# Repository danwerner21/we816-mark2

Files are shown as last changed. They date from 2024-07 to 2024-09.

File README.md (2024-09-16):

# WE816-MARK2
The WE816-MARK2 is the second iteration of a 16-bit 65816 based system with 512K of System RAM, 96K of System ROM, a Raspberry PI Pico based graphics processor and an AY-3-8910 Sound chip.  The system runs a custom version of BASIC and supports commodore compatible IEC disk drives.

EhBASIC by Lee Davison was ported to the 65816 CPU on the WE816 computer.   It is designed to allow a full 64K bank for BASIC code and variables with the BASIC interpreter running in a totally different bank. Full documentation on the basic intrepreter can be found in the support folder

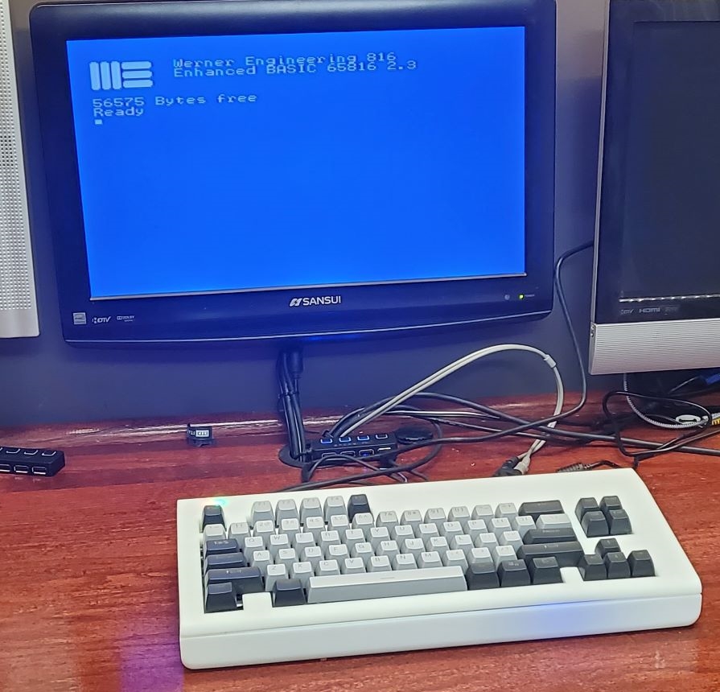
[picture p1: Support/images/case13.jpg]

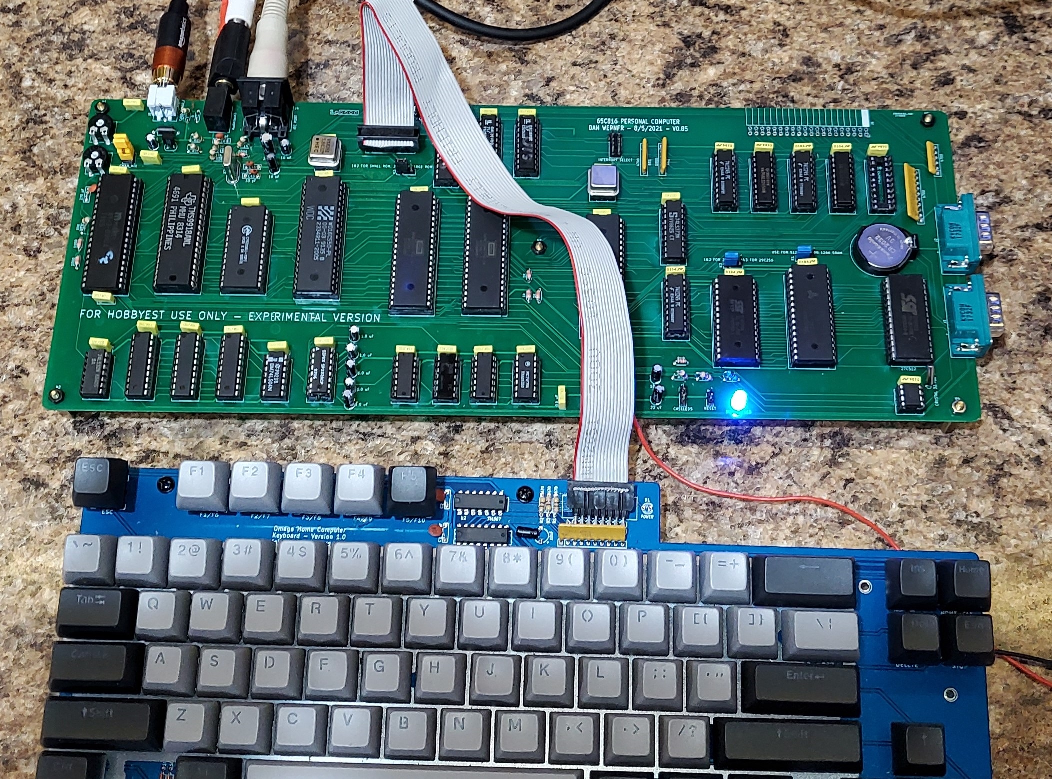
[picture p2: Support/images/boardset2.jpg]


---

## Bugs:
* V0.08 board
        U13 should be a 22V10 rather than a 20V8  (no patches required)
        U31 should be 74ALS245 rather than 74AC245 (no patches required)
        The Footprints for the expansion(J7) and Keyboard(J3) connectors are wrong -- special cables are required to connect this version to keyboard and expansion
        RTC IS STILL BROKEN, DO NOT POPULATE U7,U8,X3,C36,C37,C34,R1,R2,R3,U9,BT1,K4,JP1, & JP2

* V0.9 board
        U16 should not be populated -- the wait state generator is not functional, maximum successful tested clock speed is 2.4576 Mhz
        Higher CPU speeds are possible, but the video will not function at much beyond this speed.

## To Do:
* Document Jumper Settings
* Document IO Ports
* Memory Map
* Video speed is not fast enough to deal with a clock speed > (around) 2mhz (2.4576 works perfectly)  Need to add wait state hardware for video
* Add Pictures to this Document
---

## What is included in this repo?
As of this time, the repo includes

1. The WE816-Mark2 Mainboard PCB Kicad design and Gerber files
2. The source code and binaries for the WE816 BASIC interpreter
3. The source code and binaries for the WE816 BIOS firmware
4. The source code and binaries for several hardware test programs
5. The logic equasions for the 4 GALs
6. **OpenSCAD and STL files for a 3d printed case
7. The Firmware for the Raspberry Pi Pico Video  

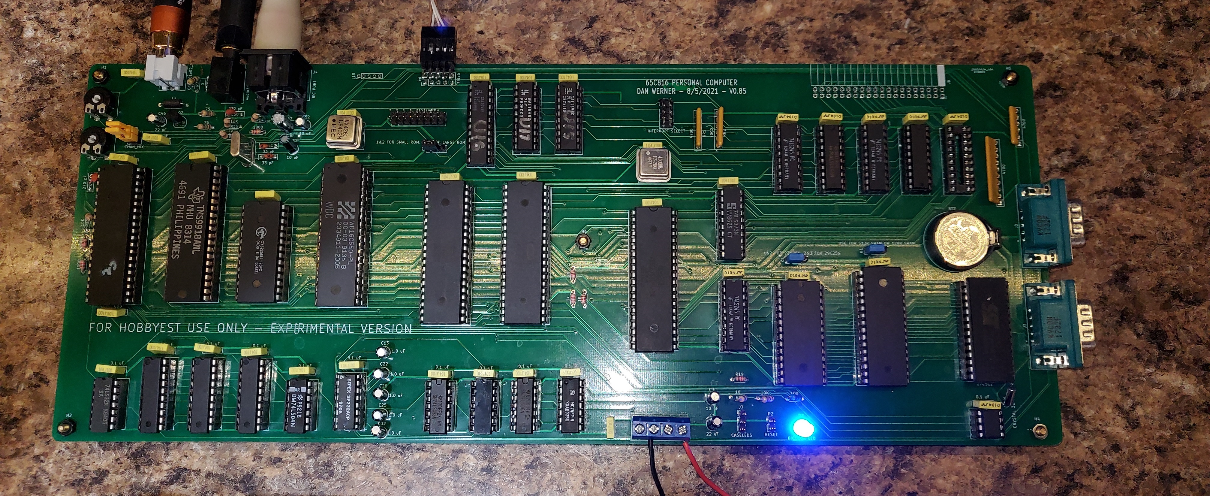
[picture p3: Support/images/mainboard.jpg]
Mainboard

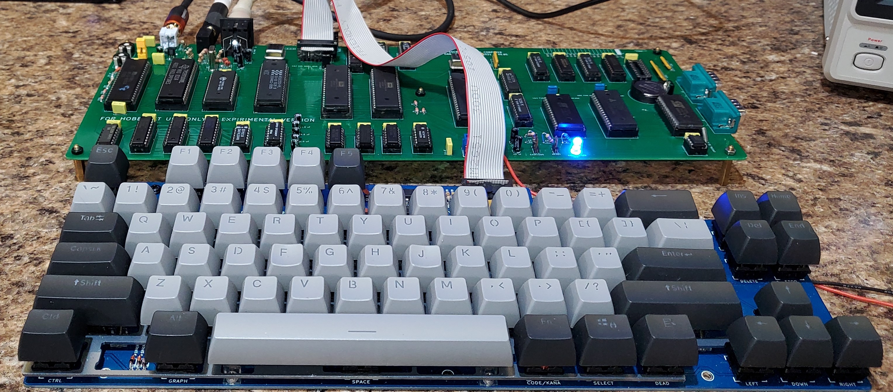
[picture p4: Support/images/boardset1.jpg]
Assembled


---

## Known Bugs

### System Jumpers

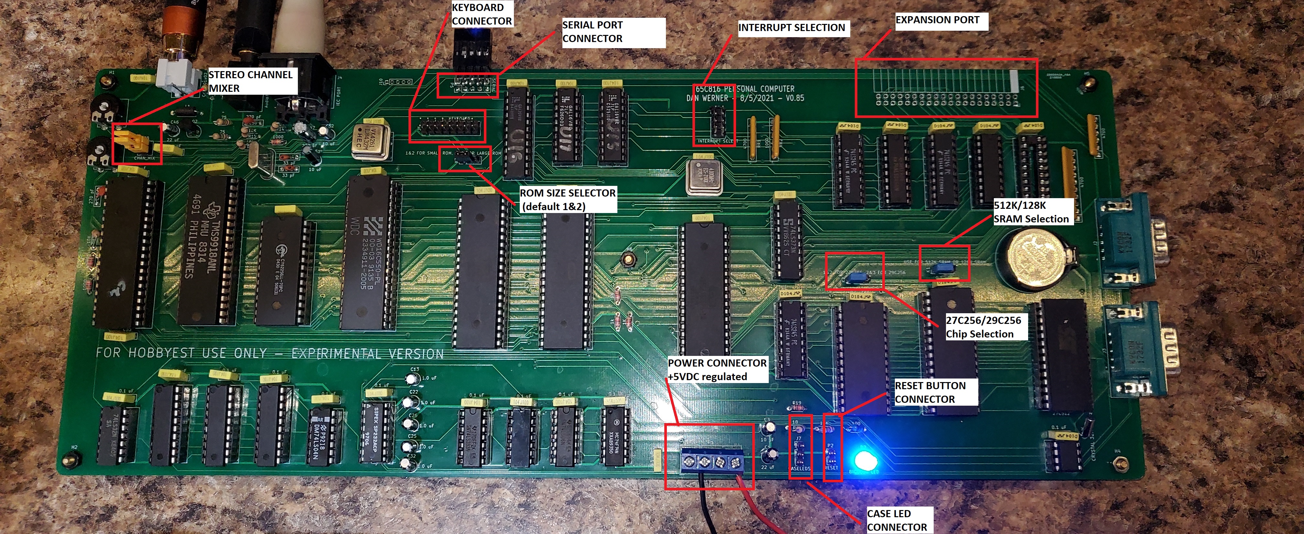
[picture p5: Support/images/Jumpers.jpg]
jumpers


Jumper P9 -- stereo channel mixer

 *  no jumpers, channel a left, channel c right, channel b left and right
 *  1-2 and 2-3 , channel a,b,c mixed to left and right

Jumper K1 - SRAM chip selection

 * 1&2 - 512K chip used (AS6C4008)
 * 2&3 - 128K chip used (AS6C1008)

Jumper K2 - ROM chip selection

 * 1&2 - 27c256 chip used
 * 2&3 - 29c256 chip used

Jumper K3 - ROM size

 * 1&2 - 16K rom page 0 memory map @ $C000
 * 2&3 - 32K rom page 0 memory map @ $8000

Power P1

 * 1- NC
 * 2-GND
 * 3-GND
 * 4-+5VDC 2A Regulated

Reset P2

 * NO Switch (Short to put system in reset)

Jumper J1, Interrupt Select

* 1&8 UART Interrupt enabled
* 2&7 VIA 1 Interrupt enabled
* 3&6 VIA 2 Interrupt enabled
* 4&5 TMS9918 Interrupt enabled

interrupt

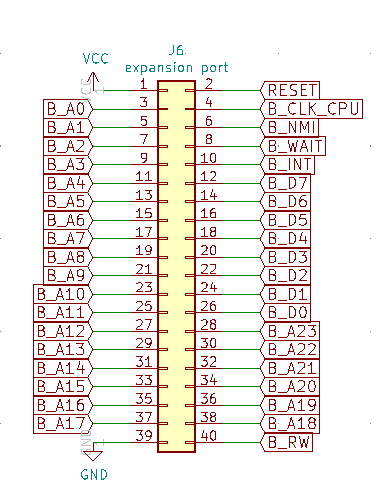
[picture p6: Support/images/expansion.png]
expansion


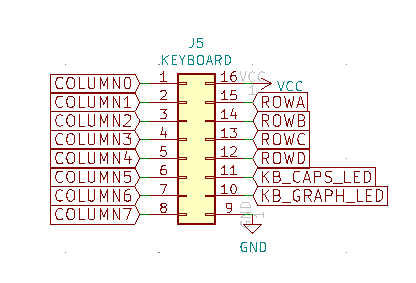
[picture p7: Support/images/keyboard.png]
keyboard


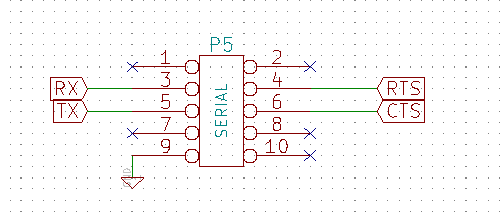
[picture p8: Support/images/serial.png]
serial


---

## Video Programming
IO PORTS

Address|Description|Value|Value
--------|--------|----------|--------
$fe30 | Scan Line Emulation | on | off
$fe31 | Display Page | page 0 | page 1
$fe32 | character generator write offset | write offset |
$fe33 | character generator write | Value |
$fe34 | device command  | Command |
$fe35 | Text Mode  | on | off
$fe36 | Lores Mode  | on | off
$fe37 | Double Lores Mode (must be in lores first)  | on | off
$fe38 | Hires Mode | on | off
$fe39 | Double Hires Mode (must be in hires first)  | on | off
$fe3A | 80 Col Mode (must be in text mode)  | on | off
$fe3b | Mixed Mode   (must be in lores/hires first) | on | off
$fe3c | Quad Hires  (must be in hires first) | on | off
$fe3d | Mono Hires  (must be in hires first)| on | off

## Bill Of Materials

### Mainboard

Qty|Reference(s)|Value
--------|--------|----------

### Keyboard
The Keyboard used in the WE816 is identical to the keyboard used in Sergey Kiselev's MSX compatible OMEGA computer.  See the Schematics, PCB layout and build instructions
[here](https://github.com/skiselev/omega/blob/master/Keyboard.md)

### Case
The case in the following images is a 3D print manufactured by the 3D print service offered by JLCPCB.com.  The case was originally designed to be 3D printed by a FDM printer such as the Anycubic Chiron.   It was originally intended that threaded inserts be melted into the stand off posts so the diameter of the holes were sized accordingly.  If a printing service (such as JLCPCB) is used that uses resin printing, it is necessary to slightly drill out the holes in the stand offs so that threaded inserts can be glued in.   It should also be noted that the design tolerances are quite tight and variations in printing can mean that some slight adjusting may be needed in order to get a good fit.

A 12V to 5V converter can be seen in the image that was added into the case in order to convert the 12V power input to the 5B required by the main board.

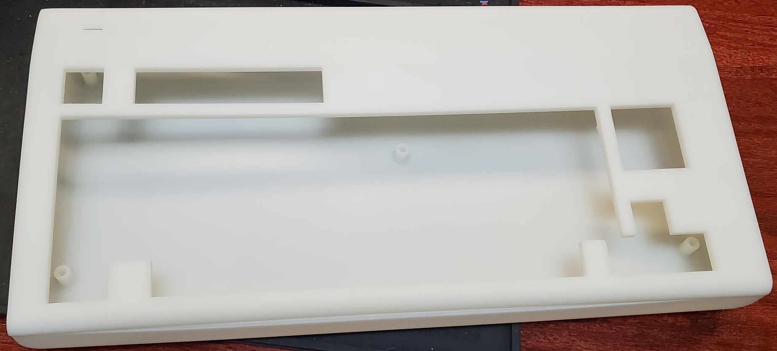
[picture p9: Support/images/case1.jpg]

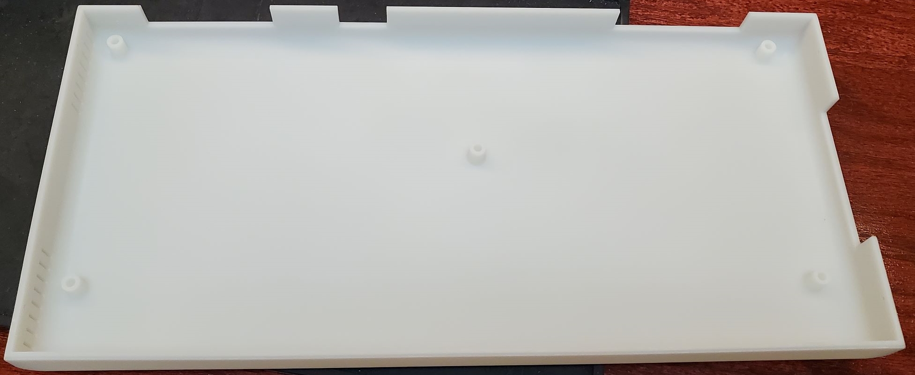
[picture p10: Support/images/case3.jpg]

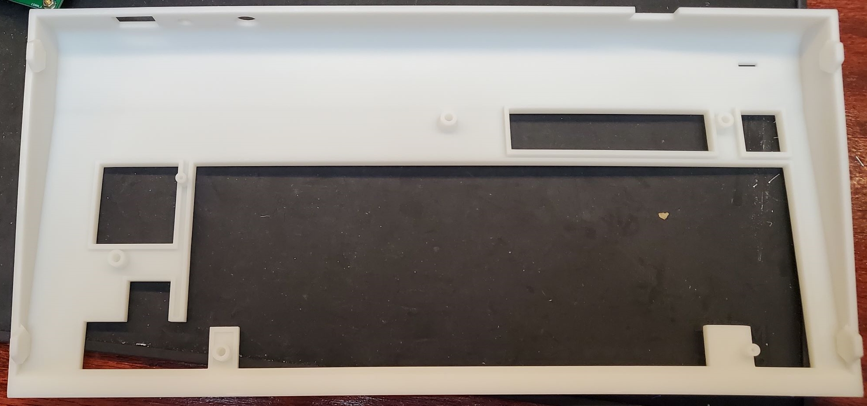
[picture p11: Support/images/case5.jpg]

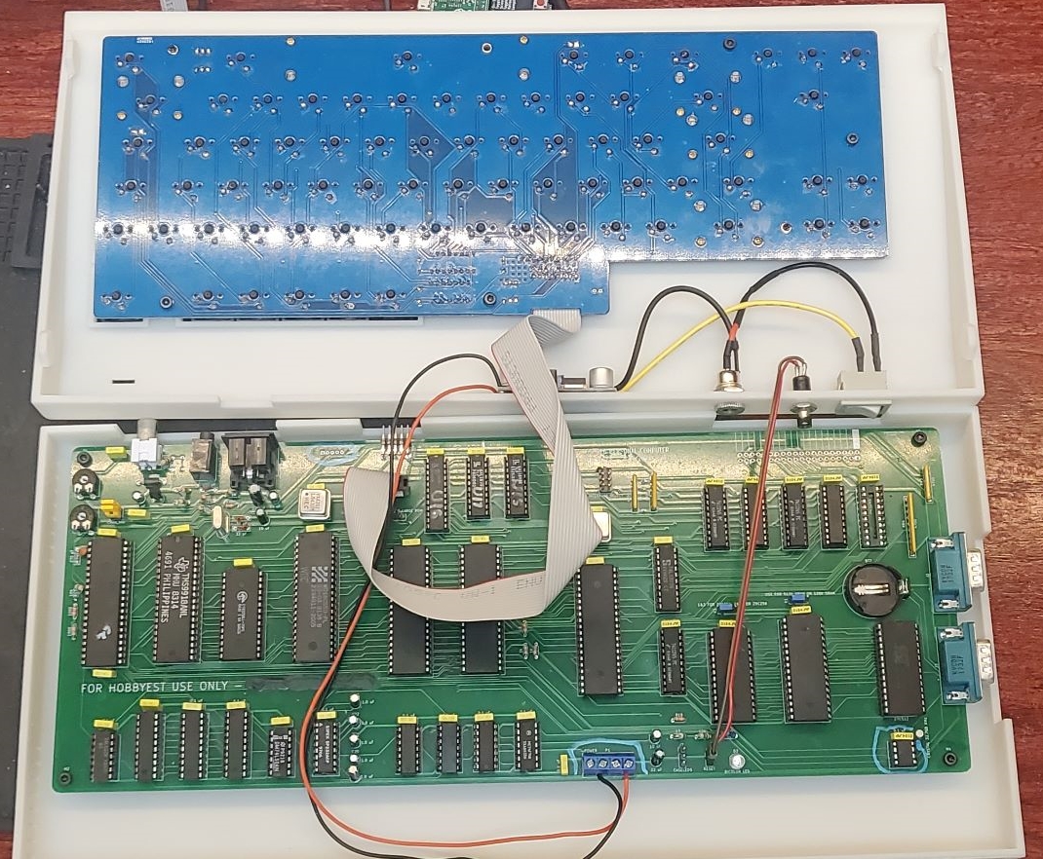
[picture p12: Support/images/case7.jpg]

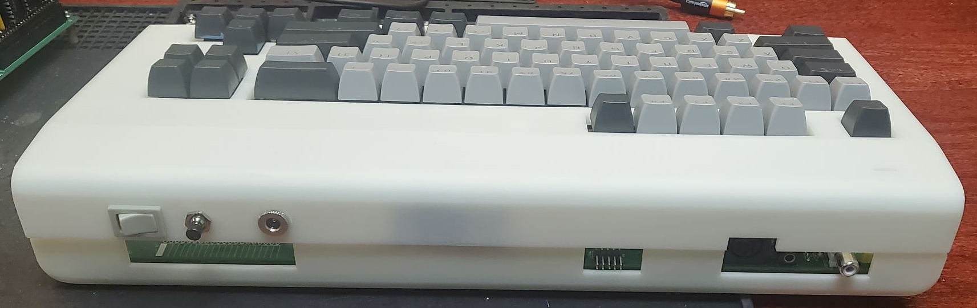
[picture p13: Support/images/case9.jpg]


### Questions?

If there are any questions, I can be reached at vic2020Dan at gmail dot com.

---

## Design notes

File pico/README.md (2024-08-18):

## This work is derived from the AppleII VGA project located here: https://github.com/markadev/AppleII-VGA
## Many thanks to Mark Aikens and David Kuder for their work on this project

# Set Up Raspberry Pi Pico SDK and build the firmware

## Windows Subsystem for Linux (WSL)
Windows Subsystem for Linux (WSL) allows you to install a complete Ubuntu terminal environment in minutes on your Windows machine, allowing you to develop cross-platform applications without leaving Windows. [Install Ubuntu on WSL for Windows](https://ubuntu.com/tutorials/install-ubuntu-on-wsl2-on-windows-10#1-overview)

## Install development packages
```shell
sudo apt update
sudo apt install -y build-essential git cmake gcc-arm-none-eabi
```

## Download the Pico SDK
```shell
git clone https://github.com/raspberrypi/pico-sdk.git ~/pico-sdk
git -C ~/pico-sdk submodule update --init
export PICO_SDK_PATH=~/pico-sdk
```

## Build the firmware 
```shell
cd pico
mkdir build
cd build
cmake  ..
make
## Install the firmware
Hold down the BOOTSEL button and connect the Raspberry Pi Pico to your PC via micro USB cable. Once Pico is
connected release the BOOTSEL button. Pi Pico should be connected to PC with USB mass storage device mode.

A disk volume called RPI-RP2 will appear on your computer. Drag and drop the applevga.uf2 file to that volume.
RPI-RP2 will unmount and Pico will start the program.

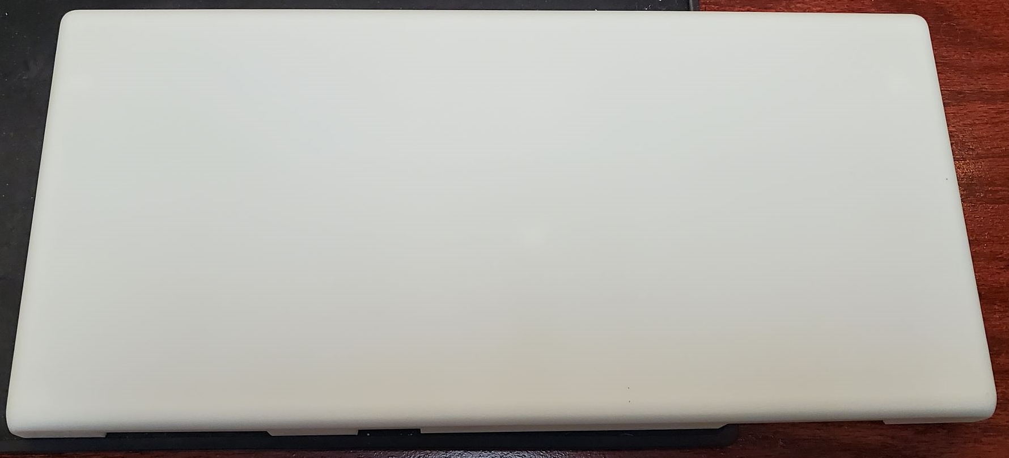
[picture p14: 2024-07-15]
Support/images/case4.jpg

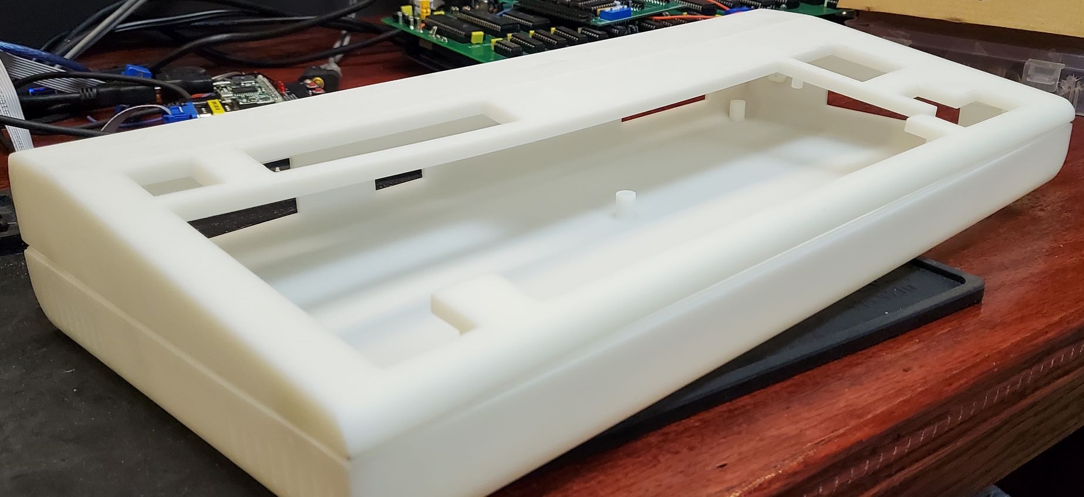
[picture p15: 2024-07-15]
Support/images/case2.jpg

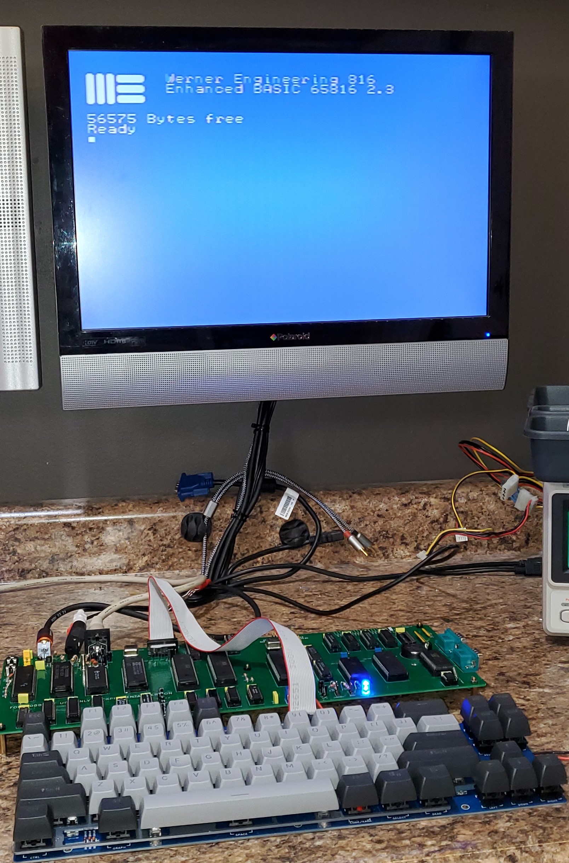
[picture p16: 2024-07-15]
Support/images/bare_system.jpg

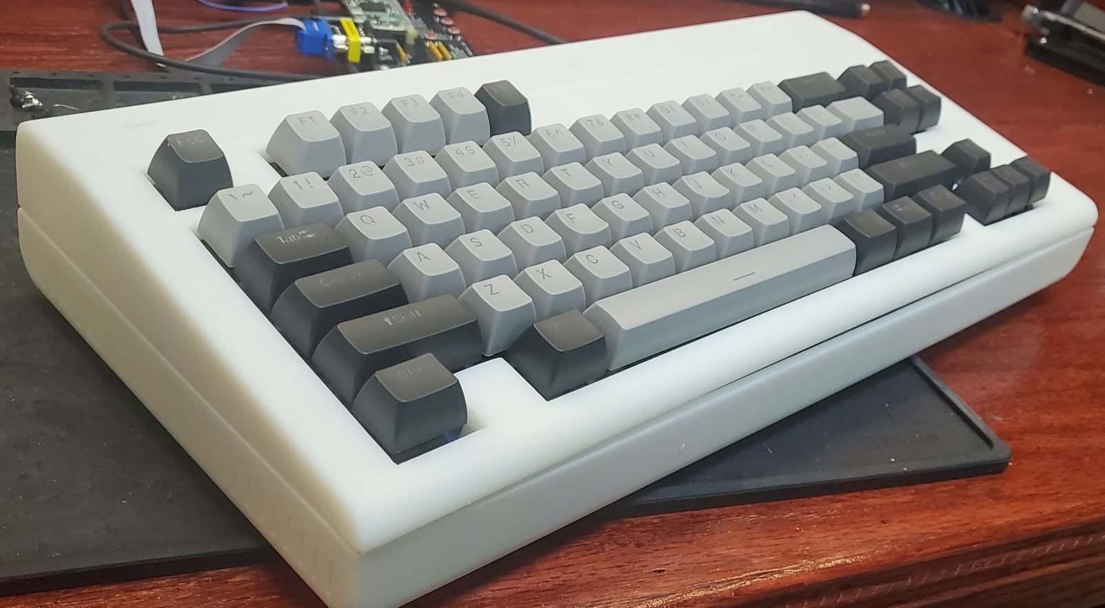
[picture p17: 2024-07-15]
Support/images/case10.jpg

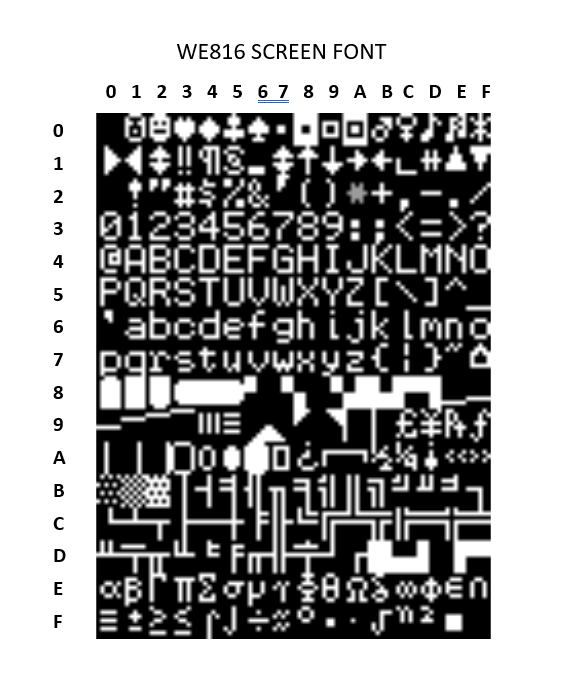
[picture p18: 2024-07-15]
Support/images/font.png

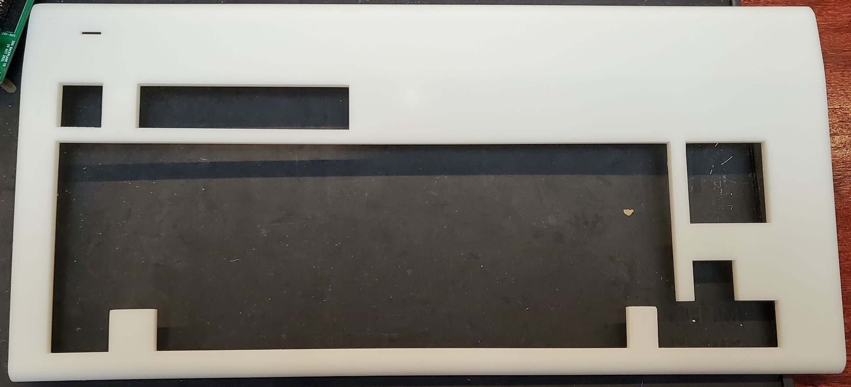
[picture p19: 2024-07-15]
Support/images/case6.jpg

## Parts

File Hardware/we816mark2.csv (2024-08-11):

Source: | N:\Projects\we816-mark2\Hardware\we816mark2.kicad_sch
Date: | 8/9/2024 2:56:26 PM
Tool: | Eeschema 7.0.1
Generator: | C:\Program Files\KiCad\7.0\bin\scripting\plugins/bom_csv_grouped_by_value_with_fp.py
Component Count: | 146
Ref | Qnty | Value | Cmp name | Footprint | Description | Vendor | DNP
BT1 | 1 | Battery_Cell | Battery_Cell | CUSTOMLibrary:Battery_Holder_Coin_2032_BS-7_FIXED | Single-cell battery
C1, C2, C3, C4, C5, C6, C7, C8, C9, C10, C11, C12, C13, C14, C15, C16, C17, C18, C19, C20, C21, C22, C23, C24, C25, C26, C27, C28, C29, C30, C31, C32, C33, C49 | 34 | 0.1 µF | C_Small | Capacitor_THT:C_Rect_L7.0mm_W2.0mm_P5.00mm | Unpolarized capacitor, small symbol
C34 | 1 | 30 pF | C_Trim_Small | Capacitor_THT:CP_Radial_D4.0mm_P2.00mm | Trimmable capacitor, small symbol
C35 | 1 | 22 µF | C_Polarized_Small | Capacitor_THT:CP_Radial_D4.0mm_P2.00mm | Polarized capacitor, small symbol
C36, C37 | 2 | 33 pF | C_Small | Capacitor_THT:C_Rect_L7.0mm_W2.0mm_P5.00mm | Unpolarized capacitor, small symbol
C39, C40, C41, C42, C43 | 5 | 1.0µF | C_Polarized_Small | Capacitor_THT:CP_Radial_D4.0mm_P2.00mm | Polarized capacitor, small symbol
C44, C45 | 2 | 270 pF | C_Small | Capacitor_THT:C_Rect_L7.0mm_W2.0mm_P5.00mm | Unpolarized capacitor, small symbol
C46, C47 | 2 | 10 µF | C_Polarized_Small | Capacitor_THT:CP_Radial_D4.0mm_P2.00mm | Polarized capacitor, small symbol
D1 | 1 | BICOLOR LED | LED_Small | LED_THT:LED_D5.0mm | Light emitting diode, small symbol
H1, H2, H3, H4, H5 | 5 | MountingHole | MountingHole | MountingHole:MountingHole_3.2mm_M3 | Mounting Hole without connection
J1 | 1 | AudioJack3 | AudioJack3 | Connector_Audio:Jack_3.5mm_CUI_SJ1-3533NG_Horizontal_CircularHoles | Audio Jack, 3 Poles (Stereo / TRS)
J2 | 1 | TTL Serial | Conn_01x06_Pin | Connector_PinHeader_2.54mm:PinHeader_1x06_P2.54mm_Vertical | Generic connector, single row, 01x06, script generated
J3 | 1 | KEYBOARD | Conn_02x08_Counter_Clockwise | Connector_PinHeader_2.54mm:PinHeader_2x08_P2.54mm_Vertical | Generic connector, double row, 02x08, counter clockwise pin numbering scheme (similar to DIP package numbering), script generated (kicad-library-utils/schlib/autogen/connector/)
J4 | 1 | IEC PORT | DIN-5 | CUSTOMLibrary:din6 | 5-pin DIN connector
J5 | 1 | CASELEDS | Conn_01x03_Pin | Connector_PinHeader_2.54mm:PinHeader_1x03_P2.54mm_Vertical | Generic connector, single row, 01x03, script generated
J6 | 1 | INTERRUPT SELECT | Conn_02x03_Counter_Clockwise | Connector_PinHeader_2.54mm:PinHeader_2x04_P2.54mm_Vertical | Generic connector, double row, 02x03, counter clockwise pin numbering scheme (similar to DIP package numbering), script generated (kicad-library-utils/schlib/autogen/connector/)
J7 | 1 | expansion port | Conn_02x20_Odd_Even | Connector_PinSocket_2.54mm:PinSocket_2x20_P2.54mm_Horizontal | Generic connector, double row, 02x20, odd/even pin numbering scheme (row 1 odd numbers, row 2 even numbers), script generated (kicad-library-utils/schlib/autogen/connector/)
J9, J10 | 2 | DB9_Male | DE9_Plug | Connector_Dsub:DSUB-9_Male_Horizontal_P2.77x2.84mm_EdgePinOffset9.90mm_Housed_MountingHolesOffset11.32mm | 9-pin male plug pin D-SUB connector
J11 | 1 | DE15_Receptacle_HighDensity | DE15_Receptacle_HighDensity | Connector_Dsub:DSUB-15-HD_Female_Horizontal_P2.29x1.98mm_EdgePinOffset3.03mm_Housed_MountingHolesOffset4.94mm | 15-pin female receptacle socket D-SUB connector, High density (3 columns), Triple Row, Generic, VGA-connector
JP1, JP2 | 2 | BYPASS | Jumper_2_Open | Connector_PinHeader_2.54mm:PinHeader_1x02_P2.54mm_Vertical | Jumper, 2-pole, open
K1 | 1 | 1&2 FOR SMALL ROM, 2&3 FOR LARGE ROM | Conn_01x03_Pin | Connector_PinHeader_2.54mm:PinHeader_1x03_P2.54mm_Vertical | Generic connector, single row, 01x03, script generated
K2 | 1 | USE FOR 512K SRAM OR 128K SRAM | Conn_01x03_Pin | Connector_PinHeader_2.54mm:PinHeader_1x03_P2.54mm_Vertical | Generic connector, single row, 01x03, script generated
K3 | 1 | 1&2 FOR 27C256, 2&3 FOR 29C256 | Conn_01x03_Pin | Connector_PinHeader_2.54mm:PinHeader_1x03_P2.54mm_Vertical | Generic connector, single row, 01x03, script generated
K4 | 1 | VCC TOL 0 | Conn_01x03 | Connector_PinHeader_2.54mm:PinHeader_1x03_P2.54mm_Vertical | Generic connector, single row, 01x03, script generated (kicad-library-utils/schlib/autogen/connector/)
P1 | 1 | SERIAL | Conn_02x05_Odd_Even | Connector_PinHeader_2.54mm:PinHeader_2x05_P2.54mm_Vertical | Generic connector, double row, 02x05, odd/even pin numbering scheme (row 1 odd numbers, row 2 even numbers), script generated (kicad-library-utils/schlib/autogen/connector/)
P2 | 1 | CHAN_MIX | Conn_02x02_Odd_Even | Connector_PinHeader_2.54mm:PinHeader_2x02_P2.54mm_Vertical | Generic connector, double row, 02x02, odd/even pin numbering scheme (row 1 odd numbers, row 2 even numbers), script generated (kicad-library-utils/schlib/autogen/connector/)
P3 | 1 | POWER | Screw_Terminal_01x02 | TerminalBlock_RND:TerminalBlock_RND_205-00001_1x02_P5.00mm_Horizontal | Generic screw terminal, single row, 01x02, script generated (kicad-library-utils/schlib/autogen/connector/)
P4 | 1 | RESET | Conn_01x02_Pin | Connector_PinHeader_2.54mm:PinHeader_1x02_P2.54mm_Vertical | Generic connector, single row, 01x02, script generated
P5 | 1 | CLK_CPU | CXO_DIP8 | Oscillator:Oscillator_DIP-8 | Crystal Clock Oscillator, DIP8-style metal package
R1, R2, R3 | 3 | 100kΩ | R_Small | Resistor_THT:R_Axial_DIN0204_L3.6mm_D1.6mm_P5.08mm_Horizontal | Resistor, small symbol
R4 | 1 | 10Ω | R_Small | Resistor_THT:R_Axial_DIN0204_L3.6mm_D1.6mm_P5.08mm_Horizontal | Resistor, small symbol
R5, R6, R7, R8, R9, R10, R17, R18, R19 | 9 | 1KΩ | R_Small | Resistor_THT:R_Axial_DIN0204_L3.6mm_D1.6mm_P5.08mm_Horizontal | Resistor, small symbol
R11, R12, R13, R14 | 4 | 10KΩ | R_Small | Resistor_THT:R_Axial_DIN0204_L3.6mm_D1.6mm_P5.08mm_Horizontal | Resistor, small symbol
R15 | 1 | 100Ω | R_Small | Resistor_THT:R_Axial_DIN0204_L3.6mm_D1.6mm_P5.08mm_Horizontal | Resistor, small symbol
R20, R23, R26 | 3 | 510 | R_Small | Resistor_THT:R_Axial_DIN0204_L3.6mm_D1.6mm_P5.08mm_Horizontal | Resistor, small symbol
R21, R24, R27 | 3 | 1K | R_Small | Resistor_THT:R_Axial_DIN0204_L3.6mm_D1.6mm_P5.08mm_Horizontal | Resistor, small symbol
R22, R25, R28 | 3 | 2K | R_Small | Resistor_THT:R_Axial_DIN0204_L3.6mm_D1.6mm_P5.08mm_Horizontal | Resistor, small symbol
R29, R31 | 2 | 47 | R_Small | Resistor_THT:R_Axial_DIN0204_L3.6mm_D1.6mm_P5.08mm_Horizontal | Resistor, small symbol
RN1 | 1 | 10K | R_Network05 | Resistor_THT:R_Array_SIP6 | 5 resistor network, star topology, bussed resistors, small symbol
RR1 | 1 | 1KΩ | R_Network05 | Resistor_THT:R_Array_SIP6 | 5 resistor network, star topology, bussed resistors, small symbol
RR2, RR3 | 2 | 4700Ω | R_Network05 | Resistor_THT:R_Array_SIP6 | 5 resistor network, star topology, bussed resistors, small symbol
RR4 | 1 | 4700Ω | R_Network09 | Resistor_THT:R_Array_SIP10 | 9 resistor network, star topology, bussed resistors, small symbol
RV1, RV2 | 2 | 4700Ω | R_Potentiometer_Trim | Potentiometer_THT:Potentiometer_ACP_CA9-V10_Vertical | Trim-potentiometer
U1, U5 | 2 | W65C22NxP | 65C22 | Package_DIP:DIP-40_W15.24mm_Socket
U2 | 1 | 7406 | 74LS06N | Package_DIP:DIP-14_W7.62mm_Socket | Inverter Open Collect
U3 | 1 | 74LS06N | 74LS06N | Package_DIP:DIP-14_W7.62mm_Socket | Inverter Open Collect
U4 | 1 | 74LS14 | 74LS14 | Package_DIP:DIP-14_W7.62mm_Socket_LongPads | Hex inverter schmitt trigger
U6, U12, U14 | 3 | GAL16V8 | GAL16V8 | Package_DIP:DIP-20_W7.62mm_Socket_LongPads | Programmable Logic Array, DIP-20/SOIC-20/PLCC-20
U7 | 1 | ~ | rp5c01 | Package_DIP:DIP-18_W7.62mm_Socket_LongPads
U8 | 1 | 74LS175 | 74LS175 | Package_DIP:DIP-16_W7.62mm_Socket_LongPads | 4-bit D Flip-Flop, reset
U9 | 1 | DS1210 | DS1210 | Package_DIP:DIP-8_W7.62mm | Nonvolatile Controller, PDIP-8
U10 | 1 | 74AC04 | 74HC04 | Package_DIP:DIP-14_W7.62mm_Socket_LongPads | Hex Inverter
U11 | 1 | 658C16 | 65C816 | Package_DIP:DIP-40_W15.24mm_Socket
U13 | 1 | GAL20V8 | PAL20L8 | Package_DIP:DIP-24_W7.62mm_Socket_LongPads | Programmable Logic Array, DIP-24
U15 | 1 | 16550 | 16550 | Package_DIP:DIP-40_W15.24mm | PC16550D, Universal Asynchronous Receiver/Transmitter with FIFOs, PDIP-40
U17 | 1 | MAX232 | MAX232 | Package_DIP:DIP-16_W7.62mm_Socket_LongPads | Dual RS232 driver/receiver, 5V supply, 120kb/s, 0C-70C
U20, U22, U23, U24 | 4 | 74LS245 | 74LS245 | Package_DIP:DIP-20_W7.62mm_Socket_LongPads | Octal BUS Transceivers, 3-State outputs
U21 | 1 | 74LS244 | 74LS244 | Package_DIP:DIP-20_W7.62mm_Socket_LongPads | Octal Buffer and Line Driver With 3-State Output, active-low enables, non-inverting outputs
U25 | 1 | AY-3-8910 | YM2149 | Package_DIP:DIP-40_W15.24mm | Software-Controlled Sound Generator, DIP-40
U26 | 1 | SRAM_512KO | AS6C4008-55PCN | Package_DIP:DIP-32_W15.24mm | 512K x 8 Low Power CMOS RAM, DIP-32
U28 | 1 | 27C256 | 27C256 | Package_DIP:DIP-28_W15.24mm | OTP EPROM 256 KiBit
U29 | 1 | 27C512 | 27C512 | Package_DIP:DIP-28_W15.24mm | OTP EPROM 512 KiBit
U30 | 1 | 74AC373 | 74LS373 | Package_DIP:DIP-20_W7.62mm_Socket_LongPads | 8-bit Latch, 3-state outputs
U31 | 1 | 74AC245 | 74LS245 | Package_DIP:DIP-20_W7.62mm_Socket_LongPads | Octal BUS Transceivers, 3-State outputs
U32, U33, U34 | 3 | 74LVC245 | 74LS245 | Package_DIP:DIP-20_W7.62mm_Socket_LongPads | Octal BUS Transceivers, 3-State outputs
U35 | 1 | LM3940 | LM2937xT | Package_TO_SOT_THT:TO-220-3_Vertical | 500-mA Low Dropout Regulator, TO-220
U36 | 1 | Pico | Pico | RPi:RPi_Pico_SMD_TH
U37 | 1 | DS1233 | Conn_01x03 | Package_TO_SOT_THT:TO-92L_HandSolder | Generic connector, single row, 01x03, script generated (kicad-library-utils/schlib/autogen/connector/)
X2 | 1 | CXO_DIP8 | CXO_DIP8 | Oscillator:Oscillator_DIP-8 | Crystal Clock Oscillator, DIP8-style metal package
X3 | 1 | CRYSTAL 32.768 KHz | Crystal | Crystal:Crystal_Round_D1.5mm_Vertical | Two pin crystal

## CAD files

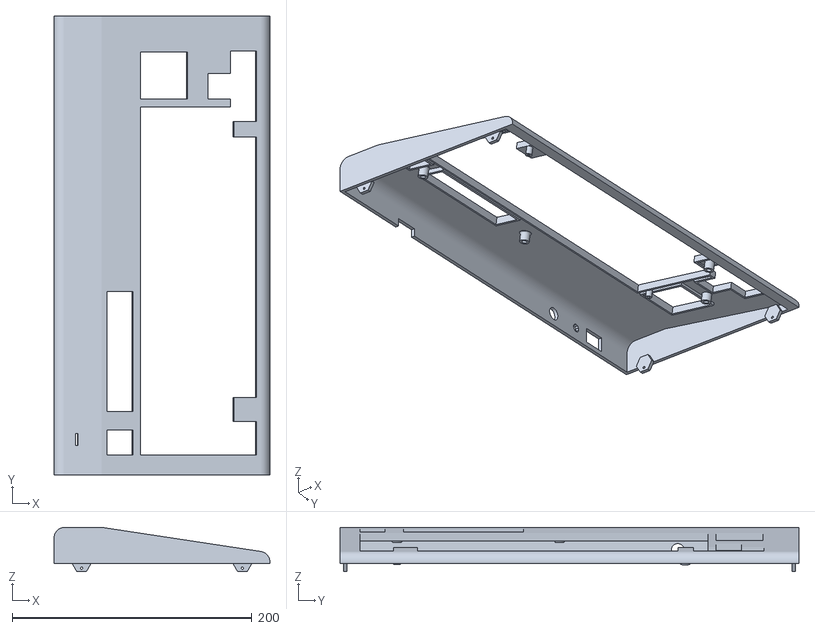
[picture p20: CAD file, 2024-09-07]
Support/WE816case_top.stl
180.0 x 382.5 x 36.9

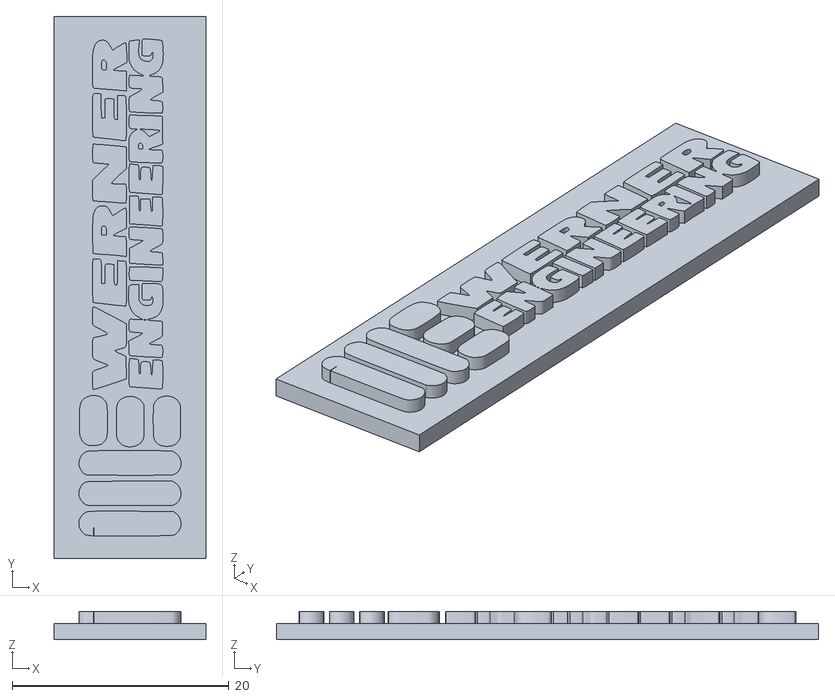
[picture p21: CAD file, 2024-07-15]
Support/WE816case_logo.stl
14.0 x 50.0 x 2.60

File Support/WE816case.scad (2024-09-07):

/* [Box dimensions] */
  Length        = 180;       
  Width         = 385;                     
  TopHeight        = 10;  
  BottomHeight     = 21;  
  SlopeHeight      = 20;
  Thick         = 3;//[2:5]  


  
/* [Box options] */
  PCBFeet       = 1;// [0:No, 1:Yes]
  Vent          = 1;// [0:No, 1:Yes]
  Vent_width    = 1.5;   



  Filet         = 9;//[0.1:12] 
  Resolution    = 50;//[1:100] 
  m             = 0.9;
  
/* [PCB_Feet--the_board_will_not_be_exported) ] */
PCBPosX         = 0;
PCBPosY         = 0;
PCBLength       = 142;
PCBWidth        = 360;
FootHeight      = 5;
FootDia         = 8;
FootHole        = 4.4;  
  

/* [STL element to export] */
//Top shell
  TShell        = 0;// [0:No, 1:Yes]
//Bottom shell
  BShell        = 0;// [0:No, 1:Yes]
// logo plate  
  RLogo         = 1;// Logo


  
/* [Hidden] */
Couleur1        = "Orange";       
Couleur2        = "OrangeRed";    
Dec_Thick       = Vent ? Thick*2 : Thick; 
Dec_size        = Vent ? Thick*2 : 0.8;

PCBL=PCBLength;
PCBW=PCBWidth;



   
module SlopeRoundBox($a=Length, $b=Width, $c=TopHeight+BottomHeight){
                    $fn=Resolution;     
                         
                        translate([Filet,-Filet/2,Filet])
                        {  
                    minkowski ()
                    {  
              
                    translate([0,($b/2)+1,TopHeight])
                       rotate(a=[0,-90,90])
                          linear_extrude(height =(($b/2)-Filet/2)+1, center = false, convexity = 0, twist = 0)
                              polygon(points=[[0,0],[(SlopeHeight+TopHeight)*-1,0],[(SlopeHeight+TopHeight)*-1,-30],  [TopHeight*-1,($a-Filet*2)*-1],[0,($a-Filet*2)*-1]], paths=[[3,2,1,0]]);                      
                        
                     rotate([270,0,0]){    
                        cylinder(r=Filet,h=Width/2+1, center = false);
                            } 
                        }
                    }
                }// End of SlopeRoundBox Module                


module RoundBox($a=Length, $b=Width, $c=TopHeight+BottomHeight){
                    $fn=Resolution;            
                    translate([0,Filet,Filet]){  
                    minkowski (){                                              
                        cube ([$a-(Length/2),$b-(2*Filet),$c-(2*Filet)], center = false);
                        rotate([0,90,0]){   
                           translate([0,0,Filet]){  
                        cylinder(r=Filet,h=Length/2-(2*Filet), center = false);}
                            } 
                        rotate([270,0,0]){    
                        cylinder(r=Filet,h=.1, center = false);
                            } 
                        }
                    }
                }// End of RoundBox Module

      


module TopShell(){
    Thick = Thick*2;  
    difference(){    
        difference(){
            union(){    
                     difference() {
                      
                        difference(){
                            union() {
                                        KeyboardCutoutReinforcement();

                            difference(){
                                SlopeRoundBox();
                                translate([Thick/2,Thick/2,Thick/2]){     
                                        SlopeRoundBox($a=Length-Thick*2, $b=Width-Thick*2, $c=TopHeight+BottomHeight-Thick);
                                        }
                                        }
                                    }
                               translate([-Thick,-Thick,TopHeight]){
                                   cube ([Length+100, Width+100, TopHeight+BottomHeight], center=false);
                                            }                                            
                                      }
                                }                                          

                difference(){
                    union(){
                        translate([3*Thick +5,Thick,TopHeight]){
                            rotate([90,0,0]){
                                    $fn=6;
                                    cylinder(d=16,Thick/2);
                                    }   
                            }
                            
                       translate([Length-((3*Thick)+5),Thick,TopHeight]){
                            rotate([90,0,0]){
                                    $fn=6;
                                    cylinder(d=16,Thick/2);
                                    }   
                            }

                    translate([3*Thick +5,Width-Thick/2-2.4,TopHeight]){
                            rotate([90,0,0]){
                                    $fn=6;
                                    cylinder(d=16,Thick/2);
                                    }   
                            }
                            
                       translate([Length-((3*Thick)+5),Width-Thick/2-2.4,TopHeight]){
                            rotate([90,0,0]){
                                    $fn=6;
                                    cylinder(d=16,Thick/2);
                                    }   
                            }


                        }
                            
                    } 
                    
                    
            }

       }


///Put Difference Keyboard Cutout Here

            union(){ //sides holes
                $fn=50;
                translate([3*Thick+5,20,TopHeight+4]){
                    rotate([90,0,0]){
                    cylinder(d=2,20);
                    }
                }
                translate([Length-((3*Thick)+5),20,TopHeight+4]){
                    rotate([90,0,0]){
                    cylinder(d=2,20);
                    }
                }
                translate([3*Thick+5,Width+5,TopHeight+4]){
                    rotate([90,0,0]){
                    cylinder(d=2,20);
                    }
                }
                translate([Length-((3*Thick)+5),Width+5,TopHeight+4]){
                    rotate([90,0,0]){
                    cylinder(d=2,20);
                    }
                }
            }//fin de sides holes

         // IEC Opening    
            translate([-1,(Thick)+281,Thick-3]){
              cube([21,21,BottomHeight-7]);
            }   

         // Power Switch Opening    
            translate([-1,(Thick)+31,Thick-13]){
              cube([13,20,13]);
            }   


         // Reset Switch Opening    
            translate([-1,(Thick)+65,Thick-7]){
             rotate([0,90,0])
                    cylinder(d=7,20);
            }   


        // Power Jack Opening    
            translate([-1,(Thick)+95,Thick-7]){
             rotate([0,90,0])
                    cylinder(d=11,20);
            }   

        KeyboardCutout();

        }//fin de difference holes
        KeyboardFeet();
        

        
        

}// fin coque 





module BottomShell(){
    Thick = Thick*2;  
    translate([0,2,0]){
    
    difference(){    
        difference(){
            //Main Box
            union(){    
                     difference() {
                      
                        difference(){
                            union() {
                            difference(){
                                RoundBox($a=Length, $b=Width-2, $c=TopHeight+BottomHeight);
                                translate([Thick/2,Thick/2,Thick/2]){     
                                        RoundBox($a=Length-Thick, $b=Width-Thick-2, $c=TopHeight+BottomHeight-Thick);
                                        }
                                        }

                                    }
                               translate([-Thick,-Thick,BottomHeight]){// Cube à soustraire
                                   cube ([Length+100, Width+100, TopHeight+BottomHeight], center=false);
                                            }                                            
                                      }
                                }                                          


              
            }

       
            // vent holes
            union(){           
            for(i=[0:Thick:Length/4]){
                    translate([10+i,-Dec_Thick+Dec_size,1]){
                    cube([Vent_width,Dec_Thick,BottomHeight/2]);
                    }
                    translate([(Length-10) - i,-Dec_Thick+Dec_size,1]){
                    cube([Vent_width,Dec_Thick,BottomHeight/2]);
                    }
               
                  }
                }
                
        
            // Joystick Opening    
            translate([53,Width-Dec_size-2,Thick]){    
              cube([75,Dec_Thick+2,BottomHeight-5]);
            }
                

            // expansion Opening    
            translate([-1,(Thick)+270,Thick]){
              cube([12,70,BottomHeight-3]);
            }
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

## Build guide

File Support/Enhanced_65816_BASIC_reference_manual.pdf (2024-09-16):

EhBASIC reference manual | page 1

### Enhanced 65816 BASIC reference manual

Preface

The manual this was based on was compiled in October 2013 from a snapshot of Lee Davison’s website http://mycorner.no-ip.org/6502/ehbasic/index.html after it had been off air for quite a while.

Most of the content of this manual is the sole intellectual property of the original author Lee Davison. See the copyright notice in the introduction, for what you can and what you cannot do with the source code and with the documentation. Conversion to run on the WE816 platform and the associated disk, graphics, and sound commands was done by Dan Werner.

Content

### The original Enhanced 6502 BASIC By Lee Davison

Introduction

Enhanced BASIC is a BASIC interpreter for the 6502 and compatible microprocessors. It is constructed to be quick and powerful and easily ported to most 6502 systems. It requires few resources to run and includes instructions to facilitate easy low level handling of hardware devices. It also retains most of the powerful high level instructions from similar BASICs.

EhBASIC represents hundreds of hours work over nearly three years, lots of frustration, lots of joy and the occasional twinge from RSI induced tendonitis.

EhBASIC is free but not copyright free. For non commercial use there is only one restriction, any derivative work should include, in any binary image distributed, the string "Derived from EhBASIC" and in any distribution that includes human readable files a file that includes the above string in a human readable form e.g. not as a comment in an HTML file.

EhBasic 65C816 Port

EhBASIC was ported to the 65816 CPU on the WE816 computer. It is designed to allow a full 64K bank for BASIC code and variables with the BASIC interpreter running in a totally different bank. Program Bank, Data Bank and Stack parameters can be adjusted in the definitions.asm file included in the archive, and zero page usage can be found in the zeropage.asm file.

### Enhanced BASIC language reference

Numbers

Numbers may range from zero to plus or minus 1.70141173x10^38 and will have an accuracy of just under 1 part in 1.68 x 10^7.

Numbers can be preceded by a sign, + or -, and are written as a string of numeric digits with or without a decimal point and can also have a positive or negative exponent as a power of 10 multiplier e.g.

-142 | 96.3 | 0.25 | -136.42E-3 | -1.3E7 | 1

.. are all valid numbers.

Integer numbers, i.e. with no decimal fraction or exponent, can also be in either hexadecimal or binary. Hexadecimal numbers should be preceded by $ and binary numbers preceded by %, e.g.

%101010 | -$FFE0 | $A0127BD | -%10011001 | %00001010 | $0A

.. again are all valid numbers.

Strings

Strings are any string of printable characters enclosed in a pair of quotation marks. Non printing characters may be converted to single character strings using the CHR$() functions.

"Hello world" | "-136.42E-3" | "+----+----+" | "[Y/n]" | "Y"

Are all valid strings.

Variables

Variables of both numeric and string type are available. String variables are distinguished by the $ suffix. As well as simple variables arrays are also available and these may be either numeric or string and are distinguished by their bracketed indices after the variable name.

Variable names may be any length but only the first two name characters are significant so BL and BLANK will refer to the same variable. The first character must be one of "A" to "Z" or "a" to "z", following characters may also include numbers. E.g.

A | A$ | NAME$ | x2LIM | y | colour | s1 | s2

Variable names are case sensitive so AB, Ab, aB and ab are all separate variables.

Variable names may not contain BASIC keywords. Keywords are only valid in upper case so 'PRINTER' is not allowed (it would be interpreted as PRINT ER) but 'printer' is.

Note that spaces in variable names are ignored so 'print e r', 'print er' and 'pri nter' will all be interpreted the same way.

BASIC Keywords

Here is a list of BASIC keywords. They are only valid when entered in upper case as shown and spaces may not be included in them. So GOTO is a valid BASIC keyword but GO TO is not.

ABS | AND | ASC | ATN | BIN$ | BITCLR
BITSET | BITTST | CALL | CHR$ | CLEAR | CLOSE
COLOR | CON | CONT | COS | DATA | DAY
DEC | DEEK | DEF | DIM | DIRECTORY DISKCMD
DISKSTATUS DO | ELSE | END | EOR | EXP
FN | FOR | FRE | GET# | GET | GOSUB
GOTO | HEX$ | HOUR | IECINPUT | IECOUTPUT IECST
IF | INC | INPUT | INT | LCASE$ | LEFT$
LEN | LET | LIST | LOAD | LOCATE | LOG
LOOP | MAX | MID$ | MIN | MONTH | MONITOR
NEW | NEXT | NOISE | NOT | NULL | OFF
ON | OPEN | OR | PATTERN | PEEK | PI
PLOT | POKE | POS | PRINT | PUT# | READ
REM | RESTORE RETURN | RIGHT$ | RND | RUN
SADD | SAVE | SCNCLR | SCREEN | SECOND | SGN
SIN | SOUND | SPC | SQR | STEP | STOP
STR$ | SWAP | SYS | TAB | TAN | THEN
TO | TONE | UCASE$ | UNTIL | USR | VAL
VARPTR | VOICE | VOLUME | WAIT | WEEKD | WHILE
WIDTH | YEAR | * | + | - | /
<< | = | >> | < | >

Manual Conventions

- Anything in upper case is part of the command/function structure and must be present
- Anything in lower case enclosed in < > is to be supplied by the user
- Anything enclosed in [ ] is optional
- Anything enclosed in { } and separated by | characters are multi choice options
- Any items followed by an ellipsis, ... , may be repeated any number of times
- Any punctuation and symbols, except those above, are part of the structure and must be included
- var is a valid variable name
- var$ is a valid string variable name
- var() is a valid array name
- var$() is a valid string array name
- expression is any expression returning a result
- expression$ is any expression returning a string result
- addr is an integer in the range +/- 16777215 that will be wrapped to the range 0 to 65535
- b is a byte value 0 to 255
- n is an integer in the range 0 to 63999 w is an integer in the range -32768 to 32767
- i is a positive integer value
- r is real number
- +r is a positive value real number (0 is considered positive)
- $ is a string literal

BASIC Commands

BITCLR <addr>,<b>

Clears bit b of address addr. Valid bit numbers are 0, the least significant bit, to 7, the most significant bit. Values outside this range will cause a function call error.

BITSET <addr>,<b>

Sets bit b of address addr. Valid bit numbers are 0, the least significant bit, to 7, the most significant bit. Values outside this range will cause a function call error.

CALL <addr>

CALLs a user subroutine at address addr. No values are passed or returned and so this is much faster than using USR(). See extending CALL for details.

CLEAR

Erases all variables and functions and resets FOR .. NEXT, GOSUB .. RETURN and DO ..LOOP states.

CLOSE <Logical file b>

Close IEC logical File <b>. See Working with Files for more information.

COLOR <background b>,<foreground b>

Sets the background and foreground colors on the text screen.

0 | Black
1 | Green
2 | Blue
3 | Cyan
4 | Red
5 | Magenta
6 | Brown
7 | Gray
8 | Dark Gray
9 | Bright Blue
10 | Bright Green
11 | Bright Cyan
12 | Bright Red
13 | Bright Magenta
14 | Yellow
15 | White

CONT

Continues program execution after CTRL-C has been typed, a STOP has been encountered during program execution or a null input was given to an INPUT request.

DATA [{r|$}[,{r|$}]...]

Defines a constant or series of constants. Real constants are held as strings in program memory and can be read as numeric values or string values. String constants may contain spaces but if they need to contain commas then they must be enclosed in quotes.

DEC <var>[,var]...

Decrement variables. The variables listed will have their values decremented by one. Trying to decrement a string variable will give a type mismatch error. DEC A is much faster than doing A=A-1 and DEC A,A is slightly faster than doing A=A-2.

DEF FN <name>(<var>) = <statement>

Defines <statement> as function <name>. <name> can be any valid numeric variable name of one or more characters. <var> must be a simple variable and is used to pass a numeric argument into the function.

Note that the value of <var> will be unchanged if it is used in the function so <var> should be considered to be a local variable name.

DIM <var[$](i1[,i2[,in]...])>[,var[$](i1[,i2[,in]...])]...

Dimension arrays. Creates arrays of either string or numeric variables. The arrays can have one or more dimensions. The lower limit of any dimension is always zero and the upper limit is i. If you do not explicitly dimension an array then it's number of dimensions will be set when you first access it and the upper bound will be set to 10 for each dimension.

DIRECTORY <IEC DEVICE b>

Prints the disk directory from device <b>.

DISKCMD <command$>,<IEC DEVICE b>

Sends the disk command to device b. See the disk device documentation for a list of commands and syntax.

Example: DISKCMD “S0:FILENAME”,8

DO

Marks the beginning of a DO .. LOOP loop (See LOOP). No parameters. This command can be nested like FOR .. NEXT or GOSUB .. RETURN.

ELSE

See IF.

END

Terminates program execution and returns control to the command line (direct mode). END may be placed anywhere in a program, it does not have to be on the last line, and there may be any number, including none, of ENDs in total.

Note. CONT may be used after an END to resume execution from the next statement.

FN<name>(<expression>)

See DEF.

FOR <var> = <expression> TO <expression> [STEP expression]

Assigns a variable to a loop counter and optionally sets the start value, the end value and the step size. If STEP expression is omitted then a default step size of +1 will be assumed.

GET# <Logical File b>,<var[$]>

Gets a character, if there is one, from the input channel <b>. This command must be preceded by OPEN and IECINPUT commands. See Working with Files for more information.

GET <var[$]>

Gets a key, if there is one, from the input device. If there is no key waiting then var will be set to 0 and var$ will return a null string "". GET does not halt and execution will continue.

GOSUB <n>

Call a subroutine at line n. Program execution is diverted to line n but the calling point is remembered. Upon encountering a RETURN statement program execution will continue with the next statement (line) after the GOSUB.

GOTO <n>

Continue execution from line number n.

IECINPUT <Logical File b>

Designate IEC channel <b> as input. See Working with Files for more information.

IECOUTPUT <Logical File b>

Designate IEC channel <b> as output. See Working with Files for more information.

IF <expression> {GOTO<n>|THEN<{n|statement}>}[ELSE<{n|statement}>]

Evaluates expression. If the result of expression is non zero then the GOTO or the statement after the THEN is executed. If the result of expression is zero then execution continues with the next line.

If the result of expression is zero and the optional ELSE clause is included then the statement after the ELSE is executed.

IF .. THEN .. ELSE .. behaves as a single statement so in the line ..

IF <expression> THEN <statement one> ELSE <statement two> :

<statement three>

.. statement three will always be executed regardless of the outcome of the IF as long as the executed statement was not a GOTO.

INC <var>[,var]...

Increment variables. The variables listed will have their values incremented by one. Trying to increment a string variable will give a type mismatch error. INC A is much faster than doing A=A+1 and INC A,A is slightly faster than doing A=A+2.

INPUT ["$";] <var>[,var]...

Get a variable, or list of variables from the input stream. A question mark, "?", is always output, after the string if there is one, and if further input is required, i.e. there are more variables in the list than the user entered values, then a double question mark, "??", will be output until enough values have been entered.

There are two possible messages that may appear during the execution of an input statement:

Extra ignored

The user has attempted to enter more values than are required. Program execution will continue but the extraneous data entered has been discarded.

Redo from start

The user has attempted to enter a string where a number was expected. The reverse never causes an error as numbers are also valid strings.

LET <var> = <expression>

Assign the value of expression to var. Both var and expression bust be of the same type. The LET command word is optional and just <var> = <expression> will give exactly the same result. It is only maintained for historical reasons.

LIST [n1][-n2]

Lists the entire program held in memory. If n1 is specified then the listing will start from line n1 and run to the end of the program. If -n2 is specified then the listing will terminate after line n2 has been listed. If n1 and -n2 are specified then all the lines from n1 to n2 inclusive will be listed.

Note. If n1 does not exist then the list will start from the next line numbered after n1. If n2 does not exist then the listing will stop with the last line numbered before n2.

Also note. LIST can be executed from within a program, first a [CR][LF] is printed and then the specified lines, if any, each terminated with another [CR][LF]. Program execution then continues as normal.

LOAD var[$] ,<b>

Load a program named var[$] from IEC channel <b>.

LOOP [{UNTIL|WHILE} expression]

Marks the end of a DO .. LOOP loop. There are three possible variations on the LOOP command ..

LOOP

This loop repeats forever. With just this command control is passed back to the next command after the corresponding DO.

LOOP UNTIL expression

This loop will repeat until the value of expression is non zero. Once that occurs execution will continue with the next command after the LOOP UNTIL.

LOOP WHILE expression

This loop will repeat while the value of expression is non zero. When the value of expression is zero execution will continue with the next command after the LOOP WHILE.

MONITOR

Exit to the system monitor. See WE816 system documentation for more information on how to use the system monitor.

NEW

Deletes the current program and all variables from memory.

NEXT [var[,var]...]

Increments or decrements a loop variable and checks for the terminating condition. If the terminating condition has been reached then execution continues with the next command, else execution continues with the command after the FOR assignment. See FOR.

NOISE <channel b>,<noise period b>

Selects a given channel (0-2) to generate NOISE, rather than TONE, and configures the noise period.

NOT <expression>

Generates the bitwise NOT of then signed integer value of <expression>.

NULL <n>

Sets the number of null characters printed by BASIC after every carriage return. n may be specified in the range 0 to 255.

ON <expression> {GOTO|GOSUB} <n>[,n]...

The integer value of expression is calculated and then the nth number after the GOTO or GOSUB is taken (where n is the result of expression). Note that valid results for expression range only from zero to 255. Any result outside this range will cause a Function call error.

OPEN <Logical File b>,<IEC Device Number b>,<Secondary Address b>,<file name var[$]>

Open a file to an IEC Device. See Working with Files for more information.

PATTERN <character number b>, <b>,<b>,<b>,<b>, <b>,<b>,<b>,<b>

Redefine a character set pattern.

PLOT <b>,<b>,<b>

Plot a pixel to the screen X,Y,Color.

POKE <addr,b>

Writes the byte value b into the address addr.

PRINT [expression][{;|,}expression]...[{;|,}]

Outputs the value of each expressions. If the list of expressions to be output does not end with a comma or a semi-colon, then a carriage return and linefeed is output after the values. Expressions on the line can be separated with either a semi-colon, causing the next expression to follow immediately, or a comma which will advance the output to the next tab stop before continuing to print. If there are no expressions and no comma or semi-colon after the PRINT statement then a carriage return and linefeed is output.

When entering a program line, or immediate statement, PRINT can be abbreviated to ?

PUT# <Logical File b>,<var[$]>

Outputs the char value to IEC channel <b>. This must be preceded with Open and IECOUTPUT commands. See Working with Files for more information.

READ <var>[,var]...

Reads values from DATA statements and assigns them to variables. Trying to read a string literal into a numeric variable will cause a syntax error.

REM

Everything following this statement on this program line will be ignored, even colons.

RESTORE [n]

Reset the DATA pointer. If n is specified then the pointer will be reset to the beginning of line n else it will be reset to the start of the program. If n is specified but doesn't exist an error will be generated.

RETURN

Returns program execution to the next statement (line) after the last GOSUB encountered. See GOSUB. Also returns program execution to the next statement after an interrupt but does not restore the enabled flags.

RUN [n]

Begins execution of the program currently in memory at the lowest numbered line. RUN erases all variables and functions, resets FOR .. NEXT, GOSUB .. RETURN and DO ..LOOP states and sets the data pointer to the program start.

If n is specified then programme execution will start at the specified line number.

SAVE <var[$]>,<b>

Save the program in memory to filename <$> on IEC Device <b>.

SCNCLR

Clear the Text Screen.

SCREEN <b,b> [,b]

Set the graphics screen mode. See Working with Graphics for more information.

0,0 | Text Mode (40x24) 16 color
0,1 | Text Mode (80x24) 16 color
1,0,0 Single Lores (40,48) 16 color
1,0,1 Single Lores (40,40) 16 color, with 4 line text window 1,1,0 Double Lores (80,48) 16 color
1,1,1 Double Lores (80,40) 16 color, with 4 line text window 2,0,0 Hires (140x192) 16 color
2,0,1 Hires (140x160) 16 color, with 4 line text window
2,1,0 Double Hires (280x192) 16 color
2,1,1 Double Hires (280x160) 16 color, with 4 line text window 2,2,0 Quad Hires (560x192) 2 color
2,2,1 Quad Hires (560x160) 2 color, with 4 line text window 2,3,0 Mono Hires (280x192) 2 color
2,3,1 Mono Hires (280x160) 2 color, with 4 line text window

SOUND <channel b>, <frequency var>

Play a sound on channel (0-2), at the frequency var. See Appendix for musical note to frequency values. Note that “frequency” does not equate to actual frequency of the note provided.

SPC(<expression>)

Prints <expression> spaces. This command is only valid in a PRINT statement.

STEP

Sets the step size in a FOR .. NEXT loop. See FOR.

STOP

Halts program execution and generates a "Break in line n" message where n is the line in which the STOP was encountered.

SWAP <var[$]>,<var[$]>

Swap two variables. The variables listed will have their values exchanged. Both must be of the same type, numeric or string, and either, or both, may be array elements. Trying to swap a numeric and string variable will give a type mismatch error.

TAB(<expression>)

Sets the cursor position to <expression>. If the cursor is already beyond that point then the cursor will be left where it is. This command is only valid in a PRINT statement.

THEN

See IF.

TO

Sets the range in a FOR .. NEXT loop. See FOR.

TONE <channel b>

Sets the channel (0-2) to generate TONEs rather than NOISE.

UNTIL

See DO and LOOP.

VOICE <shape b>,<period var>

Set the envelope generator on the chip to a given shape, and period (duration of one cycle).

Shapes:

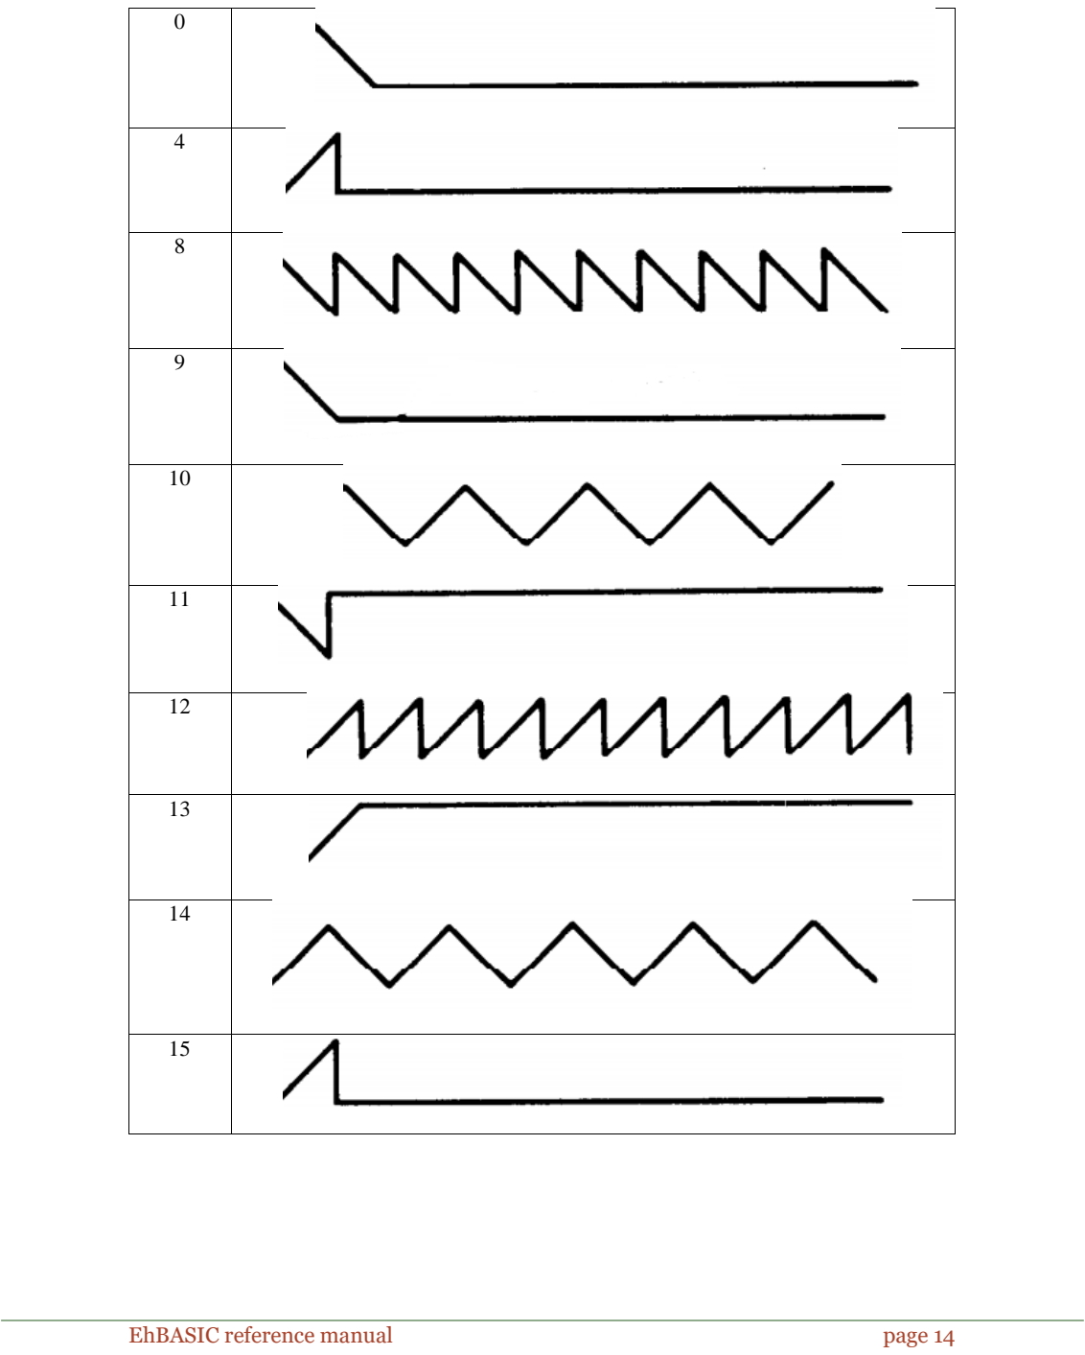
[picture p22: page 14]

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
VOLUME <channel b>,<volume b>

Set the volume of a given channel (0-2) to <B>.

For solid tones, use values 0-15. To use the envelope generator on the chip, use values 16-31.

WAIT <addr,b1>[,b2]

Program execution will wait at this point until the value of the location addr exclusive ORed with b2 then ANDed with b1 is non zero. If b2 is not defined then it is assumed to be zero. Note b1 and b2 must both be byte values.

WHILE

See DO and LOOP.

WIDTH {b1|,b2|b1,b2}

Sets the terminal width and TAB spacing. b1 is the terminal width and b2 is the tab spacing, default is 80 and 14. Width can be zero, for "infinite" terminal width, or from 16 to 255. The tab size is from 2 to width-1 or 127, whichever is smaller.

BASIC Operators

Operators perform mathematical or logical operations on values and return the result. The operation is usually preceded by a variable name and equality sign or is part of an IF .. THEN statement.

+ Add. c = a + b will assign the sum of a and b to c.
- Subtract. c = a - b will assign the result of a minus b to c.
* | Multiply. c = a * b will assign the product of a and b to c.
/ | Divide. c = a / b will assign the result of a divided by b to c.
^ | Raise to the power of. c = a ^ b will assign the result of a raised to the power of b to c.
AND Logical AND. c = a AND b will assign the logical AND of a and b to c
EOR Logical Exclusive OR. c = a EOR b will assign the logical exclusive OR of a and b to c.
OR | Logical OR. c = a OR b will assign the logical inclusive OR of a and b to c.
<< | Shift left. c = a << b will assign the result of a shifted left by b bits to c.
>> | Shift right. c = a >> b will assign the result of a shifted right by b bits to c.
= | Equals. c = a = b will assign the result of the comparison a = b to c.
> | Greater than. c = a < b will assign the result of the comparison a > b to c.
< | Less than. c = a < b will assign the result of the comparison of a < b to c.

The three comparison operators can be mixed to provide further operators ..

>= or => Greater than or equal to.

<= or =< | Less than or equal to.
<> or >< | Not equal to (greater than or less than).
<=> any order Always true (greater than or equal to or less than).

BASIC Functions

Functions always return a value, be it numeric or string, so are used on the right hand side of the = sign in assignments, on either side of operators and in commands requiring an expression e.g. after PRINT, within expressions, or in other functions.

ABS(<expression>)

Returns the absolute value of <expression>.

ASC(<expression$>)

Returns the ASCII value of the first character of <expression$>.

ATN(<expression>)

Returns, in radians, the arctangent of <expression>.

BIN$(<expression>[,b])

Returns <expression> as a binary string. If b is omitted, or if b = 0, then the string is returned with all leading zeroes removed and is of variable length. If b is set, permissible values range from 1 to 24, then a string of length b will be returned. The result is always unsigned and calling this function with expression > 2^24-1 or b > 24 will cause a function call error.

BITTST(<addr>,<b>)

Tests bit b of address addr. Valid bit numbers are 0, the least significant bit, to 7, the most significant bit. Values outside this range will cause a function call error. Returns zero if the bit was zero, returns -1 if the bit was 1.

CON(<b>)

Takes game controller number as one parameter (0,1) and returns the state of that game controller. The status of the controller is encoded like this:

BIT 7 | BIT 6 | BIT 5 | BIT 4 | BIT 3 | BIT 2 | BIT 1 | BIT 0
| | BUTTON B | BUTTON A | RIGHT | LEFT | DOWN | UP

COS(<expression>)

Returns the cosine of the angle <expression> radians.

DAY

Returns the day of the month from the real time clock.

DISKSTATUS(<b>)

Returns the string value of the disk status of device <b>

EXP(<expression>)

Returns e^<expression>. Natural antilog.

FRE(<expression>)

Returns the amount of free program memory. The value of expression is ignored and can be numeric or string.

HEX$(<expression>[,b])

Returns <expression> as a hex string. If b is omitted, or if b = 0, then the string is returned with all leading zeroes removed and is of variable length. If b is set, permissible values range from 1 to 6, then a string of length b will be returned. The result is always unsigned and calling this function with expression > 2^24-1 or b > 6 will cause a function call error.

HOUR

Returns the hour of the day month from the real time clock.

IECST(<b>)

Returns the IEC status of channel <b>.

INT(<expression>)

Returns the integer of <expression>.

LCASE$(<expression$>)

Returns <expression$> with all the alpha characters in lower case.

LEFT$(<expression$,b>)

Returns the leftmost b characters of <expression$>. LEN(<expression$>)

Returns the length of <expression$>.

LOG(<expression>)

Returns the natural logarithm (base e) of <expression>.

MAX(<expression>[,<expression>]...)

Returns the maximum value from a list of numeric expressions. There must be at least one expression but the upper limit is dictated by the line length. Each expression is evaluated in turn and the largest of them returned.

MID$(<expression$,b1>[,b2])

Returns the substring string from character b1 of expression$ of length b2. The characters of expression$ are numbered from 1 starting with the leftmost. If b2 is omitted then all the characters from b1 to the end of the string are returned.

MIN(<expression>[,<expression>]...)

Returns the minimum value from a list of numeric expressions. There must be at least one expression but the upper limit is dictated by the line length. Each expression is evaluated in turn and the smallest of them returned.

MINUTE

Returns the minute of the hour from the real time clock.

MONTH

Returns the month of the year from the real time clock.

PEEK(<addr>)

Returns the byte value of <addr>.

PI

Returns the value of pi as 3.14159274 (closest floating value).

POS(<expression>)

Returns the POSition of the cursor on the terminal line. The value of expression is ignored.

RIGHT$(<expression$,b>)

Returns the rightmost b characters of <expression$>.

RND(<expression>)

Returns a random number in the range 0 to 1. If the value of <expression> is non zero then it will be used as the seed for the returned pseudo random number otherwise the next number in the sequence will be returned.

SADD(<{var$|var$()}>)

Returns the address of var$ or var$(). This returns a pointer to the actual string in memory not the descriptor. If you want the pointer to the descriptor use VARPTR instead.

SECOND

Returns the second of the minute from the real time clock.

SGN(<expression>)

Returns the sign of <expression>. If the value is positive SGN returns +1, if the value is negative then SGN returns -1. If expression=0 then SGN returns 0.

SIN(<expression>)

Returns the sine of the angle <expression> radians.

SQR(<expression>)

Returns the square root of <expression>.

STR$(<expression>)

Returns the result of <expression> as a string.

TAN(<expression>)

Returns the tangent of the angle <expression> radians.

UCASE$(<expression$>)

Returns <expression$> with all the alpha characters in upper case.

CHR$(b)

Returns single character string of character <b>.

USR(<expression>)

Takes the value of <expression> and places it in FAC1 and then calls the USeR routine pointed to by the vector at $0B,$0C. What the routine does with this value is entirely up to the user, it can even be safely ignored if it isn't needed. The routine, after the user code has done an RTS, takes whatever is in FAC1 and returns that. Note it can be either a numeric or string value. See using USR() for details.

If no value needs to be passed or returned then CALL is a better option.

VAL(<expression$>)

Returns the value of <expression$>.

VARPTR(<var[$]>)

Returns a pointer to the variable memory space. If the variable is numeric, or a numeric array element, then VARPTR returns the pointer to the packed value of that variable in memory. If the variable is a string, or a string array element, then VARPTR returns a pointer to the descriptor for that string. If you want the pointer to the string itself use SADD instead.

WEEKD

Returns the day of the month from the real time clock.

YEAR

Returns the year from the real time clock.

BASIC Error Messages

These all occur from time to time and, if the error occurred while executing a program, will be followed by "in line " where is the number of the line in which the error occurred.

Array bounds Error

An attempt was made to access an element of an array that was outside it's bounding dimensions.

Can't continue Error

Execution can't be continued because either the program execution ended because an error occurred, NEW or CLEAR have been executed since the program was interrupted or the program has been edited.

Divide by zero Error

The right hand side of an A/B expression was zero.

Double dimension Error

An attempt has been made to dimension an already dimensioned array. This could be because the array was accessed previously causing it to be dimensioned by default.

Function call Error

Some parameter of a function was outside it's limits. E.g. Trying to POKE a value of less than 0 or greater than 255.

Illegal direct Error

An attempt was made to execute a command or function in direct mode which is disallowed in that mode e.g. INPUT or DEF.

LOOP without DO Error

LOOP has been encountered and no matching DO could be found.

NEXT without FOR Error

NEXT has been encountered and no matching FOR could be found.
Out of DATA Error

A READ has tried to read data beyond the last item. Usually because you either mistyped the DATA lines, miscounted the DATA, RESTOREd to the wrong place or just plain forgot to restore.

Overflow Error

The result of a calculation has exceeded the numerical range of BASIC. This is plus or minus 1.7014117+E38

Out of memory Error

Anything that uses memory can cause this but mostly it's writing and running programmes that does it.

RETURN without GOSUB Error

RETURN has been encountered and no matching GOSUB could be found.

String too complex Error

A string expression caused an overflow on the descriptor stack. Try splitting the expression into smaller pieces.

String too long Error

String lengths can be from zero to 255 characters, more than that and you will see this.

Syntax Error

Just generally wrong. 8^)=

Type mismatch Error

An attempt was made to assign a numeric value to a string variable, a string value to a numeric variable or a value of one type was returned when a value of the other type was expected or an attempt at a relational operation between a string and a number was made.

Undefined function Error

FN <var> was called but not found.

Undefined statement Error

Either a GOTO, GOSUB, RUN or RESTORE was attempted to a line that doesn't exist or the line referred to in an ON <expression> {GOTO|GOSUB} or ON {IRQ|NMI} doesn't exist.

Enhanced BASIC, advanced examples

Working with Files.
The following is an example BASIC program that writes and reads back a sequential file to the Commodore 1541 Disk Drive. For more advanced drive functions, please see the reference guide for the IEC device you are communicating with.

### 10 OPEN 3,8,4,"TFI2,SEQ,W" 20 IECOUTPUT 3 30 PUT#3,"OUT"+CHR$(13) 31 PUT#3,"OUT1"+CHR$(13)+CHR$(5) 32 PUT#3,"OUT2"+CHR$(13)+CHR$(10)+CHR$(5) 40 CLOSE 3 70 OPEN 4,8,8,"TFI2,SEQ,R" 80 IECINPUT 4 90 GET#4,A 100 PRINT A, IECST 101 IF IECST=0 THEN GOTO 90 110 CLOSE 4

Working with Sound.

The AY-3-8910 sound chip is a simple (by today’s standards) sound generation chip. It contains 3 voices that can be configured as either tone or noise, and has a simple envelope generator. More specific information on the AY-3-8910 can be found online or in the AY-3-8910 datasheet.
Here are a few sample BASIC programs to generate a series of tones from the WE816.

Program 1:

### 5 REM SIMPLE SERIES OF TONES ON VOICE 0 10 VOLUME 0,15 20 TONE 0

30 I=100

### 30 FOR I = 100 TO 4000 STEP 100 40 SOUND 0,I

### 50 FOR X = 0 TO 500: NEXT X 60 NEXT I 70 SOUND 0,0

Program 2:

### 4 REM MORE COMPLEX SOUNDS USING THE ENVELOPE 6 REM GENERATOR AND A SAWTOOTH WAVEFORM 10 VOLUME 0,31 20 TONE 0 25 VOICE 8,2000 30 FOR I = 100 TO 4000 STEP 100 40 SOUND 0,I 50 FOR X = 0 TO 500: NEXT X 60 NEXT I 70 SOUND 0,0

Creating buffer space.

Sometimes there is a need for a byte oriented buffer space. This can be achieved by lowering the top of BASIC memory and using the "protected" space created thus. The main problem with this is that there may not be the same RAM configuration in all the systems this code is to run on.

One way round this is to allocate the space from BASIC's array memory by dimensioning an array big enough to hold your data. As arrays always start from zero then to work out the array size needed you do ..

Array dimension = (bytes needed/4)-1. E.g.

10 DIM b1(19) : REM need 80 bytes for input buffer
20 DIM b2($100) : REM need $0400 bytes for screen buffer

So you've allocated the buffer but where is it? This is one use of the VARPTR function, it is used in this case to return the start of the array's data space.

E.g.

100 a1 = VARPTR(b1(0)) : REM get the address of the buffer space

But wait, there is another problem here. Because variables are created when they are first assigned a value any new variable created after the array is dimensioned will move the array in memory. So the following will not work..

10 DIM b1(19) : REM 80 bytes for buffer
20 a1 = VARPTR(b1(0)) : REM get the address of the buffer space 40 FOR x = 0 to 79
50 POKE a1+x,ASC(" ")
60 NEXT

When we get to line 40, a1, the pointer to the array data space, is wrong because the variable x has been created and moved all the arrays up by six bytes. The way round this is to ensure that all variables that you will use have been created prior to getting the pointer. This also means you start with known values in all your variables.

10 DIM b1(19) : REM 80 bytes for buffer
20 x = 0 : REM loop counter
30 a1 = VARPTR(b1(0)) : REM get the address of the buffer space 40 FOR x = 0 to 79
50 POKE a1+x,ASC(" ")
60 NEXT

Another way is to get the pointer every time you use it. This has the advantage of always being correct but is somewhat slower.

10 DIM b1(19) : REM 80 bytes for buffer 40 FOR x = 0 to 79
50 POKE VARPTR(b1(0))+x,ASC(" ") 60 NEXT

One thing to remember, never try to use a string array as a buffer. Everything will seem to work until you run out of string space and the garbage collection routine is called. Once this happens it's likely that your buffer will get trashed and you may even find that the program freezes because the garbage collection routine now thinks that there are more string bytes than there are memory.

Creating short code space.

While the techniques explained above can also be used to create space for machine code routines there is a simpler way for position independent routines up to 255 bytes long to be held in memory.

Assemble the code and use the hex output from your assembler to create a set of BASIC data statements.

E.g.

1000 DATA $A5,$11,$C9,$3A,$B0,$08,$38,$E9 1010 DATA $30,$38,$E9,$D0,$90,$0D,$09,$20 1020 DATA $38,$E9,$61,$90,$0B,$C9,$06,$B0 1030 DATA $07,$69,$3A,$E9,$2F,$85,$11,$60 1040 DATA $18,$60 1050 DATA -1

Now we just use a loop like this to load this hex code into a string.

10 RESTORE 1000
20 READ by : REM assume at least one byte 30 DO
40 co$ = co$+CHR$(by)
50 READ by
60 LOOP UNTIL by=-1

The code can now be called by doing ..

140 CALL(SADD(co$))

Note that you must always use the SADD() function to get the address for the CALL as the garbage collection routine may move the string in memory and this is the best way to ensure that the address is always correct.
Coding for speed

Spaces

Remove spaces from your code. Spaces, while they don't affect the program flow, do take a finite time to skip over. The only space you don't need to worry about is the one between the line number and the code as this is stripped during input parsing and the apparent space is generated by the LIST command output.

E.g. the following ..

10 REM line 10
20 | REM line 20
30 | REM line 30

.. reads as follows when LISTed

10 REM line 10
20 REM line 20
30 REM line 30

Removing REM.

Remove remarks from your code. Remarks like spaces don't do anything, program wise, but take time to skip. Removing remarks, especially from time critical code, can make a big difference.

Variables.

Use variables. One place where time is wasted, especially in loops, is repeatedly interpreting numeric values or unchanging functions.

E.g.

140 FOR x = 0 to 79
150 POKE $F400+x,ASC(" ") 160 NEXT .

This loop can be improved in a number of ways. First assign a variable the value $F400 and use that. Doing this is faster after only three uses.

E.g.

10 a1 = $F400
140 FOR x = 0 to 79
150 POKE a1+x,ASC(" ")
160 NEXT

The other way to make this loop faster is to assign the value of the (unchanging) function to a variable, then move the function outside the loop.

E.g.

10 a1 = $F400
130 sp = ASC(" ")
140 FOR x = 0 to 79
150 POKE a1+x,sp
160 NEXT

Now the ASC(" ") is only evaluated once and the loop is executed faster.

GOTO and GOSUB

When EhBASIC encounters a GOTO or GOSUB it has to search through memory for the target line. If the target line follows the command then it searches from the next line, if the target line precedes the command then the search starts from the beginning of program memory. So keeping this distance, in lines, as short as possible will make the program run faster.

One place that this is difficult is in a conditional loop. In calculating points in the Mandelbrot set, for example, code like this is used ..

230 INC it
235 tp = mx*mx-my*my+x
240 my = 2*mx*my+y
245 mx = tp
250 co = (mx*mx + my*my)
255 IF (it<128) AND (co<4.0) THEN 230 .

Each time the condition in line 255 is met the interpreter has to search from the start of memory for line 230. While this may not take long if the program is short it can slow longer programs considerably.

This can easily be resolved though by using a DO .. LOOP instead. So our example code becomes..

220 DO
230 INC it
235 tp = mx*mx-my*my+x
240 my = 2*mx*my+y
245 mx = tp
250 co = (mx*mx + my*my)
255 LOOP WHILE (it<128) AND (co<4.0) .

This is quicker because the location of the start of the loop, the DO, is placed on the stack and the interpreter doesn't have to search for it.
Packing them in.

Another way to speed up time critical code is to place as many commands as possible on each line, this can make a noticeable speed gain.

E.g.

10 a1 = $F400
130 sp = ASC(" ")
140 FOR x = 0 to 79 : POKE a1+x,sp : NEXT .
INC and DEC.

INCrement and DECrement are quick and clear ways of altering a numeric value by plus or minus one and are faster than using add or subtract.

E.g.

100 INC a

.. is quicker than ..

100 a = a+1

.. and ..

100 INC a,a

.. is still quicker than ..

100 a = a+2

Also combine increments or decrements if you can.

E.g.

100 INC so,d

.. is quicker than ..

100 INC so : INC de

>> and <<

Using >> and << can be quicker than using / or * where integer math and a power of two is involved.

E.g. you want to find the byte that holds the pixel at x,y in a 256 x 32 display

100 ad = y*32 + INT(x/8) : REM pixel address

.. is done quicker with.

100 ad = y<<5 + x>>3 : REM pixel address

Coding for space

Most of the techniques used to improve the speed of a program can also reduce the number of bytes used by that program.

Spaces.

Remove spaces from your code. The only space you don't need to worry about is the one between the line number and the code as this is stripped during input parsing and the apparent space is generated by the LIST command output.

Removing REM.

Remove remarks from your code. Remarks like spaces don't do anything, removing remarks, can save a lot of space.

Variables.

Use variables. Often you will find yourself using the same numeric value again and again. If this value has many digits, such as the value for e (2.718282), then assigning that value at the beginning of the program can start to save space with the third use.

Re-use variables. Every time you assign a new variable a value it takes up six more bytes of the available memory. If you have a variable that is only used as a loop counter then try to use it for temporary values or GET values elsewhere in the program.

Constants.

There are two constants defined in EhBASIC, PI and TWOPI. They are the closest floating values to pi and 2*pi and will save you seven bytes each time you can use them.

Packing them in.

Another way to save space is to place as many commands as possible on each line, this will save you five bytes every time you put another command on an existing line compared to using a new line.

INC and DEC.

INCrement and DECrement also save space. Either will save you three bytes for each variable INCremented or DECremented.

Derived functions

The following functions, while not part of BASIC, can be calculated using the existing BASIC functions.

Secant | SEC(X)=1/COS(X)
Cosecant | CSC(X)=1/SIN(X)
Cotangent | COT(X)=1/TAN(X)
Inverse sine | ARCSIN(X)=ATN(X/SQR(X*X+1))

Inverse cosine | ARCCOS(X)=-ATN(X/SQR(X*X+1))+PI/2
Inverse secant | ARCSEC(X)=ATN(SQR(X*X-1))+(SGN(X)-1)*PI/2

Inverse cosecant

ARCCSC(X)=ATN(1/SQR(X*X-1))+(SGN(X)-1)*PI/2

Inverse cotangent | ARCCOT(X)=-ATN(X)+PI/2
Hyperbolic sine | SINH(X)=(EXP(X)-EXP(-X))/2
Hyperbolic cosine | COSH(X)=(EXP(X)+EXP(-X))/2
Hyperbolic tangent | TANH(X)=-EXP(-X)/(EXP(X)+EXP(-X))*2+1
Hyperbolic secant | SECH(X)=2/(EXP(X)+EXP(-X))
Hyperbolic cosecant | CSCH(X)=2/(EXP(X)-EXP(-X))
Hyperbolic cotangent | COTH(X)=EXP(-X)/(EXP(X)-EXP(-X))*2+1
Inverse hyperbolic sine | ARCSINH(X)=LOG(X+SQR(X*X+1))

Inverse hyperbolic
cosine | ARCCOSH(X)=LOG(X+SQR(X*X-1))

Inverse hyperbolic
tangent | ARCTANH(X)=LOG((1+X)/(X))/2

Inverse hyperbolic
secant | ARCSECH(X)=LOG((SQR(X*X+1)+1)/X)

Inverse hyperbolic
cosecant | ARCCSCH(X)=LOG((SGN(X)*SQR(X*X+1)+1)/X)

Inverse hyperbolic
cotangent | ARCCOTH(X)=LOG((X+1)/(X-1))/2

Enhanced BASIC, extending CALL

Introduction.

CALL <address> calls a machine code routine at location address. While this in itself is useful it can be extended by adding parameters to the CALL and parsing them from within the routine.
This technique can also be used to pass extra parameters to the USR() function.
How to.

First you need to define the parameters for your CALL. This example is for an imaginary bitmapped graphic device.

CALL PLOT,x,y | Set the pixel at x,y
PLOT | routine address
x | x axis value, range 0 to 255
y | y axis value, range 0 to 64

This will then be the form that the call will always take.

Now you need to write the code.

.include BASIC.DIS | ; include the BASIC labels file. this allows you
| ; easy access to the internal routines you need
| ; to parse the command stream and access some of
| ; the internals of BASIC. It is usually output
| ; by the assembler as part of the listing or as a
| ; separate, optional, file.

; for now we'll put this in the spare RAM @ $F400

*= | $F400

PLOT
JSR | LAB_SCGB | ; scan for "," and get byte
STX | PLOT_XBYT | ; save plot x
JSR | LAB_SCGB | ; scan for "," and get byte
CPX | #$40 | ; compare with max+1
BCS | PLOT_FCER | ; if 64d or greater do function call error
STX | PLOT_YBYT | ; save plot y

; now would be your code to perform the plot command ;.
;.
;.
;.
;.
RTS | | ; return to BASIC

; does BASIC function call error PLOT_FCER
JMP | LAB_FCER | ; do function call error, then warm start

; now we just need the variable storage

PLOT_XBYT
.byte $00 | ; set default

PLOT_YBYT
.byte $00 | ; set default

END

Finally you need to set the value of PLOT in your BASIC program and use that to call it.

E.g.

10 PLOT = $F400
145 CALL PLOT,25,14 : REM set pixel .

Enhanced BASIC, using USR()

Introduction.

USR(<expression[$]>) calls the machine code function pointed to by the user jump vector after evaluating <expression[$]> and placing the result in the first floating accumulator. Once the user function exits, via an RTS, the value in the floating accumulator is passed back to EhBASIC.

Either a numeric value or a string can be passed, and either type can be returned depending on the setting of the data type flag at the end of the user code and the return point (see code examples for details).

It can also be extended by adding parameters to USR() and parsing them from within the routine in the same way that CALL can be extended, just remember to get the value from FAC1 first.

How to - numeric source, numeric result.

First you need to write the code.

; this code demonstrates the use of USR() to quickly calculate the square of a ; byte value. Compare this with doing SQ=A*A or even SQ=A^2.

.include BASIC.DIS | ; include the BASIC labels file. this allows
| ; you easy access to the internal routines you
| ; need to parse the command stream and access
; some of the internals of BASIC. It is usually ; output by the assembler as part of the listing
; or as a separate, optional, file.

; for now we'll put this in the spare RAM @ $F400

*= | $F400

Square
JSR | LAB_EVBY | ; evaluate byte expression, result in X and FAC1_3
LDA | #$00 | ; clear A
STA | FAC1_2 | ; clear square low byte (use FAC1 as the workspace)
| | ; (no need to clear the high byte, it gets shifted out)
TXA | | ; copy byte to A
LDX | #$08 | ; set bit count
Nextr2bit
ASL | FAC1_2 | ; low byte *2
ROL | FAC1_1 | ; high byte *2+carry from low
ASL | A | ; shift byte
BCC | NoSqadd | ; don't do add if C = 0
TAY | | ; save A
CLC | | ; clear carry for add
LDA | FAC1_3 | ; get number
ADC | FAC1_2 | ; add number^2 low byte
STA | FAC1_2 | ; save number^2 low byte
LDA | #$00 | ; clear A
ADC | FAC1_1 | ; add number^2 high byte
STA | FAC1_1 | ; save number^2 high byte
TYA | | ; get A back

NoSqadd
DEX | | ; decrement bit count
BNE | Nextr2bit | ; go do next bit
LDX | #$90 | ; set exponent=2^16 (integer)
SEC | | ; set carry for positive result
JMP | LAB_STFA | ; set exp=X, clearFAC1 mantissa3, normalise & return
Now you need to set up the address for your function. This is done by DOKEing an address into the USR() vector e.g.
DOKE $0B,$F400 | ; set the user function address to addr ; $0B - user function vector address ; $F400 - routine address

Finally you need to set the vector in your BASIC program and use that to call the function

10 DOKE $0B,$F400
145 SQ=USR(A) .

How to - numeric source, string result.

AS before, first you need to write the code.

; this code demonstrates the use of USR() to generate a string of # characters. ; the length of the required string is the parameter passed.

.include BASIC.DIS | ; include the BASIC labels file. this allows
| ; you easy access to the internal routines you
| ; need to parse the command stream and access
| ; some of the internals of BASIC. It is usually
; output by the assembler as part of the listing ; or as a separate, optional, file.

; for now we'll put this in the spare RAM @ $F400

*= | $F400

STRING
JSR | LAB_EVBY | ; evaluate byte expression, result in X and FAC1_3
TXA | | ; string is byte length
BEQ | NUL_STRN | ; branch if null string
JSR | LAB_MSSP
; make string space A bytes long A=$AC=length, ; X=$AD=Sutill=ptr low byte,
; Y=$AE=Sutilh=ptr high byte

LDA | #"#" | ; set character
LDY | FAC1_3 | ; get length
SAV_HASH
DEY | | ; decrement bytes to do
STA | (str_pl),Y | ; save byte in string
BNE | SAV_HASH | ; loop if not all done

NUL_STRN
PLA | | ; dump return address (return via get value
PLA | | ; from line, this skips the type checking and ; so allows a string result to be returned)
JMP | LAB_RTST | ; check for space on descriptor stack then put ; string address and length on descriptor stack ; & update stack pointers

Now you need to set up the address for your function. This is done by DOKEing an address into the USR() vector e.g.

DOKE $0B,$F400 | ; set the user function address to addr ; $0B - user function vector address ; $F400 - routine address

Finally you need to set the vector in your BASIC program and use that to call the function

10 DOKE $0B,$F400
145 HA$=USR(A) .

How to - string source, numeric result.

AS before, first you need to write the code.

; this code demonstrates the use of USR() to test a string of characters. ; if all the string is alpha -1 is returned, else 0 is returned.

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

; for now we'll put this in the spare RAM @ $F400

*= | $F400

ALPHA
JSR | LAB_EVST | ; evaluate string

TAX | | ; copy length to X
BEQ | NOT_ALPH | ; branch if null string
LDY | #$00 | ; clear index
ALP_LOOP
LDA | (ut1_pl),Y | ; get byte from string
JSR | LAB_CASC | ; is character "a" to "z" (or "A" to "Z")
BCC | NOT_ALPH | ; branch if not alpha
INY | | ; increment index
DEX | | ; decrement count
BNE | ALP_LOOP | ; loop if not all done
LDA | #$FF | ; set for -1
BNE | IS_ALPHA | ; branch always

NOT_ALPH
LDA | #$00 | ; set for 0
IS_ALPHA
TAY | | ; copy byte
LDX | #$00 | ; clear byte
STX | Dtypef | ; clear data type flag, $00=numeric
JMP | LAB_AYFC | ; save & convert integer AY to FAC1 & return
Now you need to set up the address for your function. This is done by DOKEing an address into the USR() vector e.g.
DOKE $0B,$F400 | ; set the user function address to addr ; $0B - user function vector address ; $F400 - routine address

Finally you need to set the vector in your BASIC program and use that to call the function

10 DOKE $0B,$F400
145 AL=USR(A$) .

How to - string source, string result.

AS before, first you need to write the code.

; this code demonstrates the use of USR() invert the case of a string of ; characters. only alpha characters will be affected.

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

; for now we'll put this in the spare RAM @ $F400

*= | $F400

ALPHA
JSR | LAB_EVST | ; evaluate string
STA | str_ln | ; set string length
STX | str_pl | ; set string pointer low byte
STY | str_ph | ; set string pointer high byte
TAX | | ; copy length to X
BEQ | NO_STRNG | ; branch if null string
LDY | #$00 | ; clear index

ALP_LOOP
LDA | (ut1_pl),Y | ; get byte from string
JSR | LAB_CASC | ; is character "a" to "z" (or "A" to "Z")
BCC | NOT_ALPH | ; branch if not alpha
EOR | #$20 | ; toggle case
STA | (ut1_pl),Y | ; save byte back to string
NOT_ALPH
INY | | ; increment index
DEX | | ; decrement count
BNE | ALP_LOOP | ; loop if not all done

NO_STRNG
PLA | | ; dump return address (return via get value
PLA | | ; from line, this skips the type checking and ; so allows a string result to be returned)
JMP | LAB_RTST | ; check for space on descriptor stack then put ; string address and length on descriptor stack ; & update stack pointers

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

10 DOKE $0B,$F400
145 A$=USR(A$) .

Enhanced BASIC internals

Floating point numbers.

Floating point numbers are stored in memory in four bytes. The format of the numbers is as follows.

Exponent | S | Mantissa 1 | Mantissa 2 | Mantissa 3

Exponent

This is the power of two to which the mantissa is to be raised. This number is biased to +$80 i.e. 2^0 is represented by $80, 2^1 by $81 etc. Zero is a special case and is used to represent the value zero for the whole of the number.

S

Sign bit. This bit (b7 of mantissa 1) is one if the number is negative.

Mantissa 1/2/3

This is the 24 bit mantissa of the number and is normalised to make the highest bit (b7 of mantissa 1) always one. So the absolute value of the mantissa varies between 0.5 and 0.9999999403954 . As we know that the highest bit is always one it is replaced by the sign bit in memory.

Example.

$82,$49,$0F,$DB = +3.14159274 nearest floating equivalent to pi
| | |\--+---+- = 0.785398185 absolute value of mantissa | | | |
| | \--------- = + | b7 of mantissa 1 is zero
\------------- = x 2^2 = 4 mantissa to be multiplied by 4

Values represented in this way range between + and - 1.70141173x10^38

BASIC program memory use.

A BASIC program is stored in memory from Ram_base upwards. It's format is ..

$00 Start of program marker byte

.. then each BASIC program line which is stored as ..

start of next line pointer low byte
start of next line pointer high byte

line number low byte line
number high byte code
byte(s)
$00 End of line marker byte

.. and finally ..

$00 End of program marker byte 1 $00
End of program marker byte 2

If there is no program in memory only the start and end marker bytes are present.
BASIC variables memory use.

After the program come the variables and function references, all six bytes long, which are stored as ..

1st character of variable or function name (+$80 if FN name)
2nd character of variable or function name (+$80 if string)

.. then for each type ..

Numeric | String | Function
Exponent | String length | BASIC execute pointer low byte
Sign (bit 7) + mantissa 1 String pointer low byte | BASIC execute pointer high byte
Mantissa 2 | String pointer high byte | Function variable name 1st character
Mantissa 3 | $00 | Function variable name 2nd character

After the variables come the arrays, which are stored as ..

1st character of variable name
2nd character of variable name (+$80 if string) array size in bytes low byte (size includes this header) array size in bytes high byte number of dimensions [dimension 3 size high byte] (lowest element is zero) [dimension 3 size low byte]
[dimension 2 size high byte] (lowest element is zero) [dimension 2 size low byte]
dimension 1 size high byte (lowest element is zero) dimension 1 size low byte

.. and then each element ..

Numeric | String
Exponent | String length
Sign (bit 7) + mantissa 1 | String pointer low byte
Mantissa 2 | String pointer high byte
Mantissa 3 | $00

The elements of every array are stored in the order ..

index1 [0-n], index2 [0-n], index3 [0-n]

i.e. element (1,2,3) in an array of (3,4,5) would be the ..

1 + 1 + 2*(3+1) + 3*(3+1)*(4+1) = 70th element

(As array dimensions range from 0 to n element n will always be the (n+1)th element in memory.)
String placement in memory.

Strings are generally stored from the top of available RAM, Ram_top, working down, however if the interpreter encounters a line such as ..

100 A$ = "This is a string"

.. then the high/low pointer in the A$ descriptor will point to the string in program memory and will not make a copy of the string in the string memory.

String descriptors in BASIC.

A string descriptor is a three byte table that describes a string, it is of the format ..

base = string length base+1 =
string pointer low byte base+2
= string pointer high byte

Stack use in BASIC.

GOSUB and DO both push on the stack ..

BASIC execute pointer high byte BASIC execute pointer low byte
current line high byte
current line low byte
command token (TK_GOSUB or TK_DO)

FOR pushes on the stack ..

BASIC execute pointer low byte BASIC execute pointer high byte FOR line high byte
FOR line low byte
TO value mantissa3
TO value mantissa2
TO value mantissa1
TO value exponent
STEP sign

STEP value mantissa3
STEP value mantissa2
STEP value mantissa1 STEP value exponent var pointer for
FOR/NEXT high byte var pointer for FOR/NEXT low byte token for FOR (TK_FOR)

Enhanced BASIC, useful routines

Introduction.

There are many subroutines within BASIC that can be useful if you wish to use your own assembly routines with it. Here are some of them with a brief description of their function. For full details see the source code.

Note that most, if not all, of these routines need EhBASIC to be initialised before they will work properly and can not be used in isolation from EhBASIC.

The routines.

LAB_IGBY
BASIC increment and get byte routine. gets the next byte from the BASIC command stream. If the byte is a numeric character then the carry flag will be set, if the byte is a termination byte, either null or a statement separator, then the zero flag will be set. Spaces in the
command stream will automatically be ignored.

LAB_GBYT
BASIC get byte routine. Gets the current byte from the BASIC command stream but does not change the pointer. Otherwise the same as above.

LAB_COLD
Performs a cold start. BASIC is reset and all BASIC memory is cleared.

LAB_WARM
Performs a warm start. Execution is stopped and BASIC returns to immediate mode.

LAB_OMER
Do "Out of memory" error, then warm start. The same as error $0C below.

LAB_XERR
With X set, do error #X, then warm start.
X | Error | X | Error
$00 | NEXT without FOR | $02 | syntax
$04 | RETURN without GOSUB | $06 | out of data

$08 | function call | $0A | overflow

$0C

out of memory | $0E | undefined statement
$10 | array bounds | $12 | double dimension array
$14 | divide by 0 | $16 | illegal direct
$18 | type mismatch | $1A | long string
$1C | string too complex | $1E | continue error

$20

undefined function | $22 | LOOP without DO

LAB_INLN
Print "? " and get BASIC input. Returns XY (low/high) as a pointer to the start of the input line. The input is null terminated.

LAB_SSLN
Search Basic for a line, the line number required is held in the temporary integer, from start of program memory. Returns carry set and a pointer to the line in Baslnl/Baslnh if found, if not it returns carry and a pointer to the next numbered line in Baslnl/Baslnh.

LAB_SHLN
Search Basic for temporary integer line number from AX. Same as above but starts the search from AX (low/high).

LAB_SNBS
Scan for next BASIC statement (: or [EOL]). Returns Y as index to : or [EOL] from (Bpntrl).

LAB_SNBL
Scan for next BASIC line. Same as above but only returns on [EOL].

LAB_REM
Perform REM, skip (rest of) line.

LAB_GFPN
Get fixed-point number into temporary integer.

LAB_CRLF
Print [CR]/[LF] to output device.

LAB_PRNA
Print character in A to output device.

LAB_GVAR
Get variable address. Returns a pointer to the variable in Lvarpl/h and sets the data type flag, $FF=string, $00=numeric.

LAB_EVNM
Evaluates an expression and checks the result is numeric, if not it does a type mismatch. The result of the expression is returned in FAC1.

LAB_CTNM
Check if source is numeric, else do type mismatch.

LAB_CTST
Check if source is string, else do type mismatch.

LAB_CKTM
Type match check, set carry for string, clear carry for numeric.

LAB_EVEX
Evaluate expression.

LAB_GVAL
Get numeric value from line. Returns the result in FAC1.
LAB_SCCA
Scan for the byte in A as the next byte. If so return here, else do syntax error then warm start.

LAB_SNER
Do syntax error, then warm start.

LAB_CASC
Check byte is alpha ("A" to "Z" or "a" to "z"), return carry clear if so.

LAB_EVIN
Evaluate integer expression. Return integer in FAC1_3/FAC1_2 (low/high).

LAB_EVPI
Evaluate positive integer expression.

LAB_EVIR
Evaluate integer expression, check is in range -32786 to 32767

LAB_FCER
Do function call error, then warm start.

LAB_CKRN
Check that the interpreter is not in immediate mode. If not then return, if so do illegal direct error.

LAB_GARB
Perform garbage collection routine.

LAB_EVST
Evaluate string.

LAB_ESGL
Evaluate string, return string length in Y.

LAB_SGBY
Scan and get byte parameter, return the byte in X.

LAB_GTBY
Get byte parameter and ensure numeric type, else do type mismatch error. Return the byte in X.

LAB_EVBY
Evaluate byte expression, return the byte in X.

LAB_GADB
Get two parameters as in POKE or WAIT. Return the byte (second parameter) in X and the integer (first parameter) in the temporary integer pair, Itempl/Itemph.

LAB_SCGB
Scan for "," and get byte, else do Syntax error then warm start. Return the byte in X.

LAB_F2FX
New convert float to fixed routine. accepts any value that fits into 24 bits, positive or negative and converts it into a right truncated integer in the temporary integer pair, Itempl/Itemph.

LAB_UFAC
Unpack the four bytes starting (AY) into FAC1 as a floating point number.

LAB_PFAC
Pack the floating point number in FAC1 into the current variable (Lvarpl).

LAB_STFA
Stores a 16 bit number in FAC1. Set X to the exponent required (usually $90) and the carry set for positive numbers and clear for negative numbers. The routine will clear FAC1 mantissa3 and then normalise it.

LAB_AYFC
Save integer AY (A = high byte, Y = low byte) in FAC1 and convert to float. The result will be -32768 to +32767.

LAB_MSSP
Make string space A bytes long. This returns the following. str_ln = A = string length str_pl = Sutill = string pointer low byte str_ph = Sutilh = string pointer high byte

LAB_RTST
Return string. Takes the string described instr_ln, str_pl and str_ph and puts it on the string stack. This is how you return a string to BASIC.

WE816 Hardware Reference

Using Supermon
The WE816 computer utilizes BCS Technology’s (http://sbc.bcstechnology.net/) Supermon 816 monitor program for its machine language monitor. To access Supermon, type ‘MONITOR’ from BASIC. You will be greeted by Supermon’s welcome screen.

__ _____ ___ __ __
/ /| ____|/ _ \/_ | / /
/ /_| |__ | (_) || |/ /_
| _ \___ \ > _ < | | _ \
| (_) |__) | (_) || | (_) |
\___/____/ \___/ |_|\___/

65c816 BIOS (NATIVE MODE)
v0.55 4/9/2021 - D.WERNER
PB PC | NVmxDIZC .C | .X | .Y | SP
F2 4F58 00110000 0000 0000 0000 7FFF DP DB
0000 00

From the ‘.’ Prompt, you can enter any of Supermon’s commands.

- A | Assemble code
- C | Compare memory regions
- D | Disassemble code
- F | Fill memory region (cannot span banks)
- G | Execute code (stops at BRK)
- H | Search (hunt) memory
- J | Execute code as a subroutine (stops at BRK or RTS)
- L | Load Motorola S28-records
- M | Dump & display memory range
- R | Dump & display 65C816 registers
- T | Copy (transfer) memory region
- > | Modify up to 32 bytes of memory
- ; | Modify 65C816 registers

Supermon 816 accepts binary (%), octal (@), decimal (+) and hexadecimal ($) as input for numeric parameters. Additionally, the H and > operations accept an ASCII string in place of numeric values by preceding the string with ', e.g.:

h 042000 042FFF 'BCS Technology Limited

If no radix symbol is entered hex is assumed.

Numeric conversion is also available. For example, typing:
| +1234567 [CR]

at the monitor's prompt will display:
$12D687
+1234567
@04553207
%100101101011010000111

In the above example, [CR] means the console keyboard's return or enter key.

All numeric values are internally processed as 32 bit unsigned integers. Addresses may be entered as 8, 16 or 24 bit values. During instruction assembly immediate mode operands may be forced to 16 bits by preceding the operand with an exclamation point if the instruction can accept a 16 bit operand, e.g.:

a 1f2000 lda !#4

The above will assemble as:

A 1F2000 A9 04 00 LDA #$0004

Entering:

a 1f2000 ldx !#+157

will assemble as:

A 1F2000 A2 9D 00 LDX #$009D

Absent the ! in the operand field, the above would have been assembled as:

A 1F2000 A2 9D | LDX #$9D

If an immediate mode operand is greater than $FF, assembly of a 16 bit operand is implied.

Redirecting Console to the Serial Port

The WE816 computer defaults console input/output to it’s built in keyboard and display, however it is possible to change the console display from internal to the serial port. Location $0341 in memory tells the computer which to use. If $341 contains a $01, the system will use the internal console, and value $00 designates the serial port.

To change the console using Supermon 816, enter:
>0341 00[ENTER]

And the system will change to the serial console. Entering:
>0341 01[ENTER]

Will change back to the internal video and keyboard.

Set the Real Time Clock

Setting the real time clock is easiest to do from Supermon. Locations $FE40-$FE47 can be written to from the monitor using the ‘>’ command. The RTC chip stores the time and date in binary coded decimal, so there is not even any need to do a conversion. To set the clock to ’10:51PM 01/02/2024’ one only needs to use the command:

>FE40 00 51 22 03 02 01 24 20[ENTER]

The format is [seconds] [minutes] [hours(24)] [day of week] [date] [month] [year] [century].

Additional information on the DS1501 RTC chip can be found in the DS1501 data sheet.

Returning to BASIC

To return to BASIC from Supermon 816, just execute the “G” command with the address of the BASIC startup code.
G FF1000[ENTER]

Screen Font

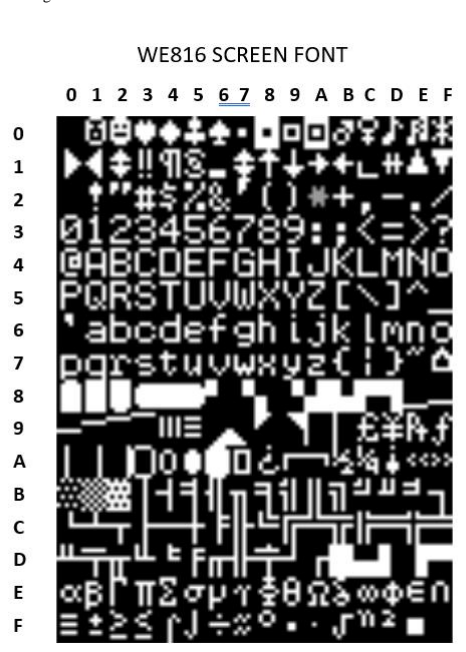
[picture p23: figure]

The following is the screen font for the WE816.

Musical Note to “Frequencies”

value

Produced

| freq | note | Note
| | | freq | variance | out of
| | | | | tune
14 | 7990.313 | B8 | 7902.13 | -
| | | | 88.1825 | 1%
15 | 7457.625 | A8 | 7040 | -
| | | | 417.625 | 6%
16 | 6991.523 G#8/Ab8 6644.88
| | | | 346.643 | 5%
17 | 6580.257 | G8 | 6271.93 | -
| | | | 308.327 | 5%
18 | 6214.688 F#8/Gb8 5919.91
| | | | 294.778 | 5%
20 | 5593.219 | F8 | 5587.65 | -
| | | | 5.56875 | 0%
21 | 5326.875 | E8 | 5274.04 | -52.835 | 1%
22 | 5084.744 D#8/Eb8 4978.03
| | | | 106.714 | 2%
23 | 4863.668 | D8 | 4698.63 | -
| | | | 165.038 | 3%
25 | 4474.575 C#8/Db8 4434.92 | -39.655 | 1%
26 | 4302.476 | C8 | 4186.01 | -
| | | | 116.466 | 3%
28 | 3995.156 | B7 | 3951.07 | -
| | | | 44.0862 | 1%
29 | 3857.392 A#7/Bb7 3729.31
| | | | 128.082 | 3%
31 | 3608.528 | A7 | 3520 | -
| | | | 88.5282 | 2%
33 | 3389.83 G#7/Ab7 3322.44
| | | | 67.3895 | 2%
37 | 3023.361 F#7/Gb7 2959.96
| | | | 63.4015 | 2%
42 | 2663.438 | E7 | 2637.02 | -
| | | | 26.4175 | 1%
44 | 2542.372 D#7/Eb7 2489.02
| | | | 53.3522 | 2%
47 | 2380.093 | D7 | 2349.32 | -
| | | | 30.7731 | 1%
50 | 2237.288 C#7/Db7 2217.46
| | | | 19.8275 | 1%
53 | 2110.649 | C7 | 2093 | -
| | | | 17.6486 | 1%
56 | 1997.578 | B6 | 1975.53 | -
| | | | 22.0481 | 1%
59 | 1896.006 A#6/Bb6 1864.66
| | | | 31.3464 | 2%
63 | 1775.625 | A6 | 1760 | -15.625 | 1%

67 1669.618 G#6/Ab6 1661.22

| | | 8.39754 | 1%
71 | 1575.555 | G6 | 1567.98
| | | 7.57458 | 0%
75 | 1491.525 F#6/Gb6 1479.98 | -11.545 | 1%
84 | 1331.719 | E6 | 1318.51
| | | 13.2088 | 1%
89 | 1256.903 D#6/Eb6 1244.51
| | | 12.3931 | 1%
95 | 1177.52 | D6 | 1174.66
| | | 2.85974 | 0%
100 | 1118.644 C#6/Db6 1108.73
| | | 9.91375 | 1%
106 | 1055.324 | C6 | 1046.5
| | | 8.82429 | 1%
113 | 989.9502 | B5 | 987.77
| | | 2.18022 | 0%
119 | 940.0368 A#5/Bb5 | 932.33 | -
| | | 7.70676 | 1%
127 | 880.8219 | A5 | 880
| | | 0.82185 | 0%
134 | 834.8088 G#5/Ab5 | 830.61 | -
| | | 4.19877 | 1%
142 | 787.7773 | G5 | 783.99
| | | 3.78729 | 0%
151 | 740.8237 F#5/Gb5 | 739.99 | -
| | | 0.83368 | 0%
160 | 699.1523 | F5 | 698.46
| | | 0.69234 | 0%
169 | 661.9194 | E5 | 659.25
| | | 2.66938 | 0%
179 | 624.9406 D#5/Eb5 | 622.25 | -
| | | 2.69064 | 0%
190 | 588.7599 | D5 | 587.33
| | | 1.42987 | 0%
201 | 556.5392 C#5/Db5 | 554.37 | -
| | | 2.16918 | 0%
213 | 525.1849 | C5 | 523.25
| | | 1.93486 | 0%
226 | 494.9751 | B4 | 493.88
| | | 1.09511 | 0%
239 | 468.0518 A#4/Bb4 | 466.16 | -
| | | 1.89178 | 0%
254 | 440.4109 | A4 | 440
| | | 0.41093 | 0%
269 | 415.8527 G#4/Ab4 | 415.3 | -0.5527 | 0%
285 | 392.5066 | G4 | 392
| | | 0.50658 | 0%
302 | 370.4118 F#4/Gb4 | 369.99 | -
| | | 0.42184 | 0%
339 | 329.9834 | E4 | 329.63
| | | 0.35341 | 0%

359 | 311.5999 D#4/Eb4 | 311.13
| | | | 0.46993 | 0%
380 | 294.3799 | D4 | 293.66 | -
| | | | 0.71993 | 0%
403 | 277.5791 C#4/Db4 | 277.18
| | | | 0.39909 | 0%
427 | 261.9775 | C4 | 261.63 | -
| | | | 0.34746 | 0%
453 | 246.9412 | B3 | 246.94 | -
| | | | 0.00123 | 0%
479 | 233.5373 A#3/Bb3 | 233.08
| | | | 0.45732 | 0%
508 | 220.2055 | A3 | 220 | -
| | | | 0.20546 | 0%
570 | 196.2533 | G3 | 196 | -
| | | | 0.25329 | 0%
604 | 185.2059 F#3/Gb3 | 185
| | | | 0.20592 | 0%
640 | 174.7881 | F3 | 174.61 | -
| | | | 0.17809 | 0%
678 | 164.9917 | E3 | 164.81 | -0.1817 | 0%
719 | 155.5833 D#3/Eb3 | 155.56
| | | | 0.02328 | 0%
761 | 146.9966 | D3 | 146.83 | -
| | | | 0.16655 | 0%
807 | 138.6176 C#3/Db3 | 138.59
| | | | 0.02757 | 0%
855 | 130.8355 | C3 | 130.81 | -
| | | | 0.02553 | 0%
906 | 123.4706 | B2 | 123.47 | -
| | | | 0.00061 | 0%
959 | 116.6469 A#2/Bb2 | 116.54 | -0.1069 | 0%
1016 | 110.1027 | A2 | 110 | -
| | | | 0.10273 | 0%
1077 | 103.8666 G#2/Ab2 | 103.83
| | | | 0.03664 | 0%
1141 | 98.04064 | G2 | 98 | -
| | | | 0.04064 | 0%
1209 | 92.52636 F#2/Gb2 | 92.5
| | | | 0.02636 | 0%
1281 | 87.32582 | F2 | 87.31 | -
| | | | 0.01582 | 0%
1357 | 82.43506 | E2 | 82.41 | -
| | | | 0.02506 | 0%
1438 | 77.79164 D#2/Eb2 | 77.78
| | | | 0.01164 | 0%
1523 | 73.45002 | D2 | 73.42 | -
| | | | 0.03002 | 0%
1614 | 69.30878 C#2/Db2 | 69.3
| | | | 0.00878 | 0%
1710 | 65.41776 | C2 | 65.41 | -
| | | | 0.00776 | 0%

1811 | 61.7694 | B1 | 61.74 | -0.0294 | 0%
1919 | 58.29306 A#1/Bb1 | 58.27
| | | | 0.02306 | 0%
2033 | 55.02429 | A1 | 55 | -
| | | | 0.02429 | 0%
2154 | 51.93332 G#1/Ab1 | 51.91
| | | | 0.02332 | 0%
2282 | 49.02032 | G1 | 49 | -
| | | | 0.02032 | 0%
2418 | 46.26318 F#1/Gb1 | 46.25
| | | | 0.01318 | 0%
2562 | 43.66291 | F1 | 43.65 | -
| | | | 0.01291 | 0%
2715 | 41.20235 | E1 | 41.2 | -
| | | | 0.00235 | 0%
2876 | 38.89582 D#1/Eb1 | 38.89
| | | | 0.00582 | 0%
3047 | 36.71296 | D1 | 36.71 | -
| | | | 0.00296 | 0%
3228 | 34.65439 C#1/Db1 | 34.65
| | | | 0.00439 | 0%
3420 | 32.70888 | C1 | 32.7 | -
| | | | 0.00888 | 0%
3623 | 30.87617 | B0 | 30.87 | -
| | | | 0.00617 | 0%
3838 | 29.14653 A#0/Bb0 | 29.14
| | | | 0.00653 | 0%
4067 | 27.50538 | A0 | 27.5 | -
| | | | 0.00538 | 0%

Memory Map

Address
(Decimal) | Address (Hex) | Label | Comment
0 00:0000 | LAB_WARM | BASIC warm start entry point
1 00:0001 | Wrmjpl | BASIC warm start vector jump low byte
2 00:0002 | Wrmjph | BASIC warm start vector jump high byte
4 00:0004 | TMPFLG | BASIC Temp area
6 00:0006 | VIDEOMODE | BASIC Current Video Mode
7 00:0007 | LOCALWORK | word (2 bytes)
10 00:000A | Usrjmp | USR function JMP address
11 00:000B | Usrjpl | USR function JMP vector low byte
12 00:000C | Usrjph | USR function JMP vector high byte
13 00:000D | Nullct | nulls output after each line
14 00:000E | TPos | BASIC terminal position byte
15 00:000F | TWidth | BASIC terminal width byte
16 00:0010 | Iclim | input column limit
17 00:0011 | Itempl | temporary integer low byte
18 00:0012 | Itemph | temporary integer high byte
17 00:0011 | nums_1 | number to bin/hex string convert MSB
18 00:0012 | nums_2 | number to bin/hex string convert
19 00:0013 | nums_3 | number to bin/hex string convert LSB
91 00:005B | Srchc | search character
91 00:005B | Temp3 | temp byte used in number routines
92 00:005C | Scnquo | scan-between-quotes flag
92 00:005C | Asrch | alt search character
91 00:005B | XOAw_l | eXclusive OR, OR and AND word low byte
92 00:005C | XOAw_h | eXclusive OR, OR and AND word high byte
93 00:005D | Ibptr | input buffer pointer
93 00:005D | Dimcnt | # of dimensions
93 00:005D | Tindx | token index
94 00:005E | Defdim | default DIM flag
95 00:005F | Dtypef | data type flag, $FF=string, $00=numeric
96 00:0060 | Oquote | open quote flag (b7) (Flag: DATA scan
96 00:0060 | Gclctd | garbage collected flag
97 00:0061 | Sufnxf | subscript/FNX flag, 1xxx xxx = FN(0xxx xxx)
98 00:0062 | Imode | input mode flag, $00=INPUT, $80=READ
99 00:0063 | Cflag | comparison evaluation flag
100 00:0064 | TabSiz | TAB step size (was input flag)
101 00:0065 | next_s | next descriptor stack address
| | | these two bytes form a word pointer to the item
| | | currently on top of the descriptor stack
102 00:0066 | last_sl | last descriptor stack address low byte
103 00:0067 | last_sh | last descriptor stack address high byte (always $00)
104 00:0068 | des_sk | descriptor stack start address (temp strings)
112 00:0070 | End of descriptor stack
113 00:0071 | ut1_pl | utility pointer 1 low byte

114 00:0072 | ut1_ph | utility pointer 1 high byte
115 00:0073 | ut2_pl | utility pointer 2 low byte
116 00:0074 | ut2_ph | utility pointer 2 high byte
113 00:0071 | Temp_2 | temp byte for block move
117 00:0075 | FACt_1 | FAC temp mantissa1
118 00:0076 | FACt_2 | FAC temp mantissa2
119 00:0077 | FACt_3 | FAC temp mantissa3
118 00:0076 | dims_l | array dimension size low byte
119 00:0077 | dims_h | array dimension size high byte
120 00:0078 | TempB | temp page 0 byte
121 00:0079 | Smeml | start of mem low byte (Start-of-Basic)
122 00:007A | Smemh | start of mem high byte (Start-of-Basic)
123 00:007B | Svarl | start of vars low byte (Start-of-Variables)
124 00:007C | Svarh | start of vars high byte (Start-of-Variables)
125 00:007D | Sarryl | var mem end low byte (Start-of-Arrays)
126 00:007E | Sarryh | var mem end high byte (Start-of-Arrays)
127 00:007F | Earryl | array mem end low byte (End-of-Arrays)
128 00:0080 | Earryh | array mem end high byte (End-of-Arrays)
129 00:0081 | Sstorl | string storage low byte (String storage (moving down))
130 00:0082 | Sstorh | string storage high byte (String storage (moving down))
131 00:0083 | Sutill | string utility ptr low byte
132 00:0084 | Sutilh | string utility ptr high byte
133 00:0085 | Ememl | end of mem low byte (Limit-of-memory)
134 00:0086 | Ememh | end of mem high byte (Limit-of-memory)
135 00:0087 | Clinel | current line low byte (Basic line number)
136 00:0088 | Clineh | current line high byte (Basic line number)
137 00:0089 | Blinel | break line low byte (Previous Basic line number)
138 00:008A | Blineh | break line high byte (Previous Basic line number)
139 00:008B | Cpntrl | continue pointer low byte
140 00:008C | Cpntrh | continue pointer high byte
141 00:008D | Dlinel | current DATA line low byte
142 00:008E | Dlineh | current DATA line high byte
143 00:008F | Dptrl | DATA pointer low byte
144 00:0090 | Dptrh | DATA pointer high byte
145 00:0091 | Rdptrl | read pointer low byte
146 00:0092 | Rdptrh | read pointer high byte
147 00:0093 | Varnm1 | current var name 1st byte
148 00:0094 | Varnm2 | current var name 2nd byte
149 00:0095 | Cvaral | current var address low byte
150 00:0096 | Cvarah | current var address high byte
151 00:0097 | Frnxtl | var pointer for FOR/NEXT low byte
151 00:0097 | Tidx1 | temp line index
151 00:0097 | Lvarpl | let var pointer low byte
152 00:0098 | Frnxth | var pointer for FOR/NEXT high byte
152 00:0098 | Lvarph | let var pointer high byte
153 00:0099 | prstk | precedence stacked flag
155 00:009B | comp_f | compare function flag, bits 0,1 and 2 used

bit 2 set if >
bit 1 set if =
bit 0 set if <
156 00:009C | func_l | function pointer low byte
157 00:009D | func_h | function pointer high byte
156 00:009C | garb_l | garbage collection working pointer low byte
157 00:009D | garb_h | garbage collection working pointer high byte
158 00:009E | des_2l | string descriptor_2 pointer low byte
159 00:009F | des_2h | string descriptor_2 pointer high byte
160 00:00A0 | g_step | garbage collect step size
161 00:00A1 | Fnxjmp | jump vector for functions
162 00:00A2 | Fnxjpl | functions jump vector low byte
162 00:00A2 | g_indx | garbage collect temp index
163 00:00A3 | Fnxjph | functions jump vector high byte
163 00:00A3 | FAC2_r | FAC2 rounding byte
164 00:00A4 | Adatal | array data pointer low byte
164 00:00A4 | Nbendl | new block end pointer low byte
165 00:00A5 | Adatah | array data pointer high byte
165 00:00A5 | Nbendh | new block end pointer high byte
166 00:00A6 | Obendl | old block end pointer low byte
167 00:00A7 | Obendh | old block end pointer high byte
168 00:00A8 | numexp | string to float number exponent count
168 00:00A8 | numbit | bit count for array element calculations
169 00:00A9 | expcnt | string to float exponent count
170 00:00AA | numdpf | string to float decimal point flag
170 00:00AA | Astrtl | array start pointer low byte
171 00:00AB | expneg | string to float eval exponent -ve flag
171 00:00AB | Astrth | array start pointer high byte
170 00:00AA | Histrl | highest string low byte
171 00:00AB | Histrh | highest string high byte
170 00:00AA | Baslnl | BASIC search line pointer low byte
171 00:00AB | Baslnh | BASIC search line pointer high byte
170 00:00AA | Fvar_l | find/found variable pointer low byte
171 00:00AB | Fvar_h | find/found variable pointer high byte
170 00:00AA | Ostrtl | old block start pointer low byte
171 00:00AB | Ostrth | old block start pointer high byte
170 00:00AA | Vrschl | variable search pointer low byte
171 00:00AB | Vrschh | variable search pointer high byte
172 00:00AC | FAC1_e | FAC1 exponent
173 00:00AD | FAC1_1 | FAC1 mantissa1
174 00:00AE | FAC1_2 | FAC1 mantissa2
175 00:00AF | FAC1_3 | FAC1 mantissa3
176 00:00B0 | FAC1_s | FAC1 sign (b7)
172 00:00AC | str_ln | string length
173 00:00AD | str_pl | string pointer low byte
174 00:00AE | str_ph | string pointer high byte
174 00:00AE | des_pl | string descriptor pointer low byte

175 00:00AF | des_ph | string descriptor pointer high byte
175 00:00AF | mids_l | MID$ string temp length byte
177 00:00B1 | negnum | string to float eval -ve flag
177 00:00B1 | numcon | series evaluation constant count
178 00:00B2 | FAC1_o | FAC1 overflow byte
179 00:00B3 | FAC2_e | FAC2 exponent
180 00:00B4 | FAC2_1 | FAC2 mantissa1
181 00:00B5 | FAC2_2 | FAC2 mantissa2
182 00:00B6 | FAC2_3 | FAC2 mantissa3
183 00:00B7 | FAC2_s | FAC2 sign (b7)
184 00:00B8 | FAC_sc | FAC sign comparison, Acc#1 vs #2
185 00:00B9 | FAC1_r | FAC1 rounding byte
184 00:00B8 | ssptr_l | string start pointer low byte
185 00:00B9 | ssptr_h | string start pointer high byte
184 00:00B8 | sdescr | string descriptor pointer
186 00:00BA | csidx | line crunch save index
186 00:00BA | Asptl | array size/pointer low byte
187 00:00BB | Aspth | array size/pointer high byte
186 00:00BA | Btmpl | BASIC pointer temp low byte
187 00:00BB | Btmph | BASIC pointer temp low byte
186 00:00BA | Cptrl | BASIC pointer temp low byte
187 00:00BB | Cptrh | BASIC pointer temp low byte
186 00:00BA | Sendl | BASIC pointer temp low byte
187 00:00BB | Sendh | BASIC pointer temp low byte
188 00:00BC | LAB_IGBY | get next BASIC byte subroutine
194 00:00C2 | LAB_GBYT | get current BASIC byte subroutine
195 00:00C3 | Bpntrl | BASIC execute (get byte) pointer low byte
196 00:00C4 | Bpntrh | BASIC execute (get byte) pointer high byte
197 00:00C5 | Bpntrp | BASIC execute (get byte) pointer PAGE byte
224 00:00E0 | | end of get BASIC char subroutine
225 00:00E1 | Rbyte4 | extra PRNG byte
226 00:00E2 | Rbyte1 | most significant PRNG byte
227 00:00E3 | Rbyte2 | middle PRNG byte
228 00:00E4 | Rbyte3 | least significant PRNG byte
229 00:00E5 | NmiBase | NMI handler enabled/setup/triggered flags
| | bit function
| | === ========
| | 7 interrupt enabled
| | 6 interrupt setup
| | 5 interrupt happened
230 00:00E6 | | NMI handler addr low byte
231 00:00E7 | | NMI handler addr high byte
232 00:00E8 | IrqBase | IRQ handler enabled/setup/triggered flags
233 00:00E9 | | IRQ handler addr low byte
234 00:00EA | | IRQ handler addr high byte
235 00:00EB | FCBPTR | POINTER TO FCB FOR FILE OPS
239 00:00EF | Decss | number to decimal string start

240 00:00F0 | Decssp1 | number to decimal string start
253 00:00FD | TEMPW
255 00:00FF | | decimal string end

256-511

00:0100-
00:01FF | 6502Stack | Left Free for 6502 Emulation Mode Stack

512-767

00:0200-
00:02FF | KEYBUFF | 256 BYTE KEYBOARD BUFFER
| | NATIVE VECTORS
768 00:0300 | ICOPVECTOR | COP handler indirect vector...
770 00:0302 | IBRKVECTOR | BRK handler indirect vector...
772 00:0304 | IABTVECTOR | ABT handler indirect vector...
774 00:0306 | INMIVECTOR | NMI handler indirect vector...
776 00:0308 | IIRQVECTOR | IRQ handler indirect vector...
| | 6502 Emulation Vectors
778 00:030A | IECOPVECTOR | ECOP handler indirect vector...
780 00:030C | IEABTVECTOR | EABT handler indirect vector...
782 00:030E | IENMIVECTOR | ENMI handler indirect vector...
784 00:0310 | IEINTVECTOR | EINT handler indirect vector...
| | IEC Driver work Area
786 00:0312 | IECDCF | Serial output: deferred char flag
787 00:0313 | IECDC | Serial deferred character
788 00:0314 | IECBCI | Serial bit count/EOI flag
789 00:0315 | IECBTC | Countdown, bit count
790 00:0316 | IECCYC | Cycle count
791 00:0317 | IECSTW | Status word
792 00:0318 | IECFNLN | File Name Length
793 00:0319 | IECSECAD | IEC Secondary Address
794 00:031A | IECBUFFL | low byte IEC buffer Pointer
795 00:031B | IECBUFFH | High byte IEC buffer Pointer
796 00:031C | IECDEVN | IEC Device Number
797 00:031D | IECSTRTL | low byte IEC Start Address Pointer
798 00:031E | IECSTRTH | High byte IEC Start Address Pointer
799 00:031F | IECMSGM | message mode flag,
| | $C0 = both control and kernal messages,
| | $80 = control messages only,
| | $40 = kernal messages only,
| | $00 = neither control or kernal messages
800 00:0320 | IECFNPL | File Name Pointer Low,
801 00:0321 | IECFNPH | File Name Pointer High,
802 00:0322 | LOADBUFL | low byte IEC buffer Pointer
803 00:0323 | LOADBUFH | High byte IEC buffer Pointer
804 00:0324 | LOADBANK | BANK buffer Pointer
805 00:0325 | IECOPENF | OPEN FILE COUNT
806 00:0326 | IECLFN | IEC LOGICAL FILE NUMBER
807 00:0327 | IECIDN | input device number
808 00:0328 | IECODN | output device number
| | VIDEO/KEYBOARD PARAMETER WORK AREA

816 00:0330 | CSRX | CURRENT X POSITION
817 00:0331 | CSRY | CURRENT Y POSITION
818 00:0332 | LEDS | Current Keyboard LED status
819 00:0333 | KeyLock | Current Keylock status
820 00:0334 | ScannedKey | Current Scanned Key
821 00:0335 | ScrollCount | Current Scroll Count
822 00:0336 | TEMP | TEMP AREA
833 00:0341 | ConsoleDevice | Current Console Device
| | $00 Serial, $01 On-Board vga/KB
834 00:0342 | CSRCHAR | Character under the Cursor
835 00:0343 | VIDEOWIDTH | SCREEN WIDTH -- 32 or 40 (80 in the future)
848 00:0344 | Default Color
849 00:0345-6 | Temp storage | Used for calculating video offsets
851 00:0347-8 | Temp storage | Used for calculating video offsets
944 00:03B0 | PTRLFT | .. to $03B9 logical file table
954 00:03BA | PTRDNT | .. to $03C3 device number table
964 00:03C4 | PTRSAT | .. to $03CD secondary address table

1001-4095

00:03F0-
00:0FFF | | OPEN

4096-8191

00:1000-
00:19FF | | Text Page 1
8192-
24575

00:2000-
00:5FFF | | Text Page 2, Graphics Page 1
24576-
40959

00:6000-
00:9FFF | | Graphics Page 2
45055 00:BFFF | STACK | TOP OF 65816 STACK
45056-
65535

00:C000-
00:FFFF | ROM
| | IO Area
65024 00:FE00 | UART0: | DATA IN/OUT
65025 00:FE01 | UART1: | CHECK RX
65026 00:FE02 | UART2: | INTERRUPTS
65027 00:FE03 | UART3: | LINE CONTROL
65028 00:FE04 | UART4: | MODEM CONTROL
65029 00:FE05 | UART5: | LINE STATUS
65030 00:FE06 | UART6: | MODEM STATUS
65040 00:FE10 | via1regb | Register (Sound Data)
65041 | 00:FE11 via1rega | Register (IEC,RTC, & Sound)
B0 - Serial Clock in
B1- Serial Data in
B2- Sound BDIR
B3- Sound BC1
B4- Sound BC2
B5- RTC DQ

B6- RTC RST
B7 - Serial ATN Out
65042 | 00:FE12 via1ddrb | Register
65043 | 00:FE13 via1ddra | Register
65044 00:FE14 | via1t1cl | Register
65045 00:FE15 | via1t1ch | Register
65046 00:FE16 | via1t1ll | Register
65047 00:FE17 | via1t1lh | Register
65048 00:FE18 | via1t2cl | Register
65049 00:FE19 | via1t2ch | Register
65050 00:FE1A | via1sr | Register
65051 00:FE1B | via1acr | Register
65052 00:FE1C | via1pcr | Register
65053 00:FE1D | via1ifr | Register
65054 00:FE1E | via1ier | Register
65055 00:FE1F | | via1ora | Register
65056 00:FE20 | via2regb | Register (KB ROW & LED control)
65057 | 00:FE21 via2rega | Register (KB Column)
65058 00:FE22 | via2ddrb | Register
65059 00:FE23 | via2ddra | Register
65060 00:FE24 | via2t1cl | Register
65061 00:FE25 | via2t1ch | Register
65062 00:FE26 | via2t1ll | Register
65063 00:FE27 | via2t1lh | Register
65064 00:FE28 | via2t2cl | Register
65065 00:FE29 | via2t2ch | Register
65066 00:FE2A | via2sr | Register
65067 00:FE2B | via2acr | Register
65068 00:FE2C | via2pcr | Register
65069 00:FE2D | via2ifr | Register
65070 00:FE2E | via2ier | Register
65071 00:FE2F | | via2ora | Register
65072 00:FE30 | | VideoScanlines | 01=ON, 02=OFF
65073 | 00:FE31 | VideoDisplayPage | 01=Page 1, 2=Page2
65074 00:FE32 | | VideoCharGenOffset | Character Generator write offset (character)
65075 00:FE33 | | VideoCharGenData | Character Generator write Data
65076 00:FE34 | | VideoTextMode | 01=ON, 02=OFF
65077 00:FE35 | | VideoCommandReg
65078 00:FE36 | | VideoLoresMode | 01=ON, 02=OFF
65079 00:FE37 | | VideoDoubleLores | 01=ON, 02=OFF
65070 00:FE38 | | VideoHiresMode | 01=ON, 02=OFF
65071 00:FE39 | | VideoDoubleHires | 01=ON, 02=OFF
65072 00:FE3A | Video80col | 01=80 col, 02=40 col
65073 00:FE3B | VideoMixedMode | 01=ON, 02=OFF
65074 00:FE3C | VideoQuadHires | 01=ON, 02=OFF

65075 00:FE3D | VideoMonoHires | 01=ON, 02=OFF
65088- 65119 00:FE40-FE5F | Real Time Clock Registers

01:0000-
07:FFFF | RAM | Basic uses 02:0000-02:FFFF for storage
FF:0000-
FF:FFFF | BASIC ROM

BIOS Jump Table (Native Long JSR)

64768 | 00:FD00 | LPRINTVEC | Print a character to the active console
64772 | 00:FD04 | LINPVEC | Get a character from the active console (no wait)
64776 00:FD08 | LINPWVEC | Get a character from the active console (wait)
64780 00:FD0C | LSetXYVEC | Set the Cursor position on the screen
64784 00:FD10
64788 00:FD14 | LSrlUpVEC | Scroll up the Screen
64792 00:FD18 | LSetColorVEC | Set the Color for the Screen
64796 00:FD1C | LCURSORVEC | Turn on the Cursor
64800 00:FD20 | LUNCURSORVEC | Turn Off the Cursor
64812 00:FD2C | LIECIN | Read byte from serial bus. (Must call TALK and TALKSA beforehands.)
64816 00:FD30 | LIECOUT | Write byte to serial bus. (Must call LISTEN and LSTNSA beforehands.)
64820 00:FD34 | LUNTALK | Send UNTALK command to serial bus.
64824 00:FD38 | LUNLSTN | Send UNLISTEN command to serial bus.
64828 00:FD3C | LLISTEN | Send LISTEN command to serial bus.
64832 00:FD40 | LTALK | Send TALK command to serial bus.
64836 00:FD44 | LSETLFS | Set file parameters.
64840 00:FD48 | LSETNAM | Set file name parameters.
64844 00:FD4C | LLOAD | Load or verify file. (Must call SETLFS and SETNAM beforehand.)
64848 00:FD50 | LSAVE | Save file. (Must call SETLFS and SETNAM beforehand.)
64852 00:FD54 | LIECINIT | INIT IEC
64856 00:FD58 | LIECCLCH | close input and output channels
64860 00:FD5C | LIECOUTC | open a channel for output
64864 00:FD60 | LIECINPC | open a channel for input
64868 00:FD64 | LIECOPNLF | open a logical file
64872 00:FD68 | LIECCLSLF | close a specified logical file
64876 00:FD6C | LClearScrVec | clear the Screen
64880 00:FD70
| | | BIOS Jump Table (Emulation, short JSR)
65393 00:FF71 | PRINTVEC | Print a character to the active console
65396 00:FF74 | INPVEC | Get a character from the active console (no wait)
65399 | 00:FF77 INPWVEC | Get a character from the active console (wait)
65402 | 00:FF7A SetXYVEC | Set the Cursor position on the screen
65405 00:FF7D
65408 00:FF80 | SrlUpVEC | Scroll up the Screen
65411 00:FF83 | SetColorVEC | Set the Color for the Screen
65414 00:FF86 | CURSORVEC | Turn on the Cursor

65417 00:FF89 | UNCURSORVEC | Turn Off theCursor
65426 00:FF92 | IECIN | Read byte from serial bus. (Must call TALK and TALKSA beforehands.)
65429 00:FF95 | IECOUT | Write byte to serial bus. (Must call LISTEN and LSTNSA beforehands.)
65432 00:FF98 | UNTALK | Send UNTALK command to serial bus.
65435 00:FF9B | UNLSTN | Send UNLISTEN command to serial bus.
65438 00:FF9E | LISTEN | Send LISTEN command to serial bus.
65441 00:FFA1 | TALK | Send TALK command to serial bus.
65444 00:FFA4 | SETLFS | Set file parameters.
65447 00:FFA7 | SETNAM | Set file name parameters.
65450 00:FFAA | LOAD | Load or verify file. (Must call SETLFS and SETNAM beforehand.)
65453 00:FFAD | SAVE | Save file. (Must call SETLFS and SETNAM beforehand.)
65456 00:FFB0 | IECINIT | INIT IEC
65459 00:FFB3 | IECCLCH | close input and output channels
65462 00:FFB6 | IECOUTC | open a channel for output
65465 00:FFB9 | IECINPC | open a channel for input
65468 00:FFBC | IECOPNLF | open a logical file
65471 00:FFBF | IECCLSLF | close a specified logical file
65474 00:FFC2 | ClearScrVec | clear the Screen
65477 00:FFC5

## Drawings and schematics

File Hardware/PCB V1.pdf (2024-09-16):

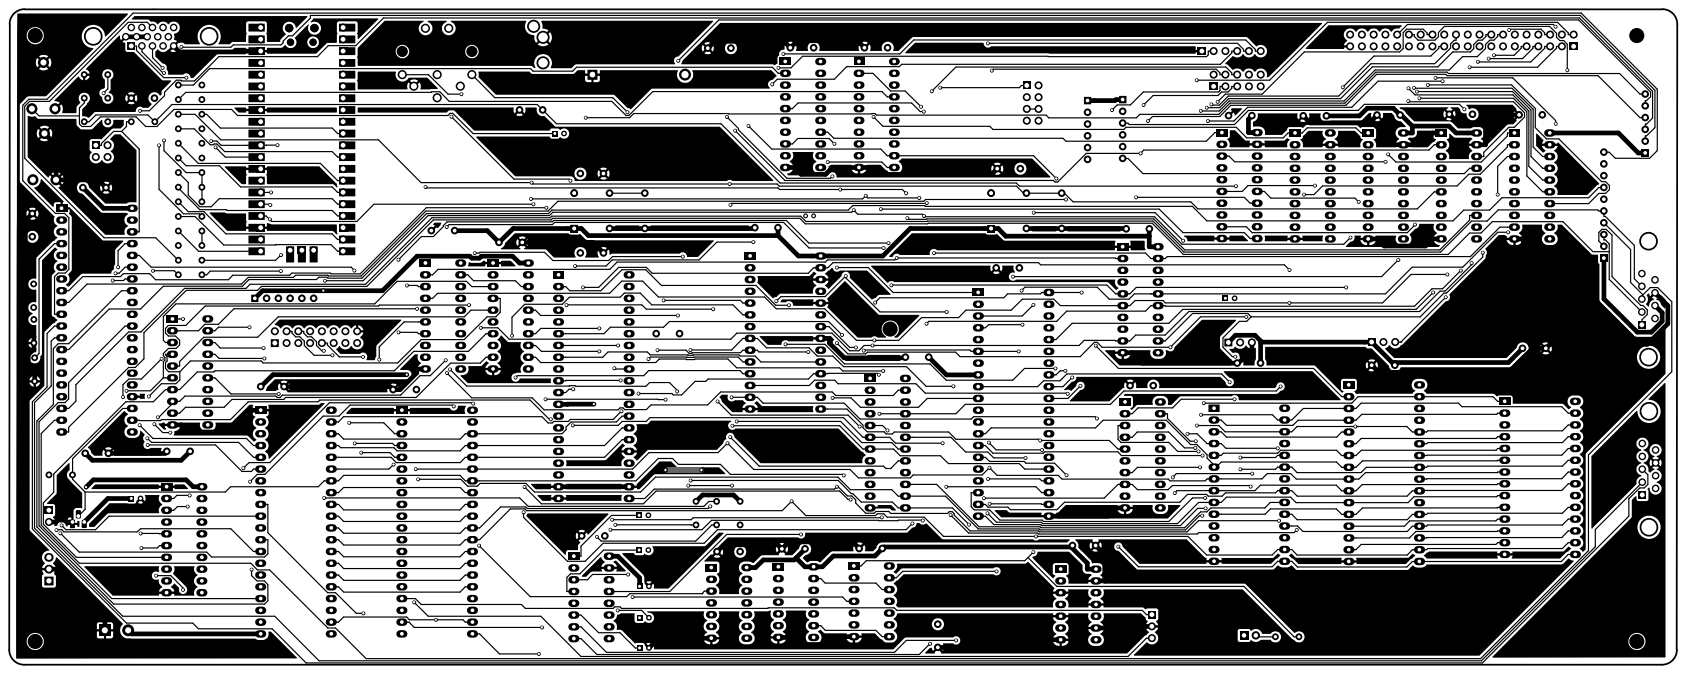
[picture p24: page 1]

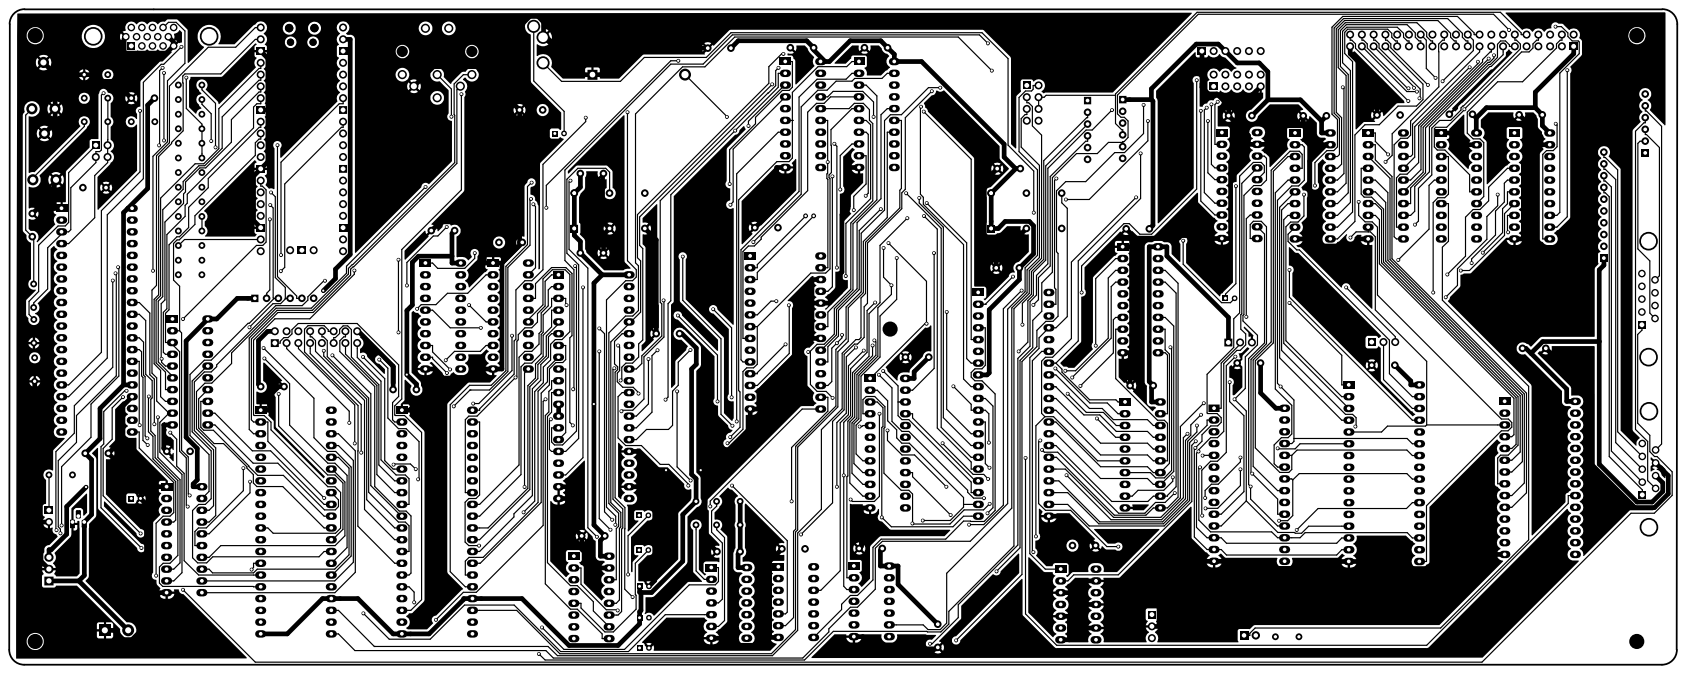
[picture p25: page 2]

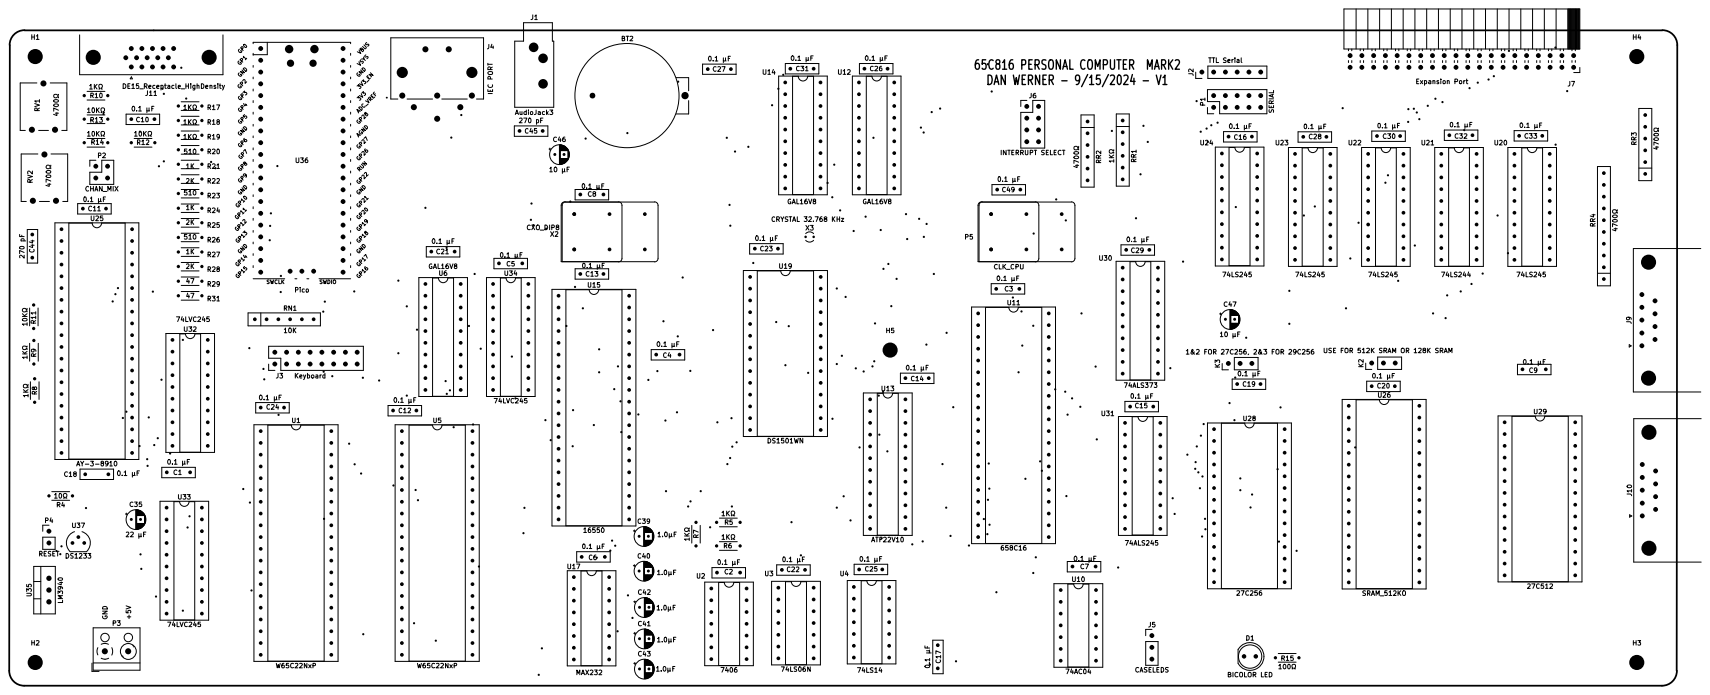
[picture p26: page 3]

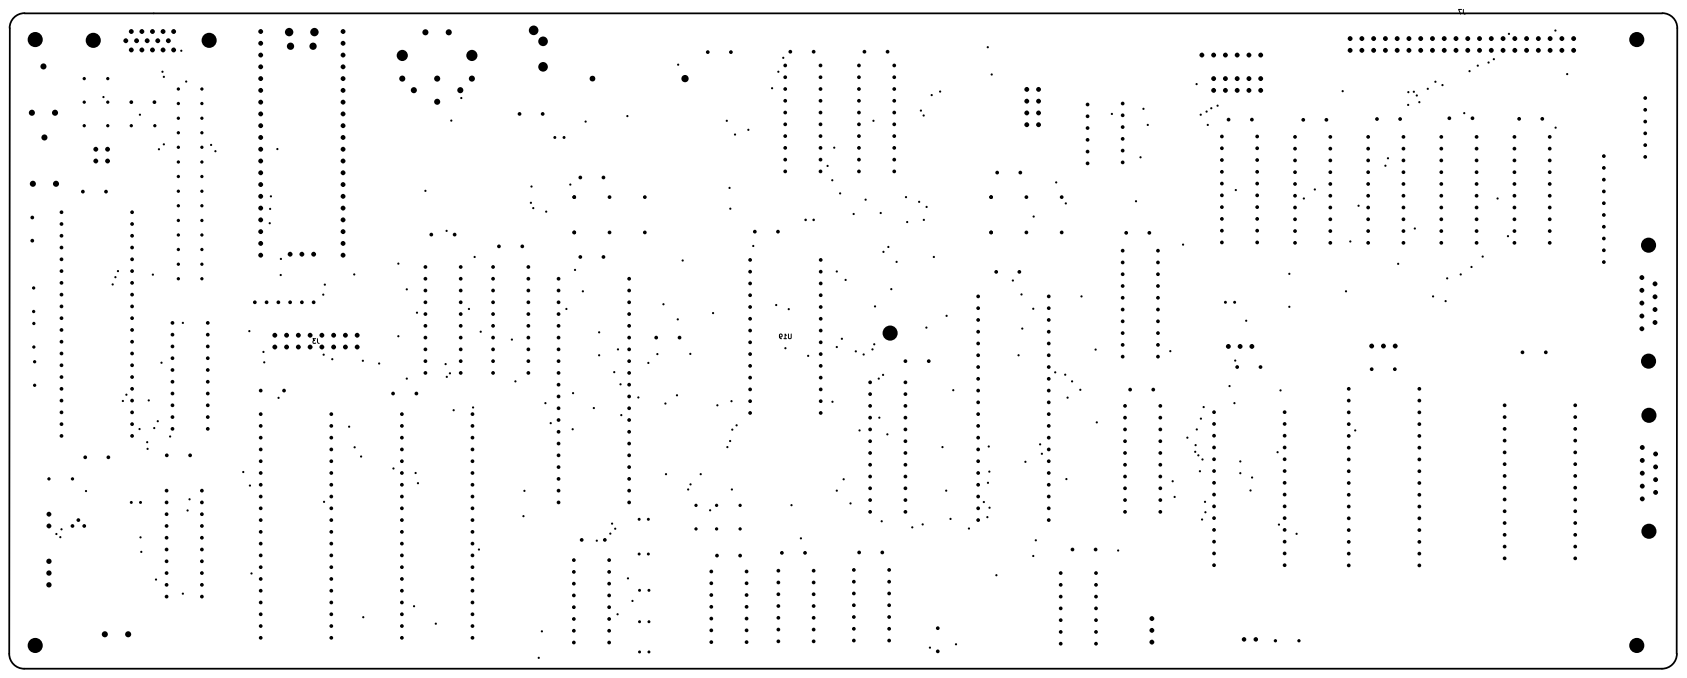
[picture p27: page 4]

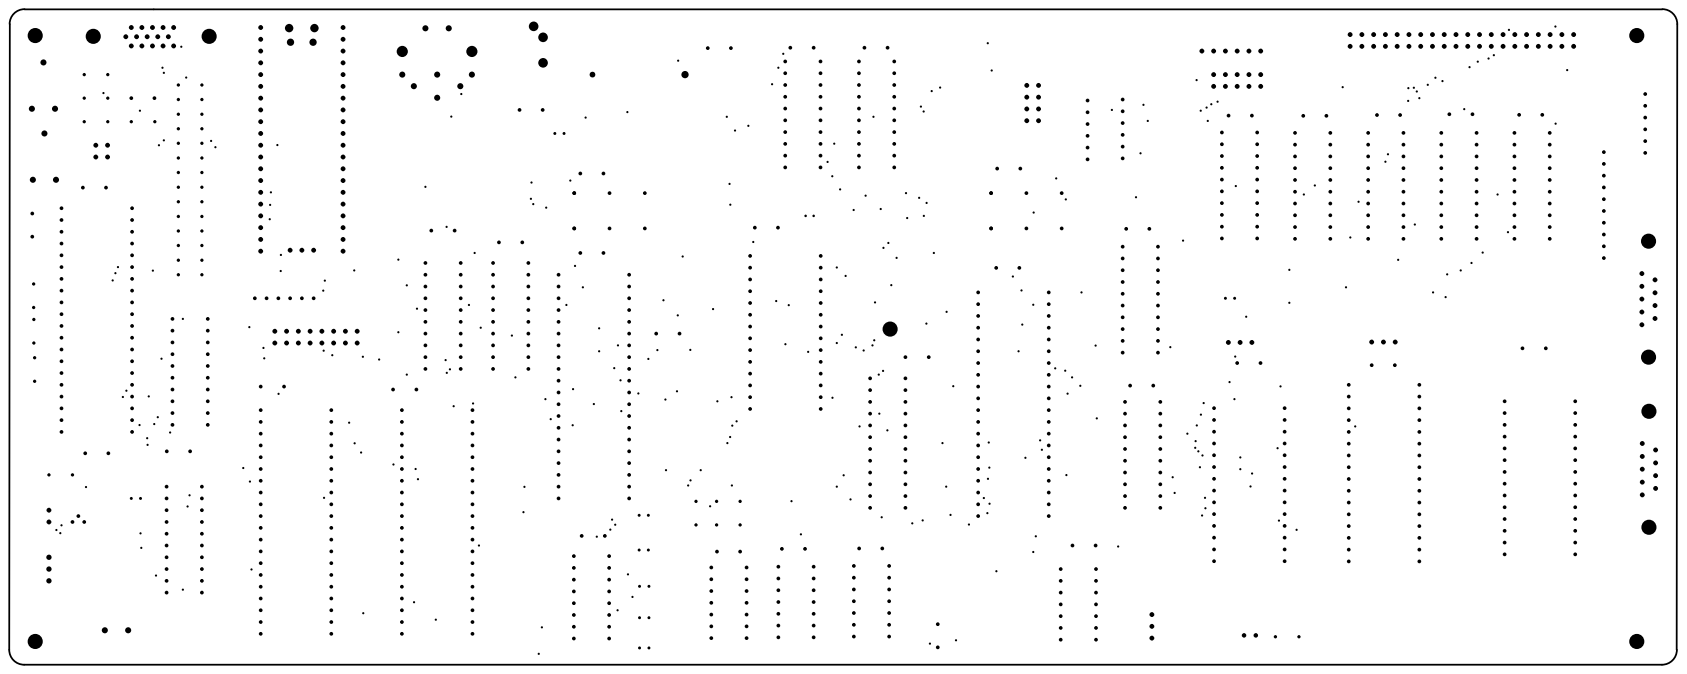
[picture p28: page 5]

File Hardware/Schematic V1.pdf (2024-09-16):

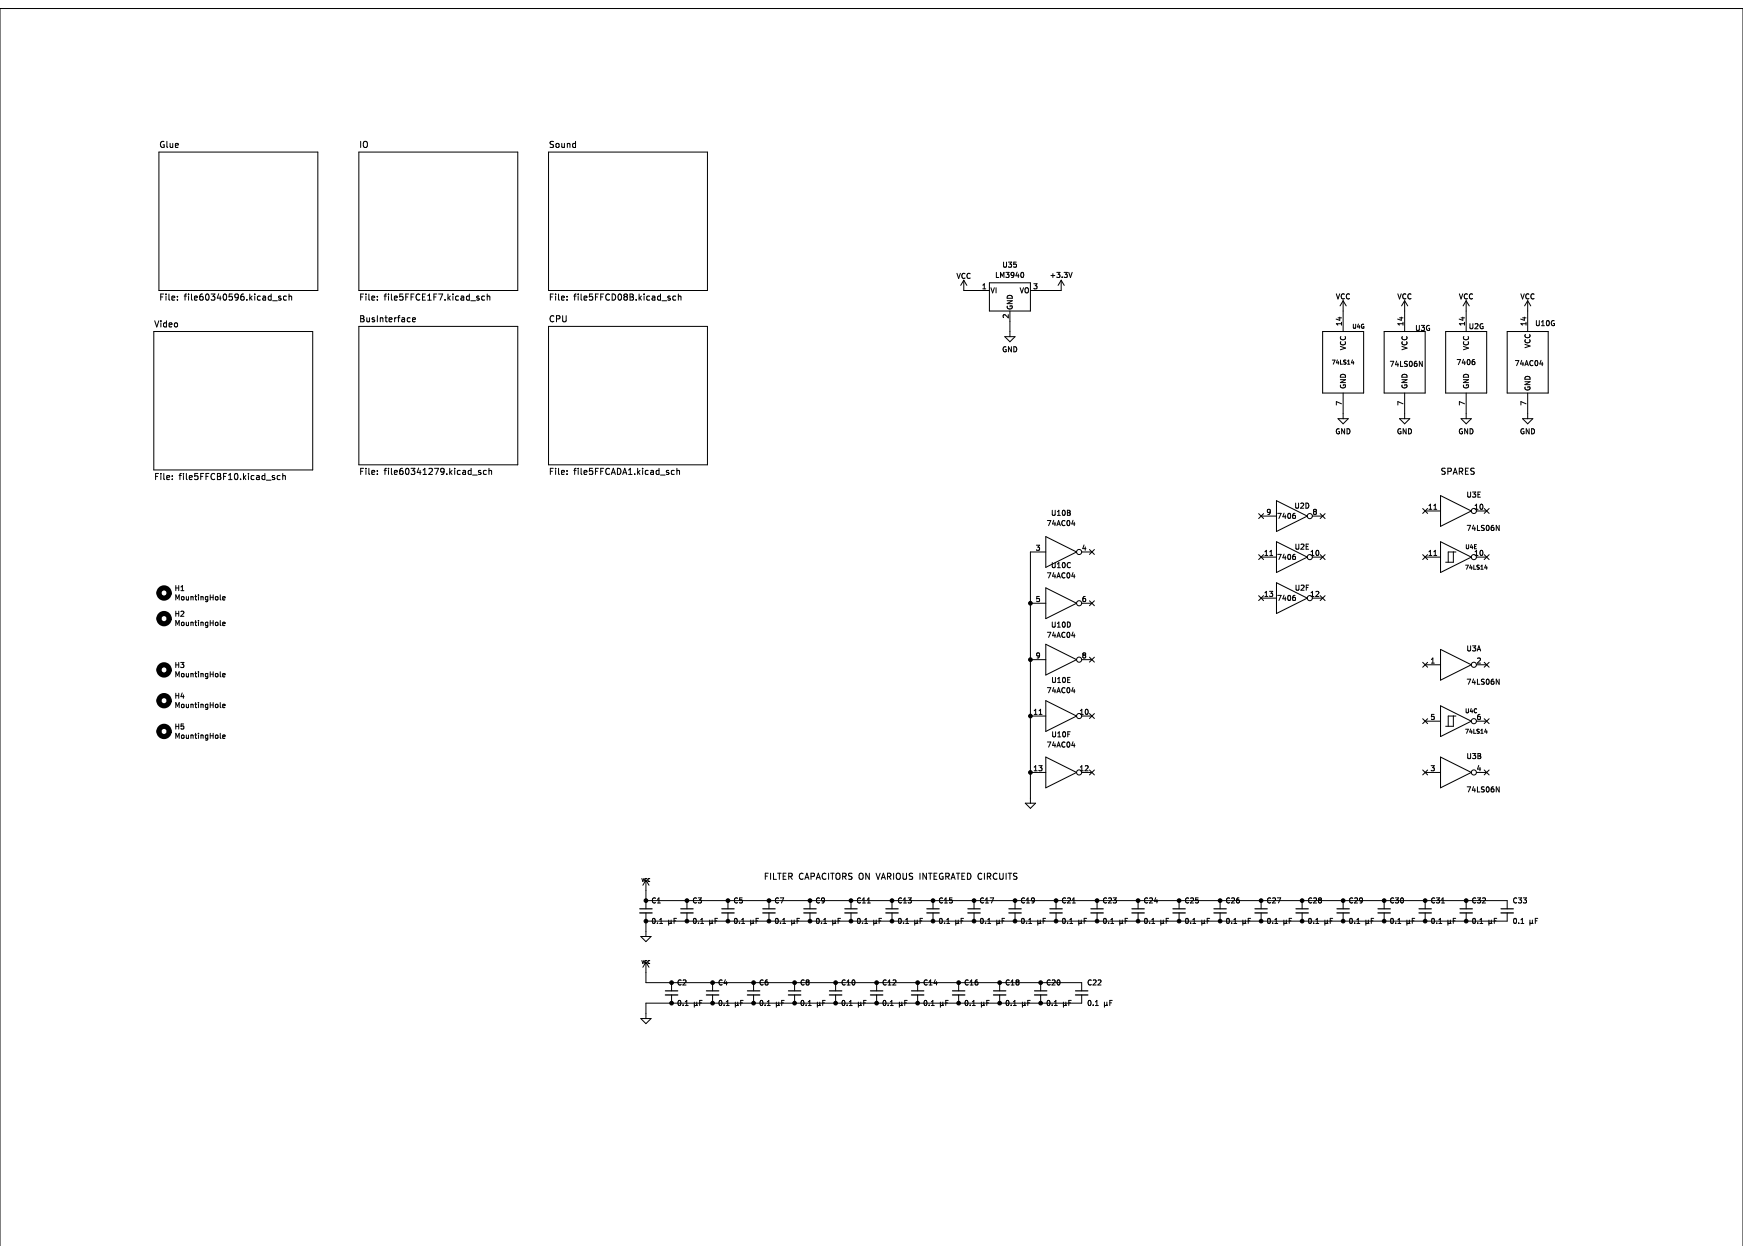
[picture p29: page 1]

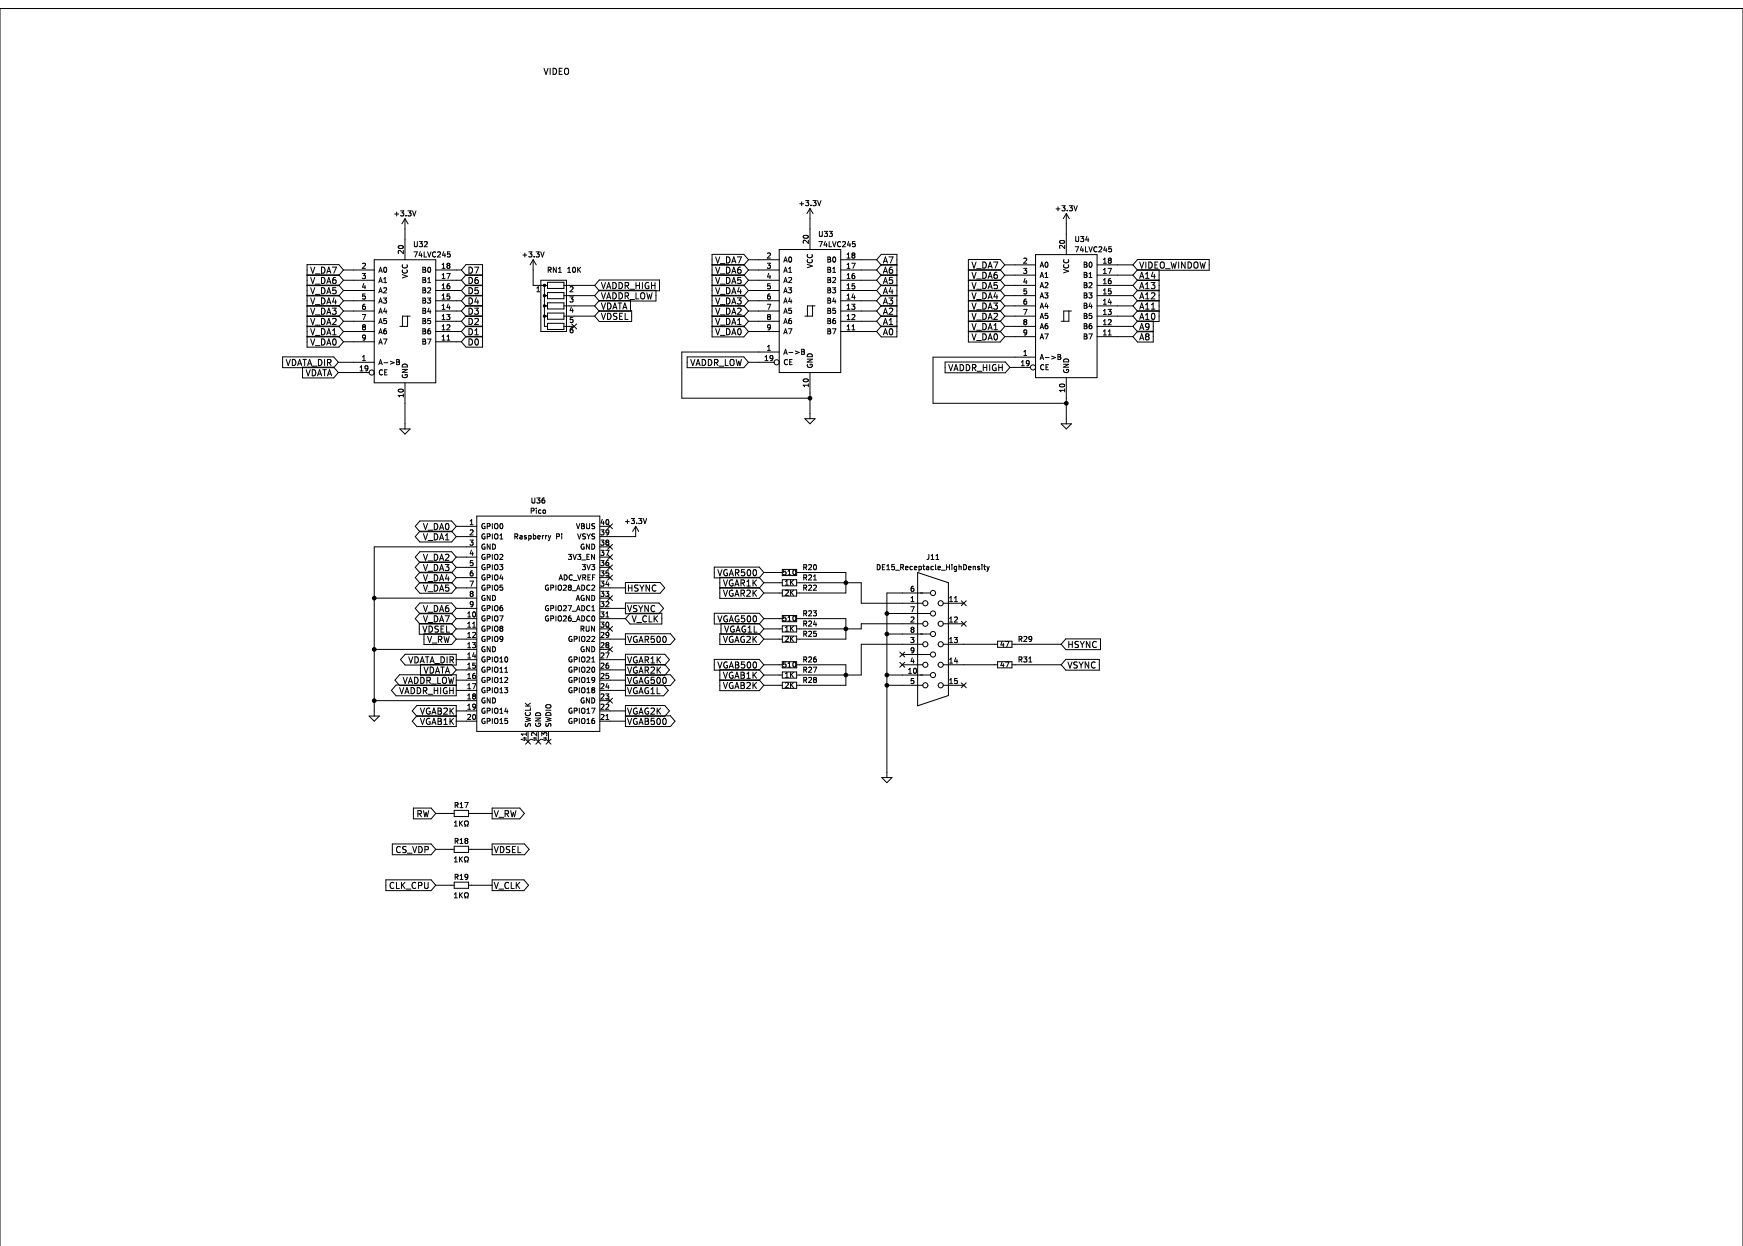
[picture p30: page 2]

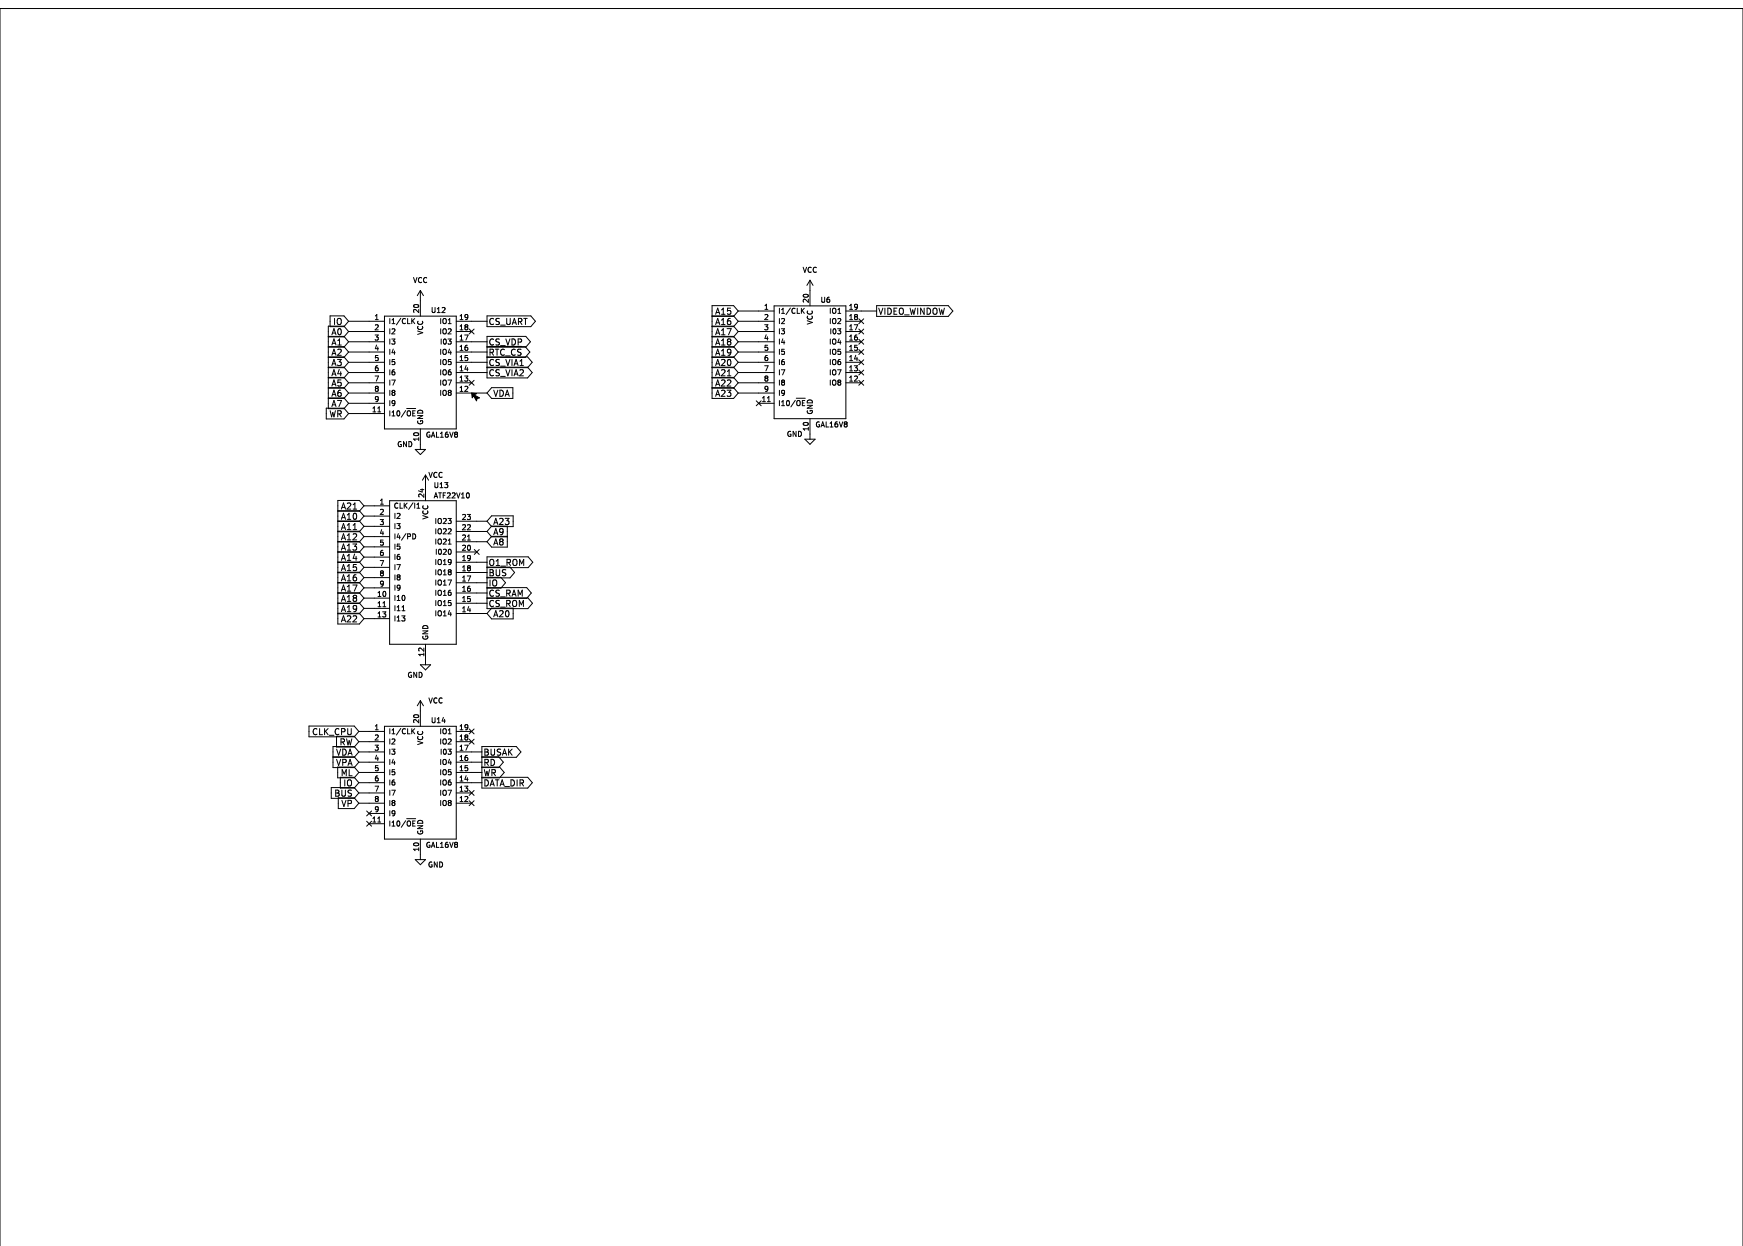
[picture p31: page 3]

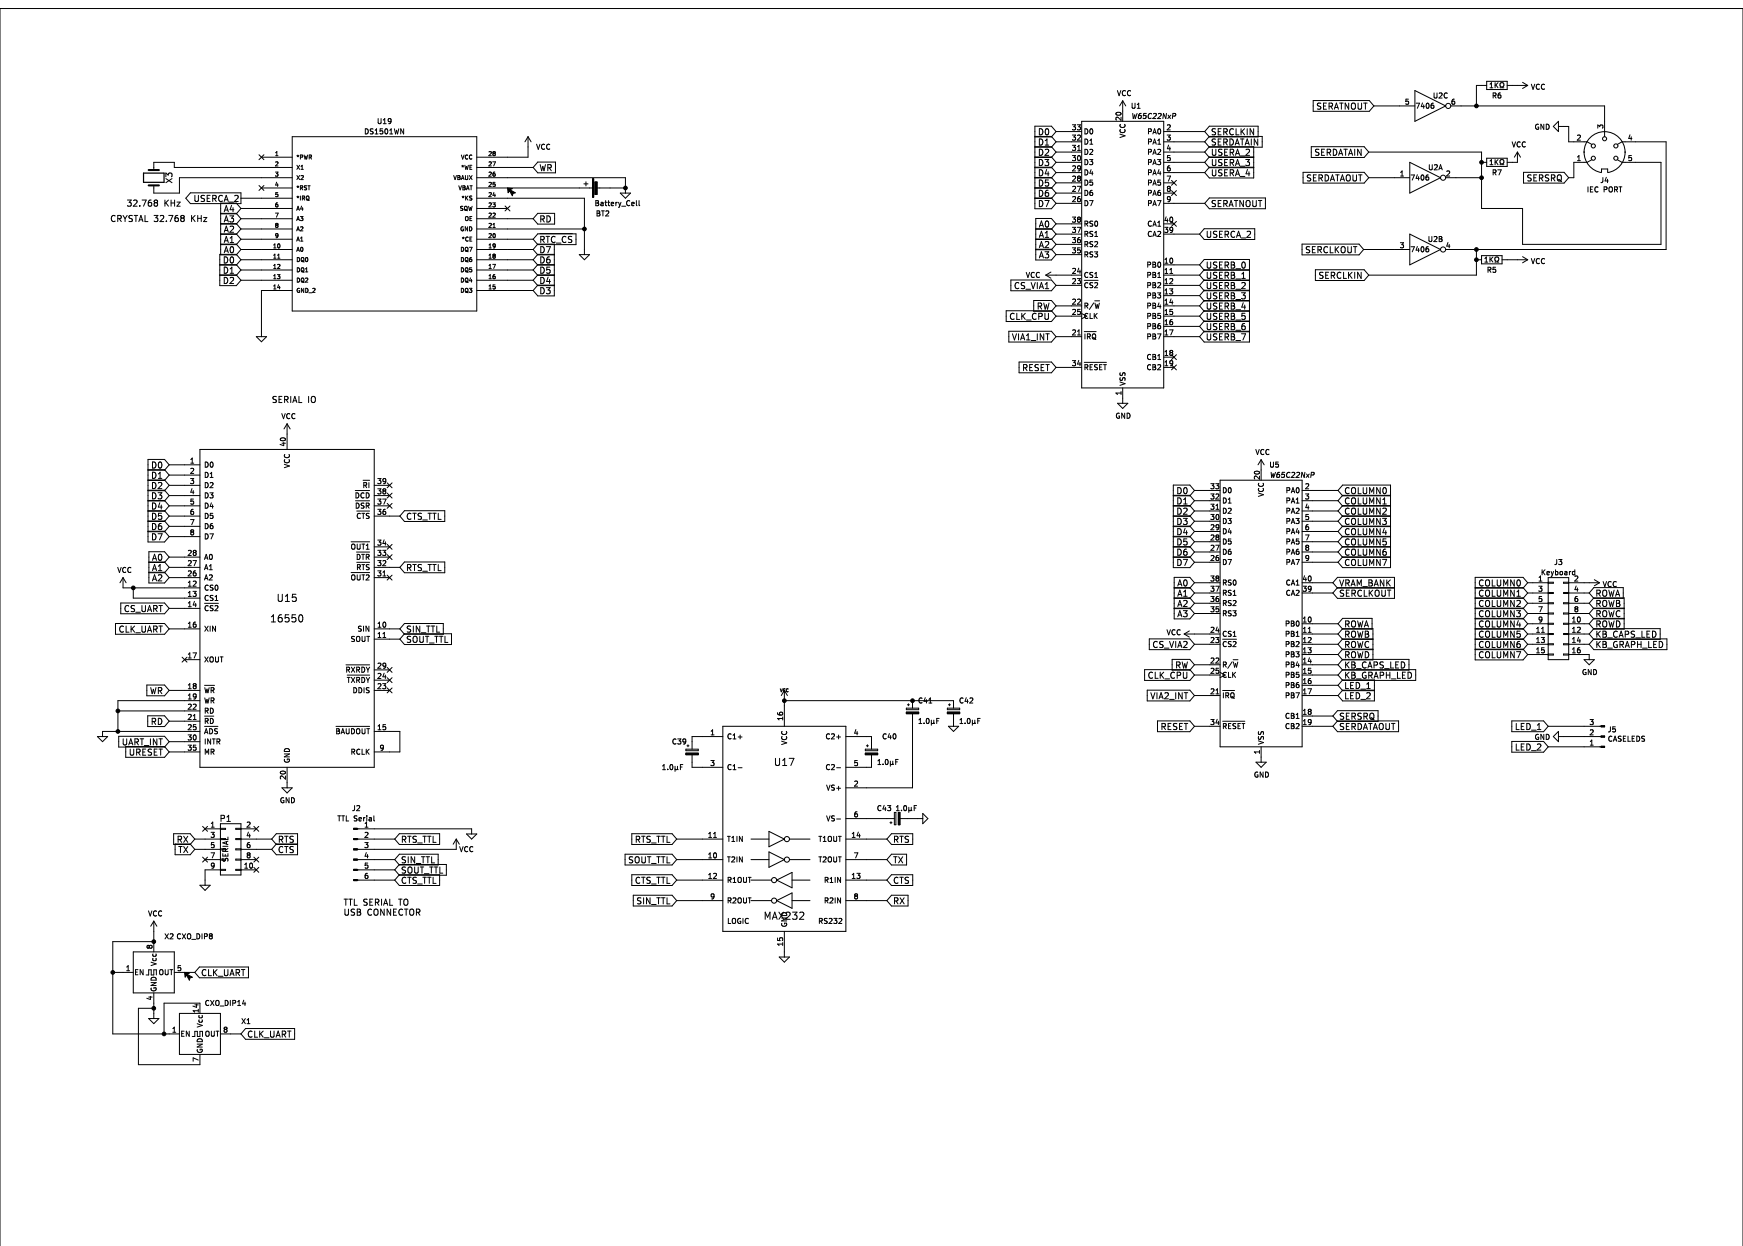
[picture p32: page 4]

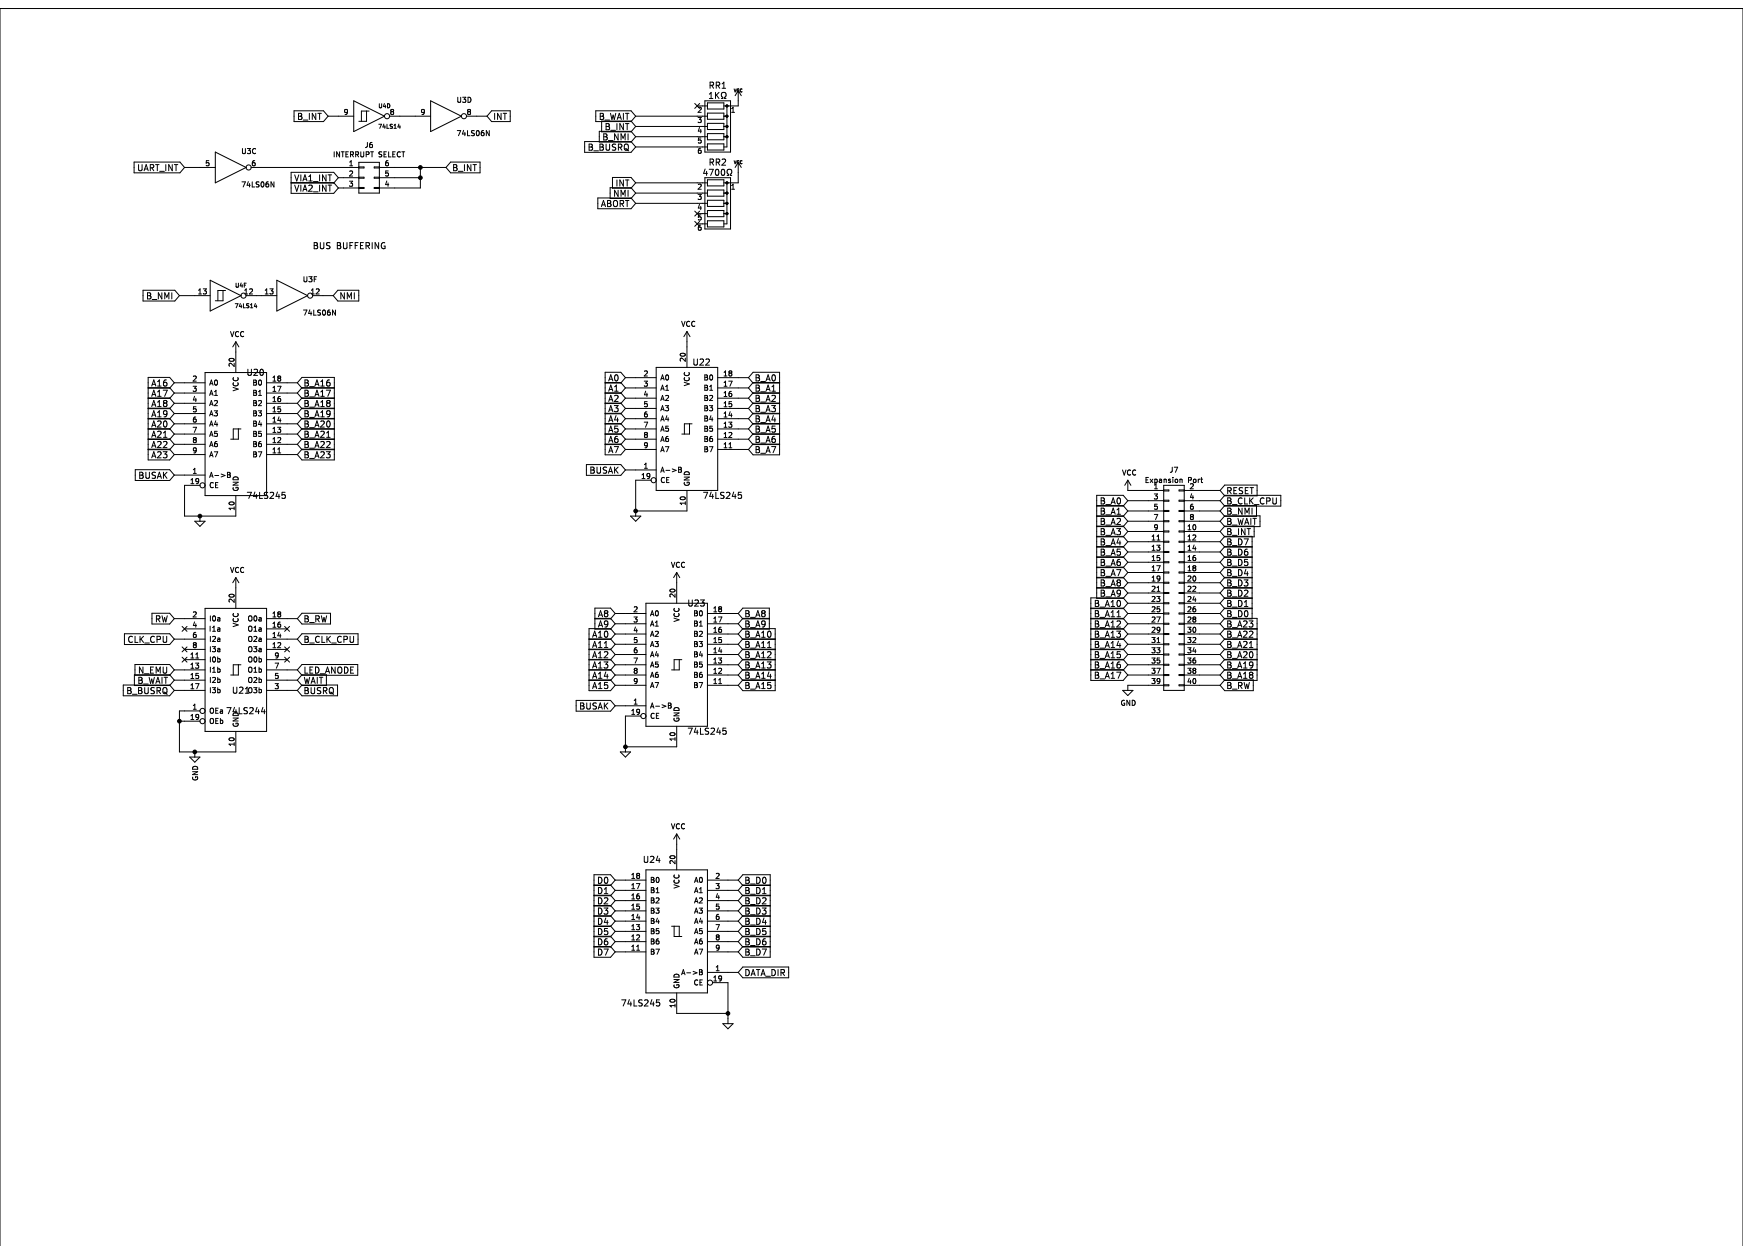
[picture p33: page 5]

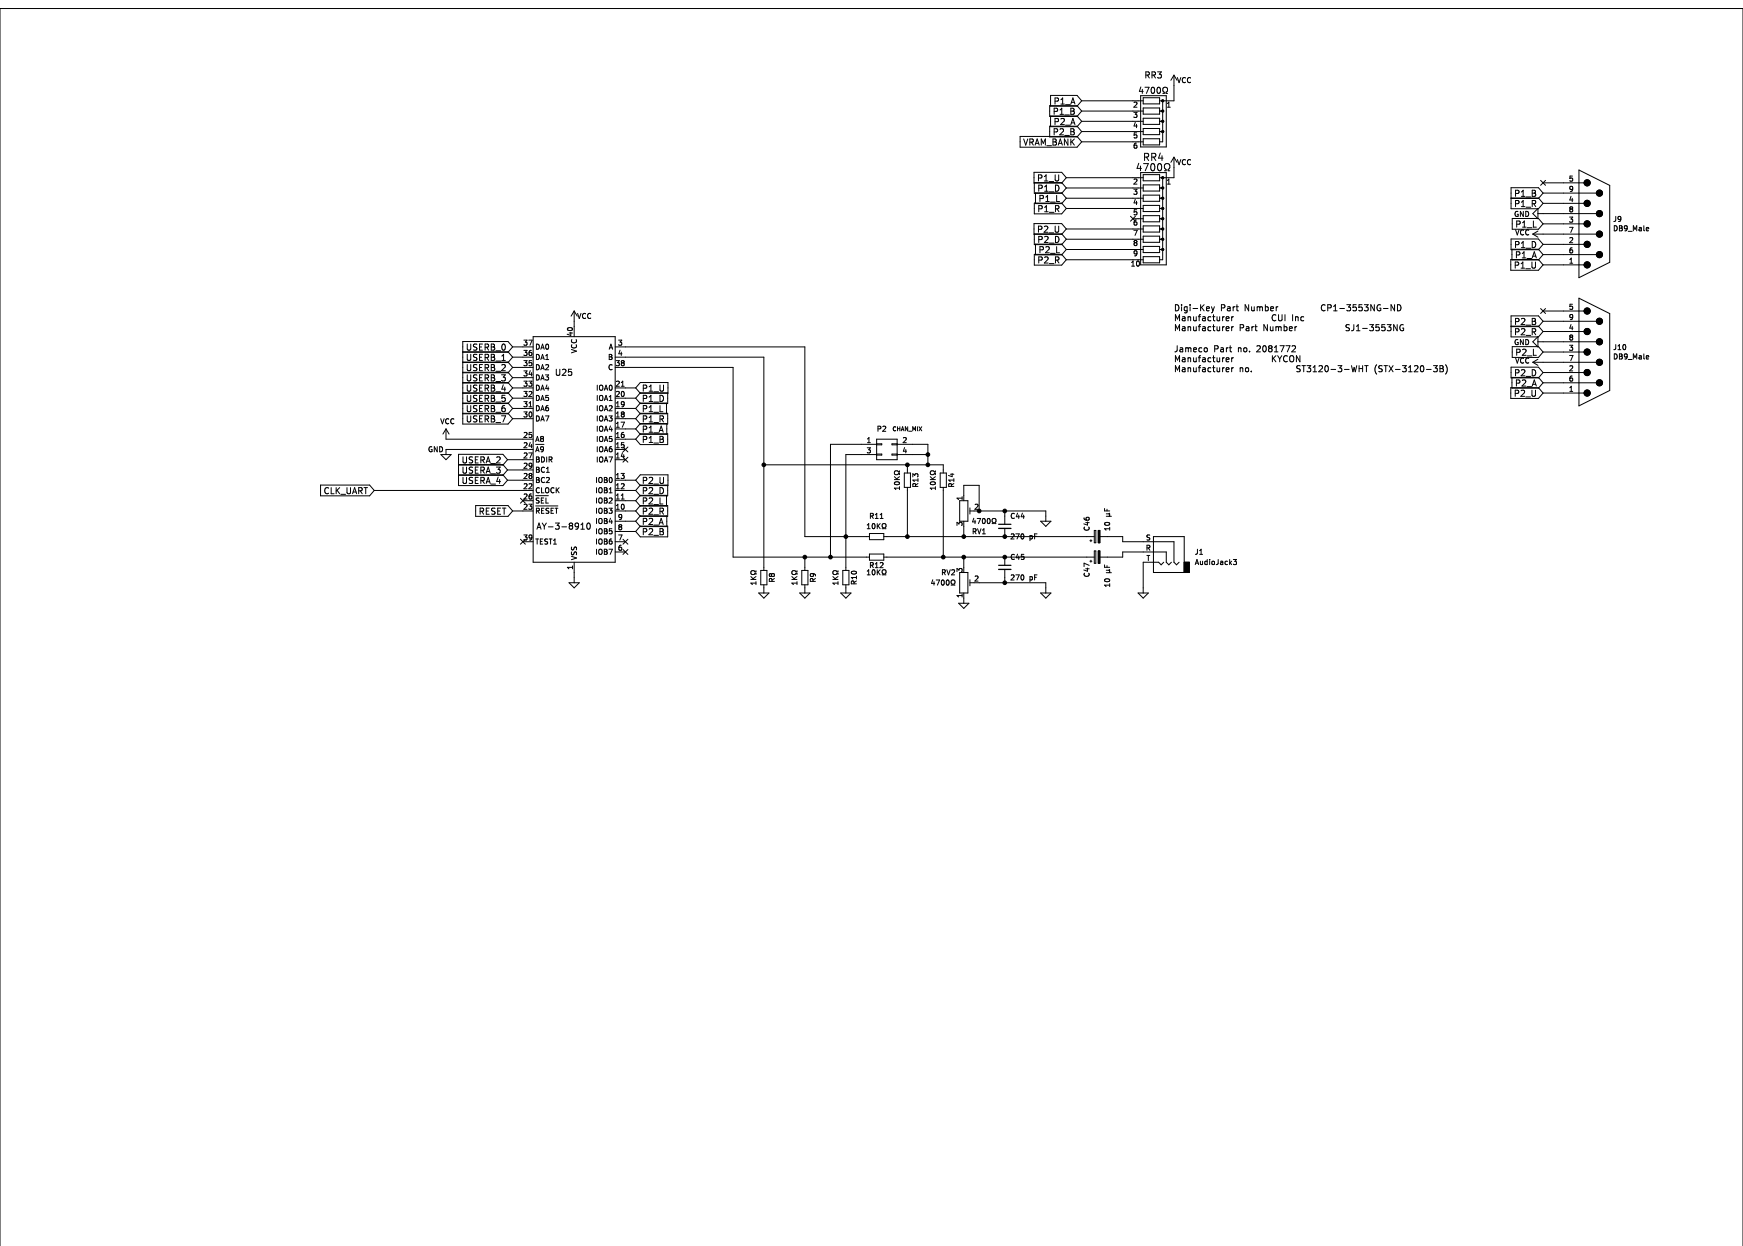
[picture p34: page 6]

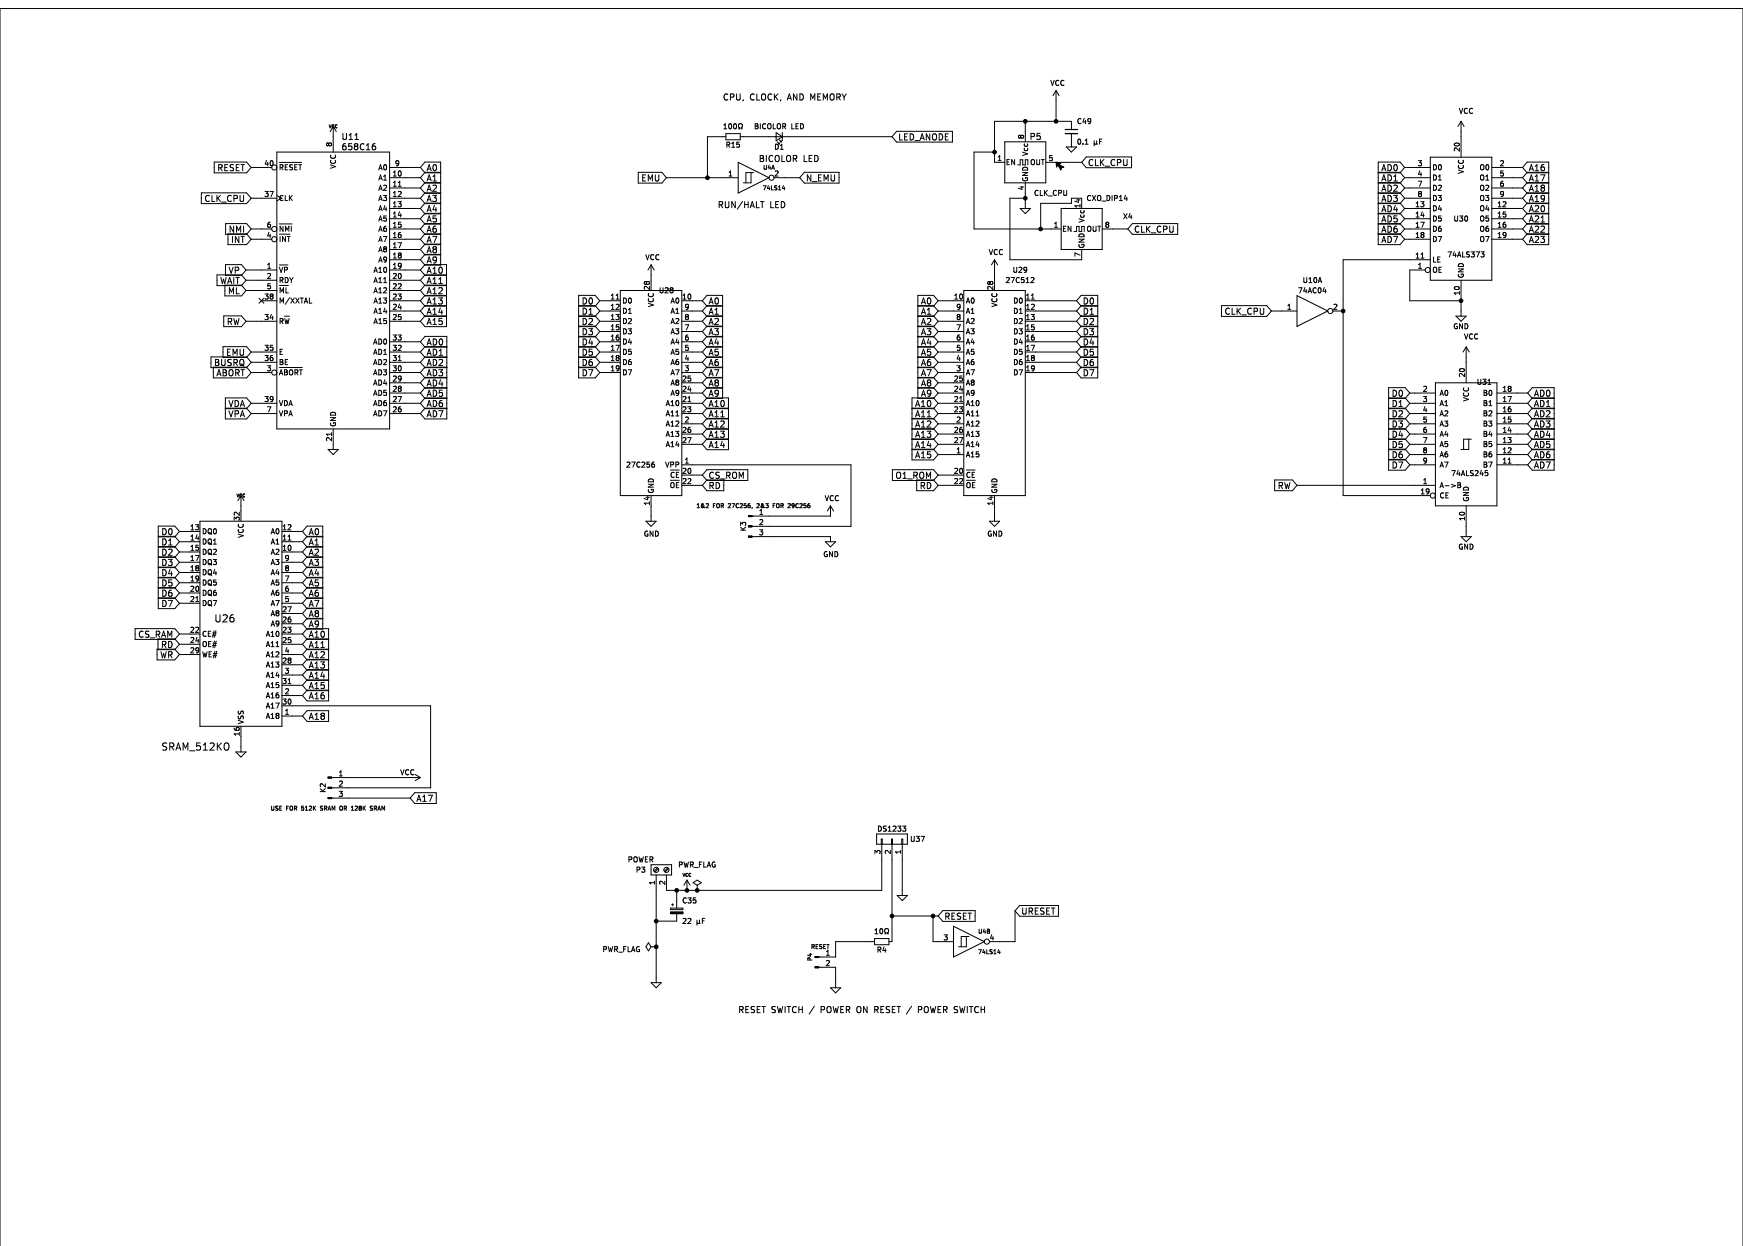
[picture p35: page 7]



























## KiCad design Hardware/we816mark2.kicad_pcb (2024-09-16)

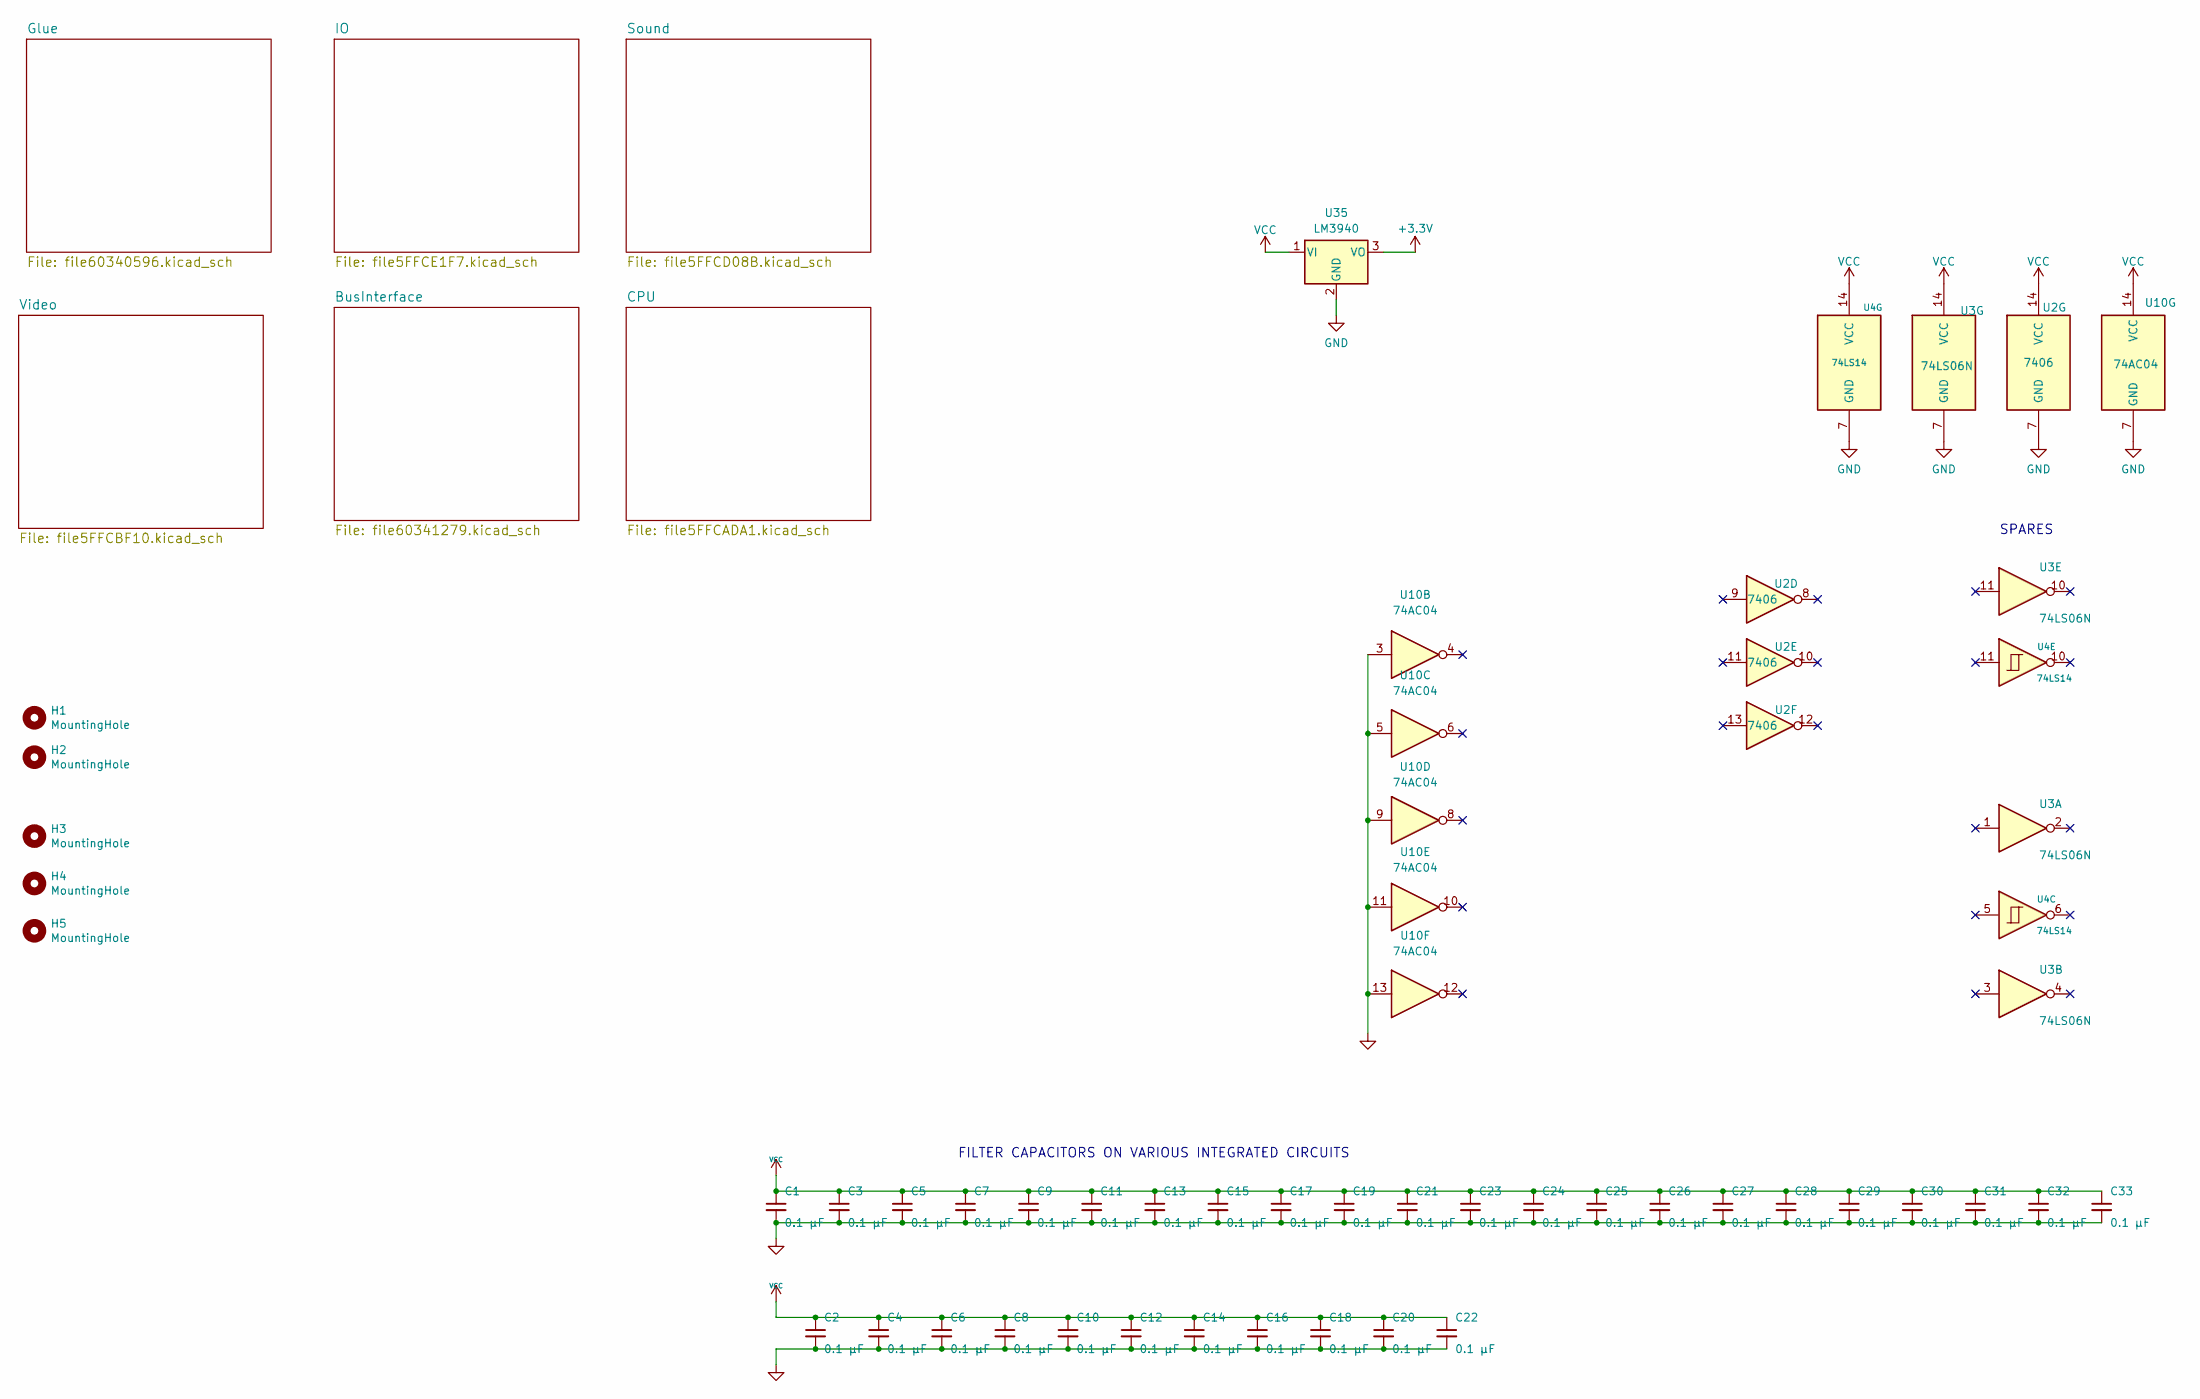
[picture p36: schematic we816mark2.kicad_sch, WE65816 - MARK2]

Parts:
C1, C2, C3, C4, C5, C6, C7, C8, C9, C10, C11, C12, C13, C14, C15, C16, C17, C18, C19, C20, C21, C22, C23, C24, C25, C26, C27, C28, C29, C30, C31, C32, C33: 0.1 µF; C_Rect_L7.0mm_W2.0mm_P5.00mm
H1, H2, H3, H4, H5: MountingHole; MountingHole_3.2mm_M3
U2: 7406; DIP-14_W7.62mm_Socket_LongPads
U3: 74LS06N; DIP-14_W7.62mm_Socket_LongPads
U4: 74LS14; DIP-14_W7.62mm_Socket_LongPads
U10: 74AC04; DIP-14_W7.62mm_Socket_LongPads
U35: LM3940; TO-220-3_Vertical

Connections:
+3.3V: U35.3 (VO); also elsewhere on the board
GND: C1.2, C2.2, C3.2, C4.2, C5.2, C6.2, C7.2, C8.2, C9.2, C10.2, C11.2, C12.2, C13.2, C14.2, C15.2, C16.2, C17.2, C18.2, C19.2, C20.2, C21.2, C22.2, C23.2, C24.2, C25.2, C26.2, C27.2, C28.2, C29.2, C30.2, C31.2, C32.2, C33.2, U2.7 (GND), U3.7 (GND), U4.7 (GND), U10.3, U10.5, U10.7 (GND), U10.9, U10.11, U10.13, U35.2 (GND); also elsewhere on the board
VCC: C1.1, C2.1, C3.1, C4.1, C5.1, C6.1, C7.1, C8.1, C9.1, C10.1, C11.1, C12.1, C13.1, C14.1, C15.1, C16.1, C17.1, C18.1, C19.1, C20.1, C21.1, C22.1, C23.1, C24.1, C25.1, C26.1, C27.1, C28.1, C29.1, C30.1, C31.1, C32.1, C33.1, U2.14 (VCC), U3.14 (VCC), U4.14 (VCC), U10.14 (VCC), U35.1 (VI); also elsewhere on the board

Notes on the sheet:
FILTER CAPACITORS ON VARIOUS INTEGRATED CIRCUITS
SPARES

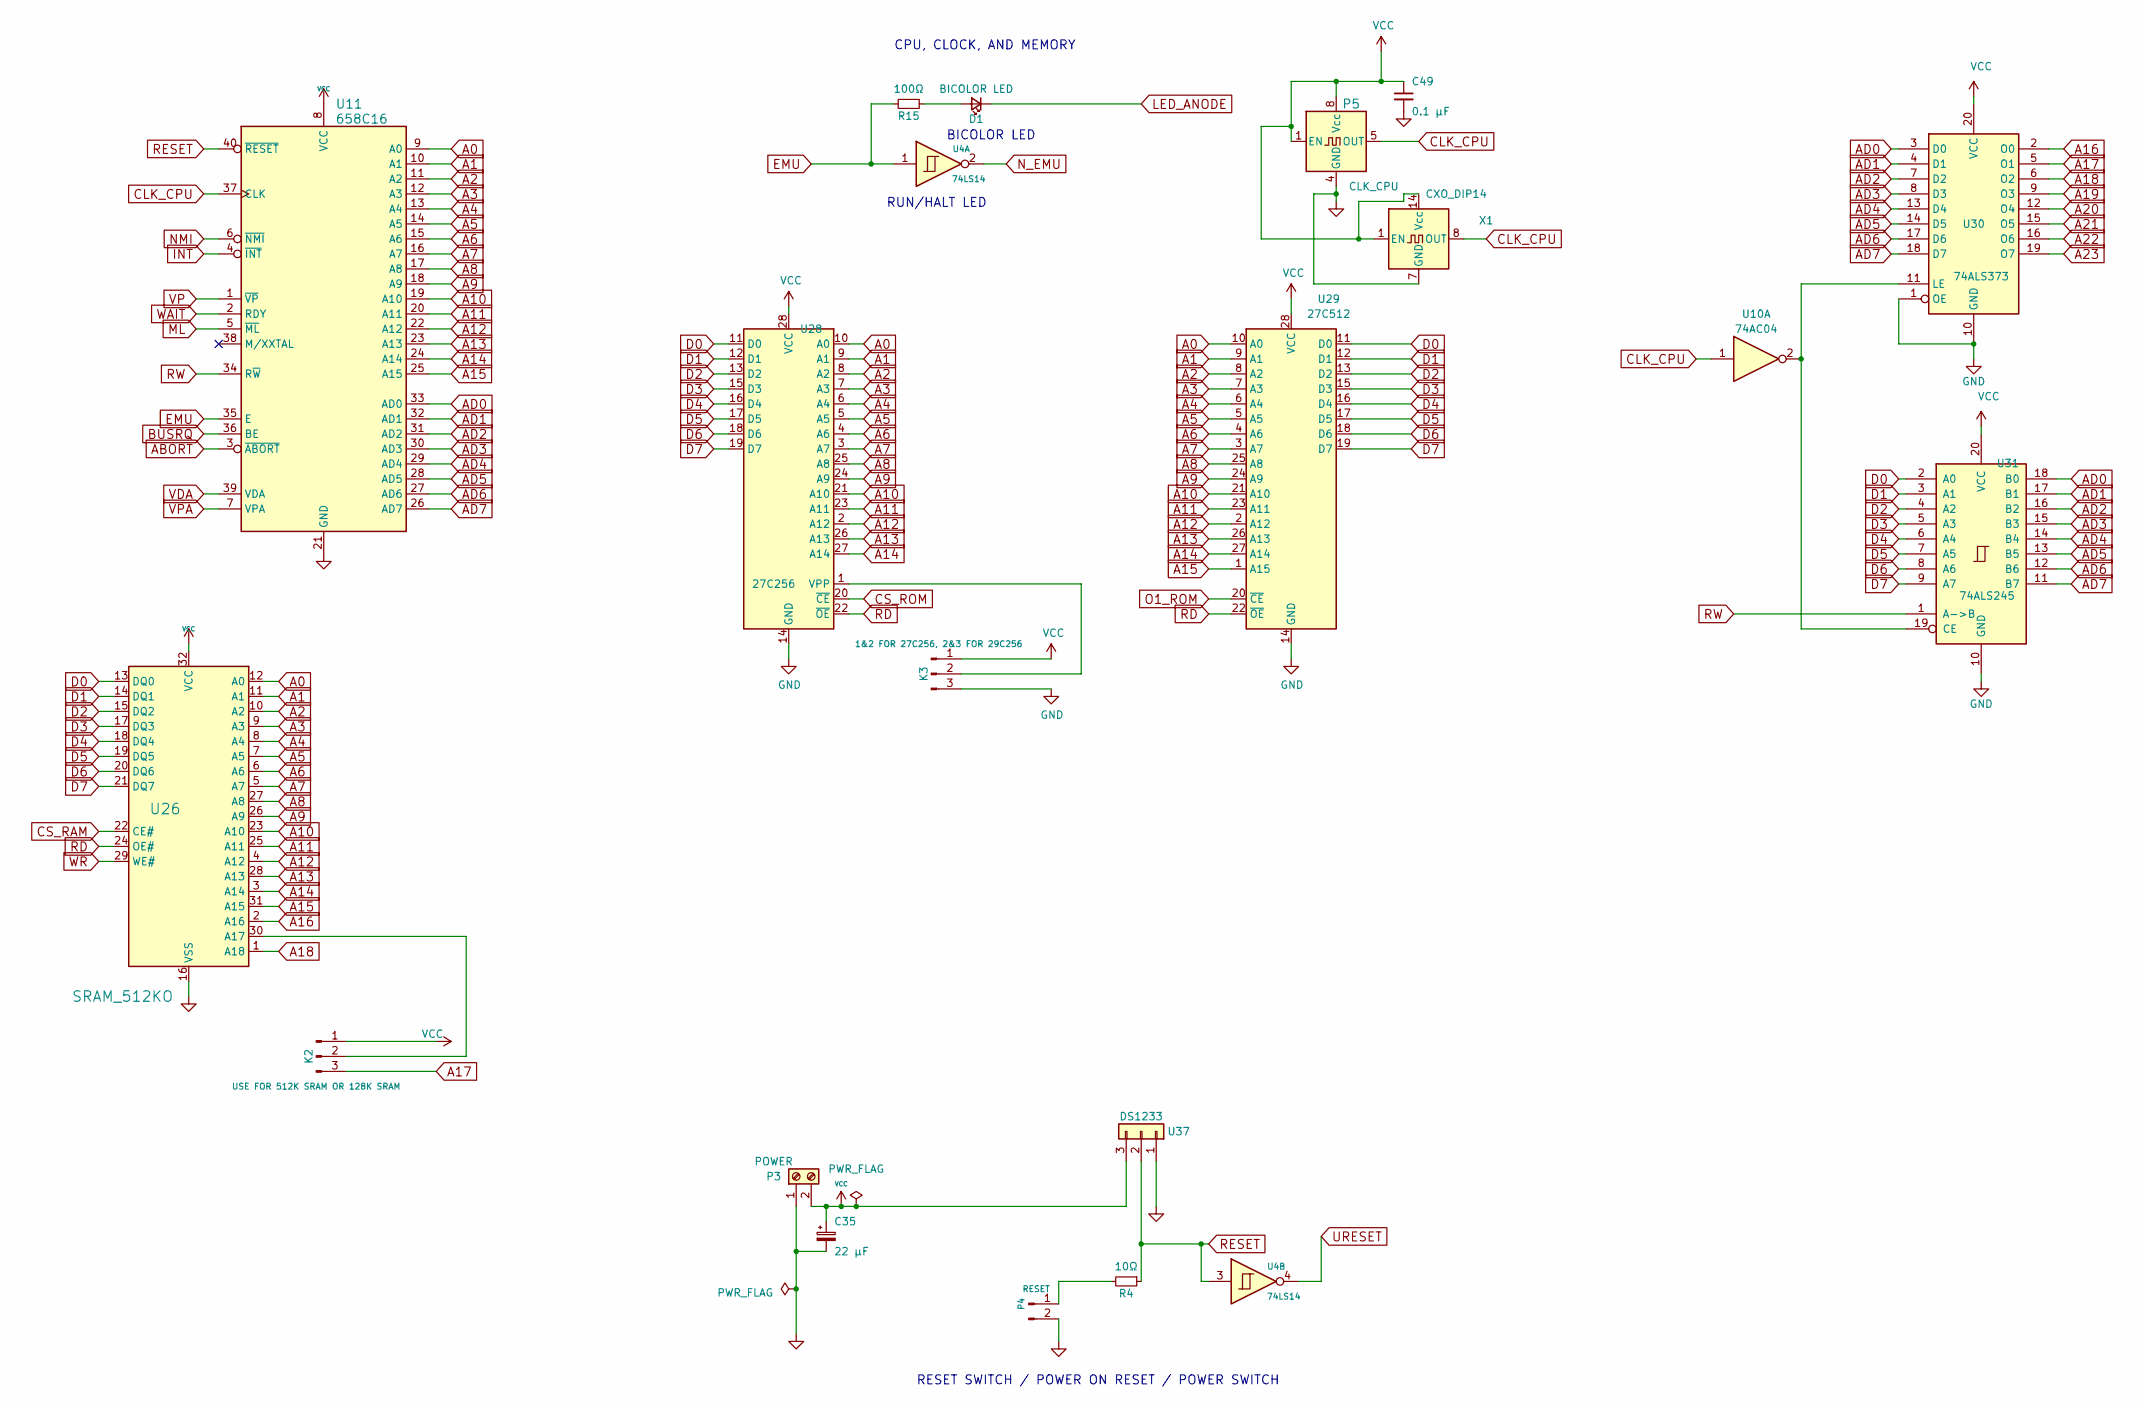
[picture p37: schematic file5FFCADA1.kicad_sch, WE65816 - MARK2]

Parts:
C35: 22 µF; CP_Radial_D4.0mm_P2.00mm
C49: 0.1 µF; C_Rect_L7.0mm_W2.0mm_P5.00mm
D1: BICOLOR LED; LED_D5.0mm
K2: USE FOR 512K SRAM OR 128K SRAM; PinHeader_1x03_P2.54mm_Vertical
K3: 1&2 FOR 27C256, 2&3 FOR 29C256; PinHeader_1x03_P2.54mm_Vertical
P3: POWER; TerminalBlock_RND_205-00001_1x02_P5.00mm_Horizontal
P4: RESET; PinHeader_1x02_P2.54mm_Vertical
P5: CLK_CPU; Oscillator_DIP-8
R4: 10Ω; R_Axial_DIN0204_L3.6mm_D1.6mm_P5.08mm_Horizontal
R15: 100Ω; R_Axial_DIN0204_L3.6mm_D1.6mm_P5.08mm_Horizontal
U4: 74LS14; DIP-14_W7.62mm_Socket_LongPads
U10: 74AC04; DIP-14_W7.62mm_Socket_LongPads
U11: 658C16; DIP-40_W15.24mm_Socket_LongPads
U26: SRAM_512KO; DIP-32_W15.24mm_Socket_LongPads
U28: 27C256; DIP-28_W15.24mm_Socket_LongPads
U29: 27C512; DIP-28_W15.24mm_Socket_LongPads
U30: 74ALS373; DIP-20_W7.62mm_Socket_LongPads
U31: 74ALS245; DIP-20_W7.62mm_Socket_LongPads
U37: DS1233; TO-92L_HandSolder
X1: CXO_DIP14; Oscillator_DIP-14

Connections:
A0: U11.9 (A0), U26.12 (A0), U28.10 (A0), U29.10 (A0); also elsewhere on the board
A1: U11.10 (A1), U26.11 (A1), U28.9 (A1), U29.9 (A1); also elsewhere on the board
A2: U11.11 (A2), U26.10 (A2), U28.8 (A2), U29.8 (A2); also elsewhere on the board
A3: U11.12 (A3), U26.9 (A3), U28.7 (A3), U29.7 (A3); also elsewhere on the board
A4: U11.13 (A4), U26.8 (A4), U28.6 (A4), U29.6 (A4); also elsewhere on the board
A5: U11.14 (A5), U26.7 (A5), U28.5 (A5), U29.5 (A5); also elsewhere on the board
A6: U11.15 (A6), U26.6 (A6), U28.4 (A6), U29.4 (A6); also elsewhere on the board
A7: U11.16 (A7), U26.5 (A7), U28.3 (A7), U29.3 (A7); also elsewhere on the board
A8: U11.17 (A8), U26.27 (A8), U28.25 (A8), U29.25 (A8); also elsewhere on the board
A9: U11.18 (A9), U26.26 (A9), U28.24 (A9), U29.24 (A9); also elsewhere on the board
A10: U11.19 (A10), U26.23 (A10), U28.21 (A10), U29.21 (A10); also elsewhere on the board
A11: U11.20 (A11), U26.25 (A11), U28.23 (A11), U29.23 (A11); also elsewhere on the board
A12: U11.22 (A12), U26.4 (A12), U28.2 (A12), U29.2 (A12); also elsewhere on the board
A13: U11.23 (A13), U26.28 (A13), U28.26 (A13), U29.26 (A13); also elsewhere on the board
A14: U11.24 (A14), U26.3 (A14), U28.27 (A14), U29.27 (A14); also elsewhere on the board
A15: U11.25 (A15), U26.31 (A15), U29.1 (A15); also elsewhere on the board
A16: U26.2 (A16), U30.2 (O0); also elsewhere on the board
A17: K2.3, U30.5 (O1); also elsewhere on the board
A18: U26.1 (A18), U30.6 (O2); also elsewhere on the board
A19: U30.9 (O3); also elsewhere on the board
A20: U30.12 (O4); also elsewhere on the board
A21: U30.15 (O5); also elsewhere on the board
A22: U30.16 (O6); also elsewhere on the board
A23: U30.19 (O7); also elsewhere on the board
ABORT: U11.3 (~ABORT); also elsewhere on the board
AD0: U11.33 (AD0), U30.3 (D0), U31.18 (B0)
AD1: U11.32 (AD1), U30.4 (D1), U31.17 (B1)
AD2: U11.31 (AD2), U30.7 (D2), U31.16 (B2)
AD3: U11.30 (AD3), U30.8 (D3), U31.15 (B3)
AD4: U11.29 (AD4), U30.13 (D4), U31.14 (B4)
AD5: U11.28 (AD5), U30.14 (D5), U31.13 (B5)
AD6: U11.27 (AD6), U30.17 (D6), U31.12 (B6)
AD7: U11.26 (AD7), U30.18 (D7), U31.11 (B7)
BUSRQ: U11.36 (BE); also elsewhere on the board
CS_RAM: U26.22 (CE#); also elsewhere on the board
CS_ROM: U28.20 (~CE); also elsewhere on the board
D0: U26.13 (DQ0), U28.11 (D0), U29.11 (D0), U31.2 (A0); also elsewhere on the board
D1: U26.14 (DQ1), U28.12 (D1), U29.12 (D1), U31.3 (A1); also elsewhere on the board
D2: U26.15 (DQ2), U28.13 (D2), U29.13 (D2), U31.4 (A2); also elsewhere on the board
D3: U26.17 (DQ3), U28.15 (D3), U29.15 (D3), U31.5 (A3); also elsewhere on the board
D4: U26.18 (DQ4), U28.16 (D4), U29.16 (D4), U31.6 (A4); also elsewhere on the board
D5: U26.19 (DQ5), U28.17 (D5), U29.17 (D5), U31.7 (A5); also elsewhere on the board
D6: U26.20 (DQ6), U28.18 (D6), U29.18 (D6), U31.8 (A6); also elsewhere on the board
D7: U26.21 (DQ7), U28.19 (D7), U29.19 (D7), U31.9 (A7); also elsewhere on the board
EMU: R15.2, U4.1, U11.35 (E)
GND: C35.2, C49.2, K3.3, P3.1, P4.2, P5.4 (GND), U11.21 (GND), U26.16 (VSS), U28.14 (GND), U29.14 (GND), U30.1 (OE), U30.10 (GND), U31.10 (GND), U37.1, X1.7 (GND); also elsewhere on the board
INT: U11.4 (~INT); also elsewhere on the board
LED_ANODE: D1.1 (K); also elsewhere on the board
ML: U11.5 (~ML); also elsewhere on the board
NMI: U11.6 (~NMI); also elsewhere on the board
N_EMU: U4.2; also elsewhere on the board
unnamed: D1.2 (A), R15.1
unnamed: K2.2, U26.30 (A17)
unnamed: K3.2, U28.1 (VPP)
unnamed: P4.1, R4.2
unnamed: U10.2, U30.11 (LE), U31.19 (CE)
O1_ROM: U29.20 (~CE); also elsewhere on the board
RD: U26.24 (OE#), U28.22 (~OE), U29.22 (~OE); also elsewhere on the board
RESET: R4.1, U4.3, U11.40 (~RESET), U37.2; also elsewhere on the board
RW: U11.34 (R~W), U31.1 (A->B); also elsewhere on the board
URESET: U4.4; also elsewhere on the board
VCC: C35.1, C49.1, K2.1, K3.1, P3.2, P5.1 (EN), P5.8 (Vcc), U11.8 (VCC), U26.32 (VCC), U28.28 (VCC), U29.28 (VCC), U30.20 (VCC), U31.20 (VCC), U37.3, X1.1 (EN), X1.14 (Vcc); also elsewhere on the board
VDA: U11.39 (VDA); also elsewhere on the board
VP: U11.1 (~VP); also elsewhere on the board
VPA: U11.7 (VPA); also elsewhere on the board
WAIT: U11.2 (RDY); also elsewhere on the board
WR: U26.29 (WE#); also elsewhere on the board

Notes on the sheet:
RESET SWITCH / POWER ON RESET / POWER SWITCH
RUN/HALT LED
CPU, CLOCK, AND MEMORY
BICOLOR LED

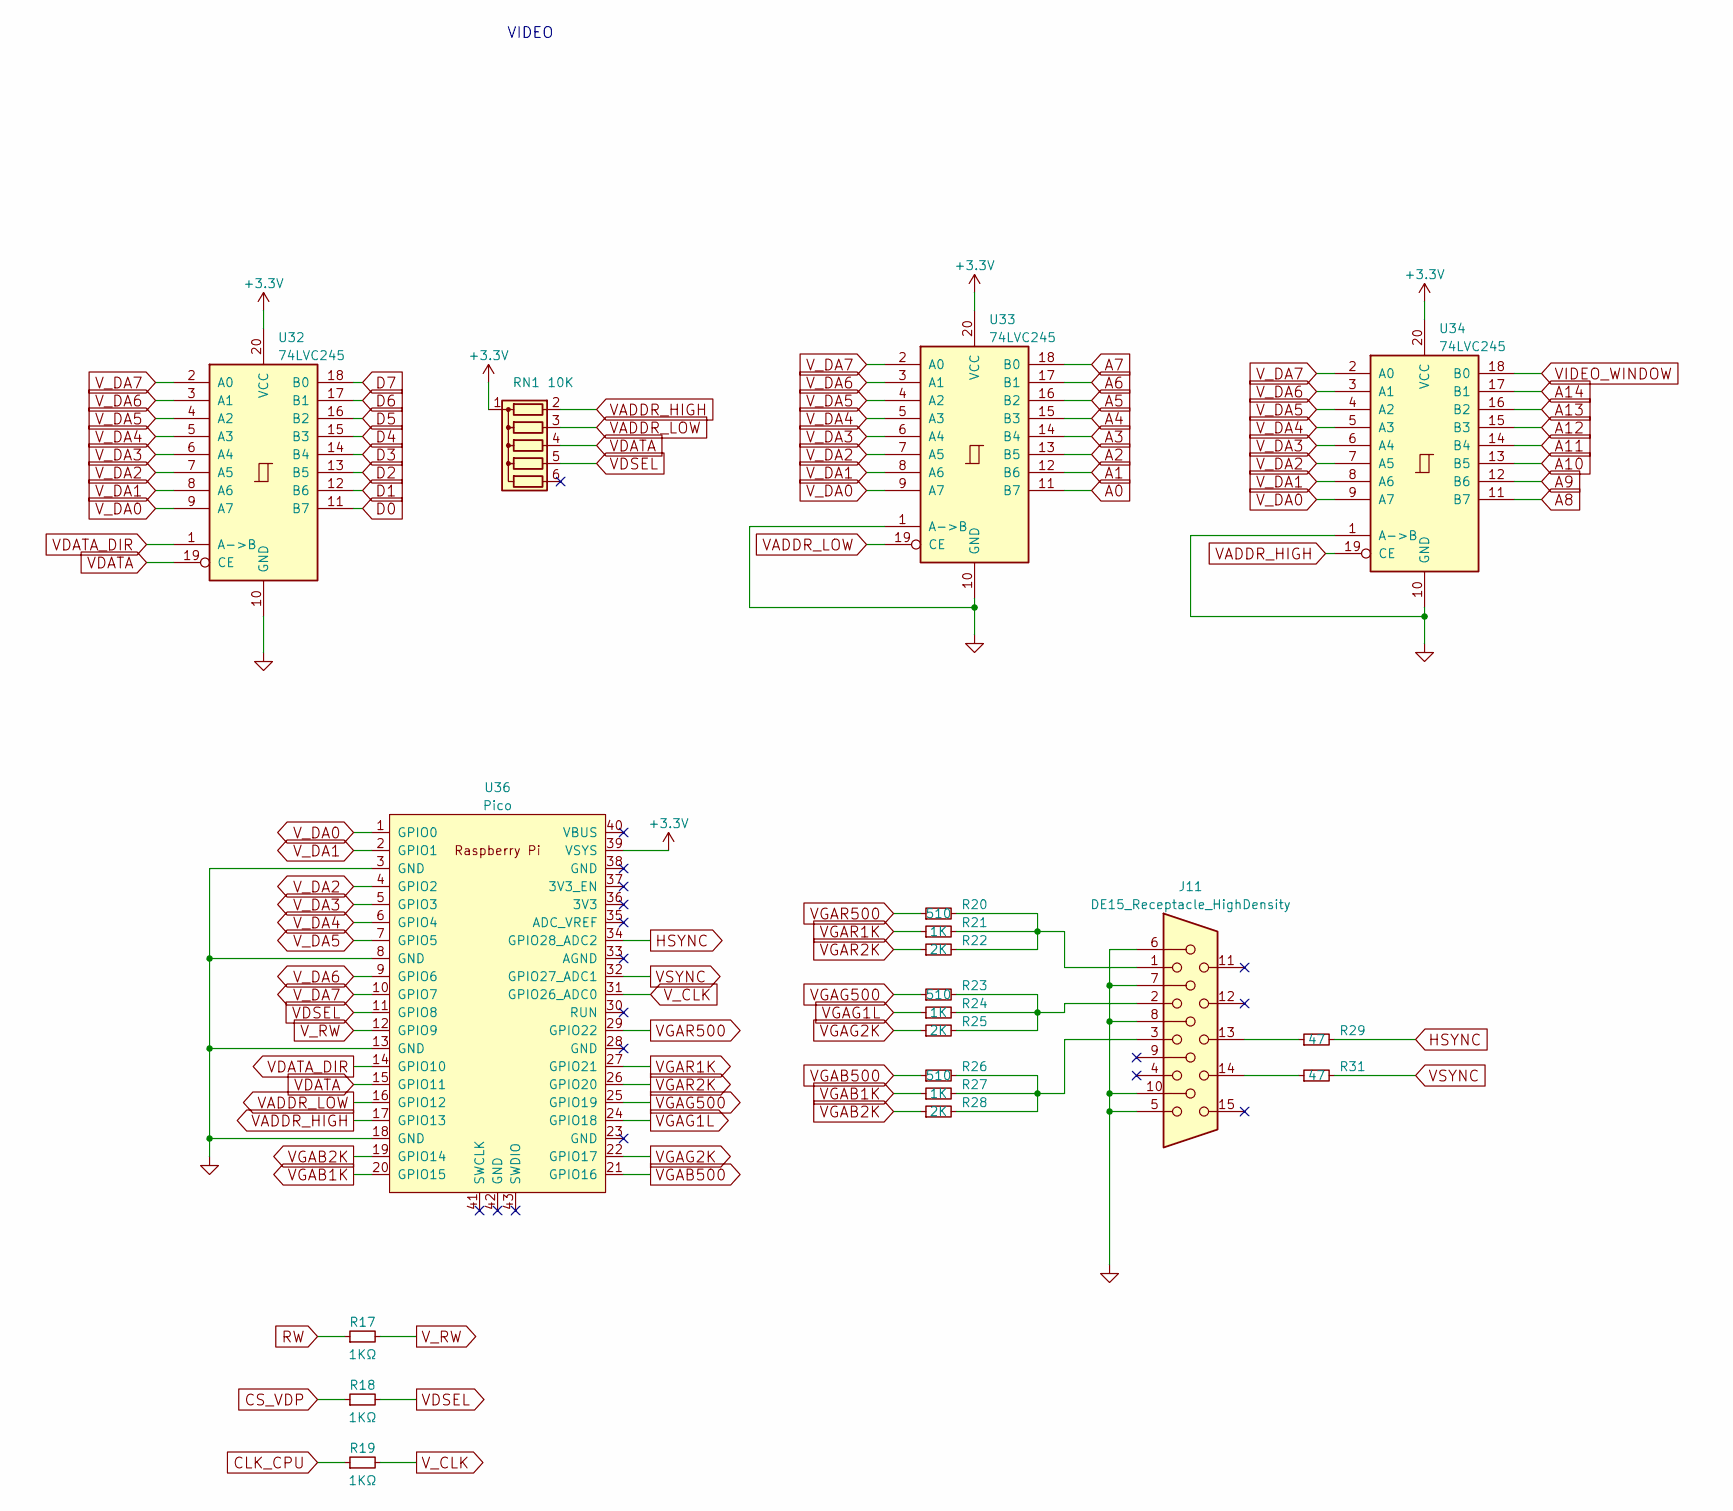
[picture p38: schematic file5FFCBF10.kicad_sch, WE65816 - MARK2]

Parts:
J11: DE15_Receptacle_HighDensity; DSUB-15-HD_Female_Horizontal_P2.29x1.98mm_EdgePinOffset3.03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
R17, R18, R19: 1KΩ; R_Axial_DIN0204_L3.6mm_D1.6mm_P5.08mm_Horizontal
R20, R23, R26: 510; R_Axial_DIN0204_L3.6mm_D1.6mm_P5.08mm_Horizontal
R21, R24, R27: 1K; R_Axial_DIN0204_L3.6mm_D1.6mm_P5.08mm_Horizontal
R22, R25, R28: 2K; R_Axial_DIN0204_L3.6mm_D1.6mm_P5.08mm_Horizontal
R29, R31: 47; R_Axial_DIN0204_L3.6mm_D1.6mm_P5.08mm_Horizontal
RN1: 10K; R_Array_SIP6
U32, U33, U34: 74LVC245; DIP-20_W7.62mm_Socket_LongPads
U36: Pico; RPi_Pico_SMD_TH

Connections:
+3.3V: RN1.1 (common), U32.20 (VCC), U33.20 (VCC), U34.20 (VCC), U36.39 (VSYS); also elsewhere on the board
A0: U33.11 (B7); also elsewhere on the board
A1: U33.12 (B6); also elsewhere on the board
A2: U33.13 (B5); also elsewhere on the board
A3: U33.14 (B4); also elsewhere on the board
A4: U33.15 (B3); also elsewhere on the board
A5: U33.16 (B2); also elsewhere on the board
A6: U33.17 (B1); also elsewhere on the board
A7: U33.18 (B0); also elsewhere on the board
A8: U34.11 (B7); also elsewhere on the board
A9: U34.12 (B6); also elsewhere on the board
A10: U34.13 (B5); also elsewhere on the board
A11: U34.14 (B4); also elsewhere on the board
A12: U34.15 (B3); also elsewhere on the board
A13: U34.16 (B2); also elsewhere on the board
A14: U34.17 (B1); also elsewhere on the board
CS_VDP: R18.1; also elsewhere on the board
D0: U32.11 (B7); also elsewhere on the board
D1: U32.12 (B6); also elsewhere on the board
D2: U32.13 (B5); also elsewhere on the board
D3: U32.14 (B4); also elsewhere on the board
D4: U32.15 (B3); also elsewhere on the board
D5: U32.16 (B2); also elsewhere on the board
D6: U32.17 (B1); also elsewhere on the board
D7: U32.18 (B0); also elsewhere on the board
GND: J11.5, J11.6, J11.7, J11.8, J11.10, U32.10 (GND), U33.1 (A->B), U33.10 (GND), U34.1 (A->B), U34.10 (GND), U36.3 (GND), U36.8 (GND), U36.13 (GND), U36.18 (GND); also elsewhere on the board
HSYNC: R29.2, U36.34 (GPIO28_ADC2)
unnamed: J11.1, R20.2, R21.2, R22.2
unnamed: J11.2, R23.2, R24.2, R25.2
unnamed: J11.3, R26.2, R27.2, R28.2
unnamed: J11.13, R29.1
unnamed: J11.14, R31.1
RW: R17.1; also elsewhere on the board
VADDR_HIGH: RN1.2 (R1), U34.19 (CE), U36.17 (GPIO13)
VADDR_LOW: RN1.3 (R2), U33.19 (CE), U36.16 (GPIO12)
VDATA: RN1.4 (R3), U32.19 (CE), U36.15 (GPIO11)
VDATA_DIR: U32.1 (A->B), U36.14 (GPIO10)
VDSEL: R18.2, RN1.5 (R4), U36.11 (GPIO8)
VGAB1K: R27.1, U36.20 (GPIO15)
VGAB2K: R28.1, U36.19 (GPIO14)
VGAB500: R26.1, U36.21 (GPIO16)
VGAG1L: R24.1, U36.24 (GPIO18)
VGAG2K: R25.1, U36.22 (GPIO17)
VGAG500: R23.1, U36.25 (GPIO19)
VGAR1K: R21.1, U36.27 (GPIO21)
VGAR2K: R22.1, U36.26 (GPIO20)
VGAR500: R20.1, U36.29 (GPIO22)
VIDEO_WINDOW: U34.18 (B0); also elsewhere on the board
VSYNC: R31.2, U36.32 (GPIO27_ADC1)
V_CLK: R19.2, U36.31 (GPIO26_ADC0)
V_DA0: U32.9 (A7), U33.9 (A7), U34.9 (A7), U36.1 (GPIO0)
V_DA1: U32.8 (A6), U33.8 (A6), U34.8 (A6), U36.2 (GPIO1)
V_DA2: U32.7 (A5), U33.7 (A5), U34.7 (A5), U36.4 (GPIO2)
V_DA3: U32.6 (A4), U33.6 (A4), U34.6 (A4), U36.5 (GPIO3)
V_DA4: U32.5 (A3), U33.5 (A3), U34.5 (A3), U36.6 (GPIO4)
V_DA5: U32.4 (A2), U33.4 (A2), U34.4 (A2), U36.7 (GPIO5)
V_DA6: U32.3 (A1), U33.3 (A1), U34.3 (A1), U36.9 (GPIO6)
V_DA7: U32.2 (A0), U33.2 (A0), U34.2 (A0), U36.10 (GPIO7)
V_RW: R17.2, U36.12 (GPIO9)

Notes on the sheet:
VIDEO

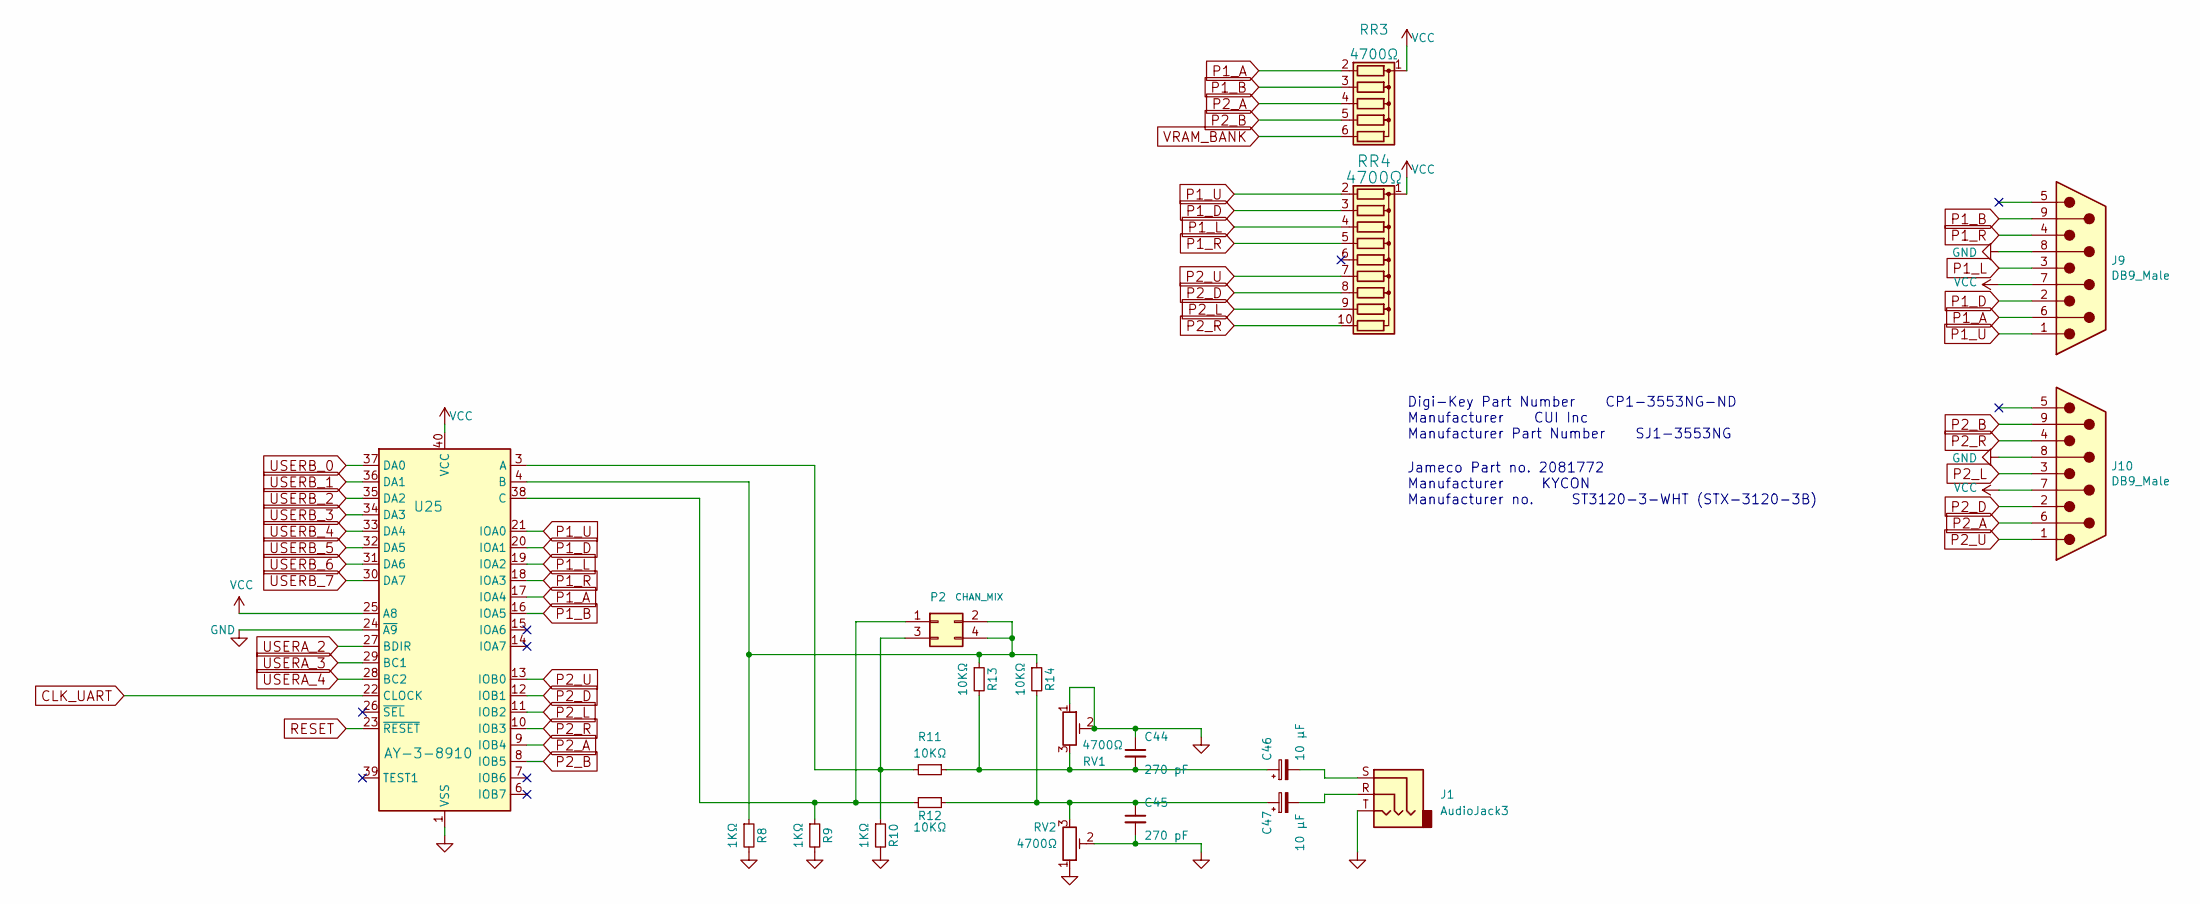
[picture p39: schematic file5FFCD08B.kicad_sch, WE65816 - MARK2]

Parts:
C44, C45: 270 pF; C_Rect_L7.0mm_W2.0mm_P5.00mm
C46, C47: 10 µF; CP_Radial_D4.0mm_P2.00mm
J1: AudioJack3; Jack_3.5mm_CUI_SJ1-3533NG_Horizontal_CircularHoles
J9, J10: DB9_Male; DSUB-9_Male_Horizontal_P2.77x2.84mm_EdgePinOffset9.90mm_Hou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
P2: CHAN_MIX; PinHeader_2x02_P2.54mm_Vertical
R8, R9, R10: 1KΩ; R_Axial_DIN0204_L3.6mm_D1.6mm_P5.08mm_Horizontal
R11, R12, R13, R14: 10KΩ; R_Axial_DIN0204_L3.6mm_D1.6mm_P5.08mm_Horizontal
RR3: 4700Ω; R_Array_SIP6
RR4: 4700Ω; R_Array_SIP10
RV1, RV2: 4700Ω; Potentiometer_ACP_CA9-V10_Vertical
U25: AY-3-8910; DIP-40_W15.24mm_Socket_LongPads

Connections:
GND: C44.1, C45.2, J1.T, J9.8, J10.8, R8.2, R9.2, R10.2, RV1.1, RV1.2, RV2.1, RV2.2, U25.1 (VSS), U25.24 (~A9); also elsewhere on the board
unnamed: C44.2, C46.1, R11.1, R13.2, RV1.3
unnamed: C45.1, C47.1, R12.1, R14.2, RV2.3
unnamed: C46.2, J1.S
unnamed: C47.2, J1.R
unnamed: P2.1, R9.1, R12.2, U25.38 (C)
unnamed: P2.2, P2.4, R8.1, R13.1, R14.1, U25.4 (B)
unnamed: P2.3, R10.1, R11.2, U25.3 (A)
P1_A: J9.6, RR3.2 (R1), U25.17 (IOA4)
P1_B: J9.9, RR3.3 (R2), U25.16 (IOA5)
P1_D: J9.2, RR4.3 (R2), U25.20 (IOA1)
P1_L: J9.3, RR4.4 (R3), U25.19 (IOA2)
P1_R: J9.4, RR4.5 (R4), U25.18 (IOA3)
P1_U: J9.1, RR4.2 (R1), U25.21 (IOA0)
P2_A: J10.6, RR3.4 (R3), U25.9 (IOB4)
P2_B: J10.9, RR3.5 (R4), U25.8 (IOB5)
P2_D: J10.2, RR4.8 (R7), U25.12 (IOB1)
P2_L: J10.3, RR4.9 (R8), U25.11 (IOB2)
P2_R: J10.4, RR4.10 (R9), U25.10 (IOB3)
P2_U: J10.1, RR4.7 (R6), U25.13 (IOB0)
RESET: U25.23 (~RESET); also elsewhere on the board
USERA_2: U25.27 (BDIR); also elsewhere on the board
USERA_3: U25.29 (BC1); also elsewhere on the board
USERA_4: U25.28 (BC2); also elsewhere on the board
USERB_0: U25.37 (DA0); also elsewhere on the board
USERB_1: U25.36 (DA1); also elsewhere on the board
USERB_2: U25.35 (DA2); also elsewhere on the board
USERB_3: U25.34 (DA3); also elsewhere on the board
USERB_4: U25.33 (DA4); also elsewhere on the board
USERB_5: U25.32 (DA5); also elsewhere on the board
USERB_6: U25.31 (DA6); also elsewhere on the board
USERB_7: U25.30 (DA7); also elsewhere on the board
VCC: J9.7, J10.7, RR3.1 (common), RR4.1 (common), U25.25 (A8), U25.40 (VCC); also elsewhere on the board
VRAM_BANK: RR3.6 (R5); also elsewhere on the board

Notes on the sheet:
Digi-Key Part Number CP1-3553NG-ND Manufacturer CUI Inc Manufacturer Part Number SJ1-3553NG
Jameco Part no. 2081772 Manufacturer KYCON Manufacturer no. ST3120-3-WHT (STX-3120-3B)

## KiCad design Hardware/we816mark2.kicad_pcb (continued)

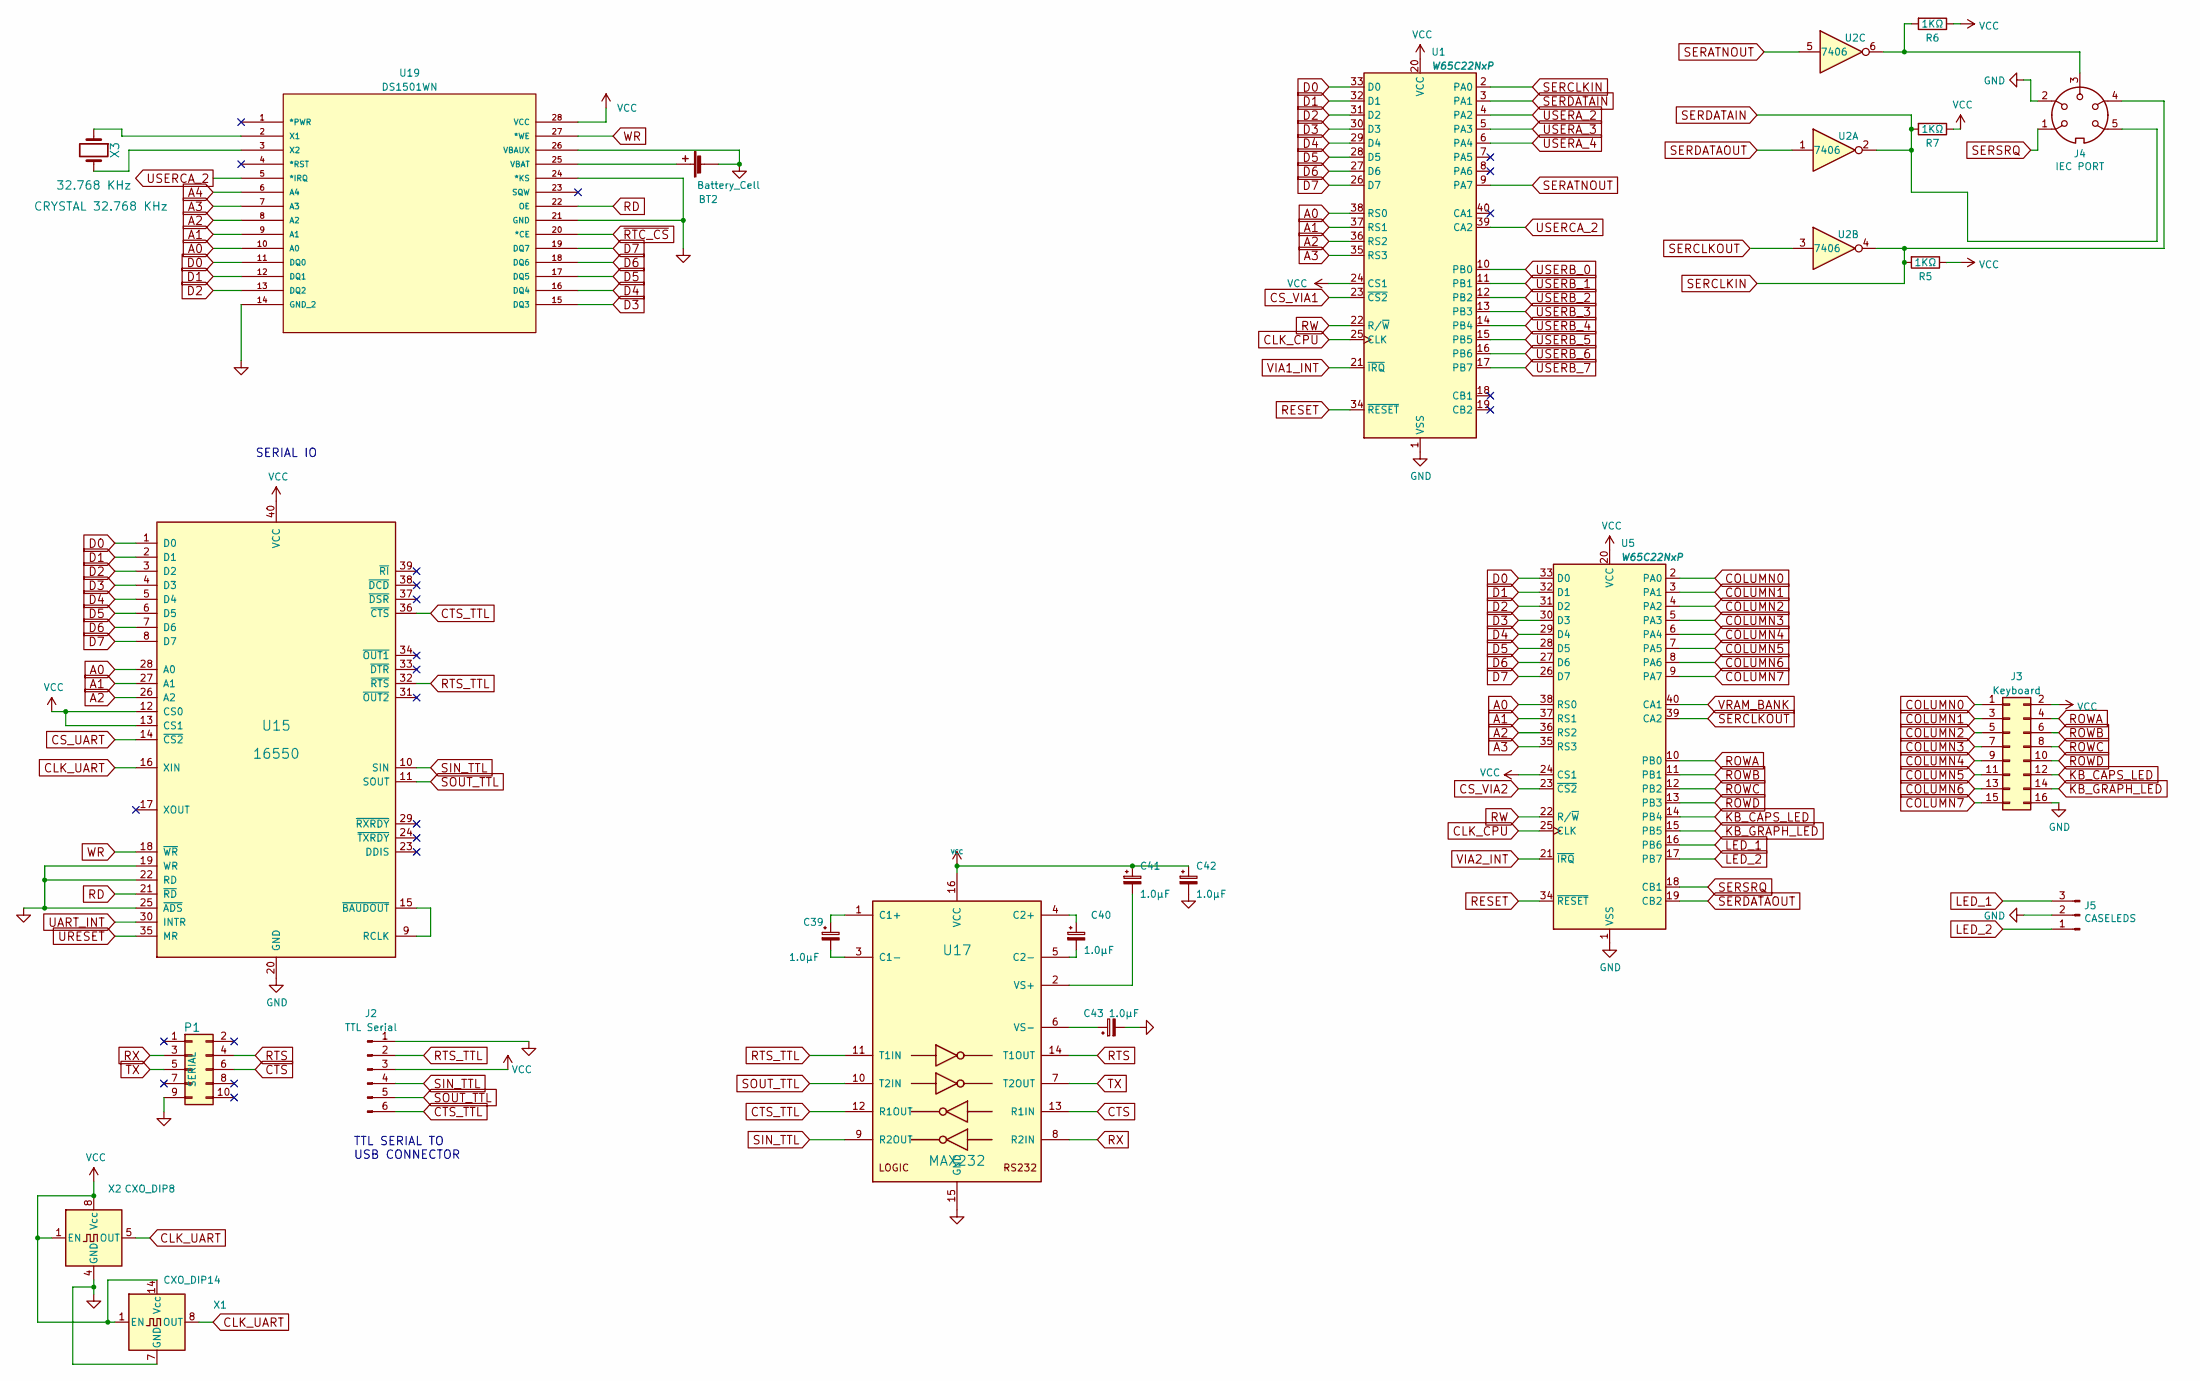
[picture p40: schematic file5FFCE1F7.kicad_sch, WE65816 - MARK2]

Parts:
BT2: Battery_Cell; Battery_Holder_Coin_2032_BS-7_FIXED
C39, C40, C41, C42, C43: 1.0µF; CP_Radial_D4.0mm_P2.00mm
J2: TTL Serial; PinHeader_1x06_P2.54mm_Vertical
J3: Keyboard; PinHeader_2x08_P2.54mm_Vertical
J4: IEC PORT; din6
J5: CASELEDS; PinHeader_1x03_P2.54mm_Vertical
P1: SERIAL; PinHeader_2x05_P2.54mm_Vertical
R5, R6, R7: 1KΩ; R_Axial_DIN0204_L3.6mm_D1.6mm_P5.08mm_Horizontal
U1, U5: W65C22NxP; DIP-40_W15.24mm_Socket_LongPads
U2: 7406; DIP-14_W7.62mm_Socket_LongPads
U15: 16550; DIP-40_W15.24mm_Socket_LongPads
U17: MAX232; DIP-16_W7.62mm_Socket_LongPads
U19: DS1501WN; DIP-28_W15.24mm_Socket_LongPads; MANUFACTURER_PART_NUMBER DS1501WN+
X1: CXO_DIP14; Oscillator_DIP-14
X2: CXO_DIP8; Oscillator_DIP-8
X3: CRYSTAL 32.768 KHz; Crystal_Round_D1.5mm_Vertical

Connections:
A0: U1.38 (RS0), U5.38 (RS0), U15.28 (A0), U19.10 (A0); also elsewhere on the board
A1: U1.37 (RS1), U5.37 (RS1), U15.27 (A1), U19.9 (A1); also elsewhere on the board
A2: U1.36 (RS2), U5.36 (RS2), U15.26 (A2), U19.8 (A2); also elsewhere on the board
A3: U1.35 (RS3), U5.35 (RS3), U19.7 (A3); also elsewhere on the board
A4: U19.6 (A4); also elsewhere on the board
COLUMN0: J3.1, U5.2 (PA0)
COLUMN1: J3.3, U5.3 (PA1)
COLUMN2: J3.5, U5.4 (PA2)
COLUMN3: J3.7, U5.5 (PA3)
COLUMN4: J3.9, U5.6 (PA4)
COLUMN5: J3.11, U5.7 (PA5)
COLUMN6: J3.13, U5.8 (PA6)
COLUMN7: J3.15, U5.9 (PA7)
CS_UART: U15.14 (~CS2); also elsewhere on the board
CS_VIA1: U1.23 (~CS2); also elsewhere on the board
CS_VIA2: U5.23 (~CS2); also elsewhere on the board
CTS: P1.6, U17.13 (R1IN)
CTS_TTL: J2.6, U15.36 (~CTS), U17.12 (R1OUT)
D0: U1.33 (D0), U5.33 (D0), U15.1 (D0), U19.11 (DQ0); also elsewhere on the board
D1: U1.32 (D1), U5.32 (D1), U15.2 (D1), U19.12 (DQ1); also elsewhere on the board
D2: U1.31 (D2), U5.31 (D2), U15.3 (D2), U19.13 (DQ2); also elsewhere on the board
D3: U1.30 (D3), U5.30 (D3), U15.4 (D3), U19.15 (DQ3); also elsewhere on the board
D4: U1.29 (D4), U5.29 (D4), U15.5 (D4), U19.16 (DQ4); also elsewhere on the board
D5: U1.28 (D5), U5.28 (D5), U15.6 (D5), U19.17 (DQ5); also elsewhere on the board
D6: U1.27 (D6), U5.27 (D6), U15.7 (D6), U19.18 (DQ6); also elsewhere on the board
D7: U1.26 (D7), U5.26 (D7), U15.8 (D7), U19.19 (DQ7); also elsewhere on the board
GND: BT2.2 (-), C42.2, C43.2, J2.1, J3.16, J4.2, J5.2, P1.9, U1.1 (VSS), U5.1 (VSS), U15.19 (WR), U15.20 (GND), U15.22 (RD), U15.25 (~ADS), U17.15 (GND), U19.14 (GND_2), U19.21 (GND), U19.24 (*KS), U19.26 (VBAUX), X1.7 (GND), X2.4 (GND); also elsewhere on the board
KB_CAPS_LED: J3.12, U5.14 (PB4)
KB_GRAPH_LED: J3.14, U5.15 (PB5)
LED_1: J5.3, U5.16 (PB6)
LED_2: J5.1, U5.17 (PB7)
unnamed: BT2.1 (+), U19.25 (VBAT)
unnamed: J4.3, R6.2, U2.6
unnamed: U15.9 (RCLK), U15.15 (~BAUDOUT)
unnamed: C39.1, U17.1 (C1+)
unnamed: C39.2, U17.3 (C1-)
unnamed: C40.1, U17.4 (C2+)
unnamed: C40.2, U17.5 (C2-)
unnamed: C41.2, U17.2 (VS+)
unnamed: C43.1, U17.6 (VS-)
unnamed: U19.2 (X1), X3.1
unnamed: U19.3 (X2), X3.2
RD: U15.21 (~RD), U19.22 (OE); also elsewhere on the board
RESET: U1.34 (~RESET), U5.34 (~RESET); also elsewhere on the board
ROWA: J3.4, U5.10 (PB0)
ROWB: J3.6, U5.11 (PB1)
ROWC: J3.8, U5.12 (PB2)
ROWD: J3.10, U5.13 (PB3)
RTS: P1.4, U17.14 (T1OUT)
RTS_TTL: J2.2, U15.32 (~RTS), U17.11 (T1IN)
RW: U1.22 (R/~W), U5.22 (R/~W); also elsewhere on the board
RX: P1.3, U17.8 (R2IN)
SERATNOUT: U1.9 (PA7), U2.5
SERCLKIN: J4.4, R5.2, U1.2 (PA0), U2.4
SERCLKOUT: U2.3, U5.39 (CA2)
SERDATAIN: J4.5, R7.2, U1.3 (PA1), U2.2
SERDATAOUT: U2.1, U5.19 (CB2)
SERSRQ: J4.1, U5.18 (CB1)
SIN_TTL: J2.4, U15.10 (SIN), U17.9 (R2OUT)
SOUT_TTL: J2.5, U15.11 (SOUT), U17.10 (T2IN)
TX: P1.5, U17.7 (T2OUT)
UART_INT: U15.30 (INTR); also elsewhere on the board
URESET: U15.35 (MR); also elsewhere on the board
USERA_2: U1.4 (PA2); also elsewhere on the board
USERA_3: U1.5 (PA3); also elsewhere on the board
USERA_4: U1.6 (PA4); also elsewhere on the board
USERB_0: U1.10 (PB0); also elsewhere on the board
USERB_1: U1.11 (PB1); also elsewhere on the board
USERB_2: U1.12 (PB2); also elsewhere on the board
USERB_3: U1.13 (PB3); also elsewhere on the board
USERB_4: U1.14 (PB4); also elsewhere on the board
USERB_5: U1.15 (PB5); also elsewhere on the board
USERB_6: U1.16 (PB6); also elsewhere on the board
USERB_7: U1.17 (PB7); also elsewhere on the board
USERCA_2: U1.39 (CA2), U19.5 (*IRQ)
VCC: C41.1, C42.1, J2.3, J3.2, R5.1, R6.1, R7.1, U1.20 (VCC), U1.24 (CS1), U5.20 (VCC), U5.24 (CS1), U15.12 (CS0), U15.13 (CS1), U15.40 (VCC), U17.16 (VCC), U19.28 (VCC), X1.1 (EN), X1.14 (Vcc), X2.1 (EN), X2.8 (Vcc); also elsewhere on the board
VIA1_INT: U1.21 (~IRQ); also elsewhere on the board
VIA2_INT: U5.21 (~IRQ); also elsewhere on the board
VRAM_BANK: U5.40 (CA1); also elsewhere on the board
WR: U15.18 (~WR), U19.27 (*WE); also elsewhere on the board
~RTC_CS: U19.20 (*CE); also elsewhere on the board

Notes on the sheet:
TTL SERIAL TO USB CONNECTOR
SERIAL IO

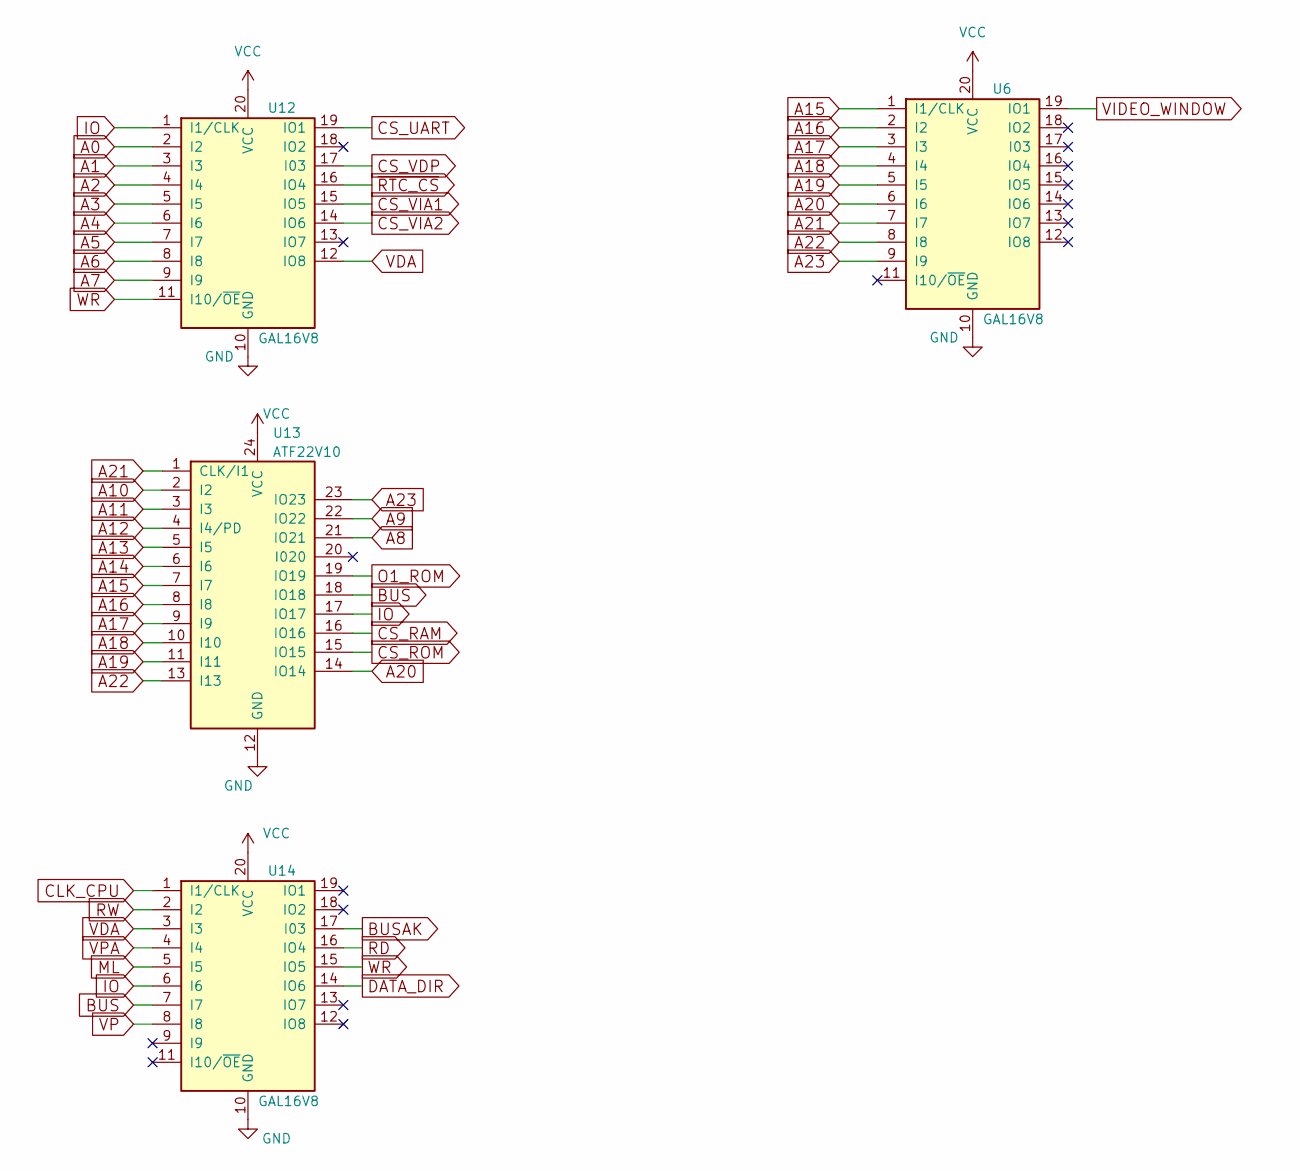
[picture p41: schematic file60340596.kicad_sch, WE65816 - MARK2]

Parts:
U6, U12, U14: GAL16V8; DIP-20_W7.62mm_Socket_LongPads
U13: ATF22V10; DIP-24_W7.62mm_Socket_LongPads

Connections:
A0: U12.2 (I2); also elsewhere on the board
A1: U12.3 (I3); also elsewhere on the board
A2: U12.4 (I4); also elsewhere on the board
A3: U12.5 (I5); also elsewhere on the board
A4: U12.6 (I6); also elsewhere on the board
A5: U12.7 (I7); also elsewhere on the board
A6: U12.8 (I8); also elsewhere on the board
A7: U12.9 (I9); also elsewhere on the board
A8: U13.21 (IO21); also elsewhere on the board
A9: U13.22 (IO22); also elsewhere on the board
A10: U13.2 (I2); also elsewhere on the board
A11: U13.3 (I3); also elsewhere on the board
A12: U13.4 (I4/PD); also elsewhere on the board
A13: U13.5 (I5); also elsewhere on the board
A14: U13.6 (I6); also elsewhere on the board
A15: U6.1 (I1/CLK), U13.7 (I7); also elsewhere on the board
A16: U6.2 (I2), U13.8 (I8); also elsewhere on the board
A17: U6.3 (I3), U13.9 (I9); also elsewhere on the board
A18: U6.4 (I4), U13.10 (I10); also elsewhere on the board
A19: U6.5 (I5), U13.11 (I11); also elsewhere on the board
A20: U6.6 (I6), U13.14 (IO14); also elsewhere on the board
A21: U6.7 (I7), U13.1 (CLK/I1); also elsewhere on the board
A22: U6.8 (I8), U13.13 (I13); also elsewhere on the board
A23: U6.9 (I9), U13.23 (IO23); also elsewhere on the board
BUS: U13.18 (IO18), U14.7 (I7)
BUSAK: U14.17 (I03); also elsewhere on the board
CS_RAM: U13.16 (IO16); also elsewhere on the board
CS_ROM: U13.15 (IO15); also elsewhere on the board
CS_UART: U12.19 (IO1); also elsewhere on the board
CS_VDP: U12.17 (I03); also elsewhere on the board
CS_VIA1: U12.15 (IO5); also elsewhere on the board
CS_VIA2: U12.14 (IO6); also elsewhere on the board
DATA_DIR: U14.14 (IO6); also elsewhere on the board
GND: U6.10 (GND), U12.10 (GND), U13.12 (GND), U14.10 (GND); also elsewhere on the board
IO: U12.1 (I1/CLK), U13.17 (IO17), U14.6 (I6)
ML: U14.5 (I5); also elsewhere on the board
O1_ROM: U13.19 (IO19); also elsewhere on the board
RD: U14.16 (IO4); also elsewhere on the board
RW: U14.2 (I2); also elsewhere on the board
VCC: U6.20 (VCC), U12.20 (VCC), U13.24 (VCC), U14.20 (VCC); also elsewhere on the board
VDA: U12.12 (IO8), U14.3 (I3); also elsewhere on the board
VIDEO_WINDOW: U6.19 (IO1); also elsewhere on the board
VP: U14.8 (I8); also elsewhere on the board
VPA: U14.4 (I4); also elsewhere on the board
WR: U12.11 (I10/~OE), U14.15 (IO5); also elsewhere on the board
~RTC_CS: U12.16 (IO4); also elsewhere on the board

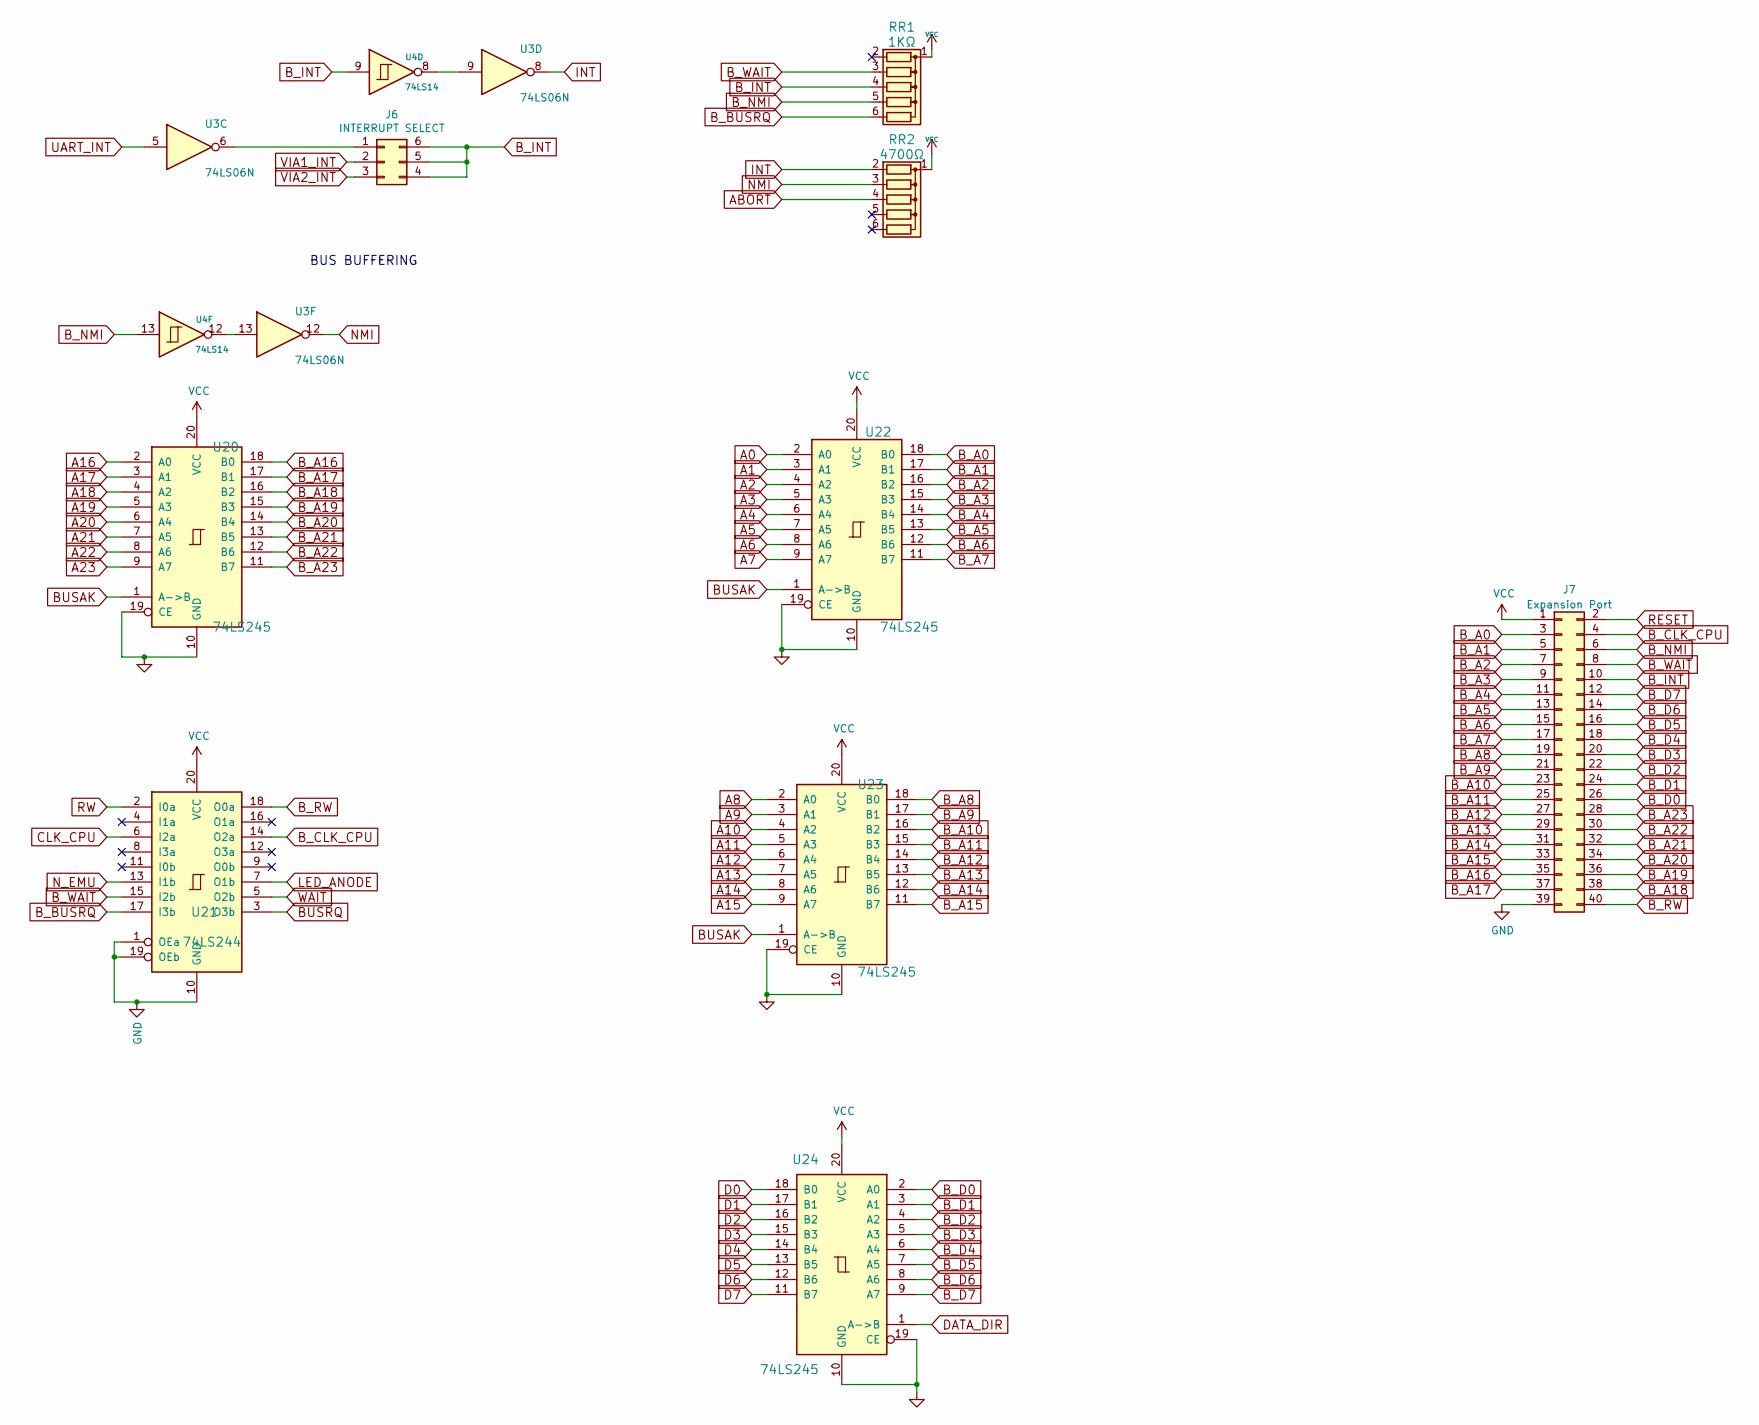
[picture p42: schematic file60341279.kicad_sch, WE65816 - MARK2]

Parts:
J6: INTERRUPT SELECT; PinHeader_2x04_P2.54mm_Vertical
J7: Expansion Port; PinSocket_2x20_P2.54mm_Horizontal
RR1: 1KΩ; R_Array_SIP6
RR2: 4700Ω; R_Array_SIP6
U3: 74LS06N; DIP-14_W7.62mm_Socket_LongPads
U4: 74LS14; DIP-14_W7.62mm_Socket_LongPads
U20, U22, U23, U24: 74LS245; DIP-20_W7.62mm_Socket_LongPads
U21: 74LS244; DIP-20_W7.62mm_Socket_LongPads

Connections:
A0: U22.2 (A0); also elsewhere on the board
A1: U22.3 (A1); also elsewhere on the board
A2: U22.4 (A2); also elsewhere on the board
A3: U22.5 (A3); also elsewhere on the board
A4: U22.6 (A4); also elsewhere on the board
A5: U22.7 (A5); also elsewhere on the board
A6: U22.8 (A6); also elsewhere on the board
A7: U22.9 (A7); also elsewhere on the board
A8: U23.2 (A0); also elsewhere on the board
A9: U23.3 (A1); also elsewhere on the board
A10: U23.4 (A2); also elsewhere on the board
A11: U23.5 (A3); also elsewhere on the board
A12: U23.6 (A4); also elsewhere on the board
A13: U23.7 (A5); also elsewhere on the board
A14: U23.8 (A6); also elsewhere on the board
A15: U23.9 (A7); also elsewhere on the board
A16: U20.2 (A0); also elsewhere on the board
A17: U20.3 (A1); also elsewhere on the board
A18: U20.4 (A2); also elsewhere on the board
A19: U20.5 (A3); also elsewhere on the board
A20: U20.6 (A4); also elsewhere on the board
A21: U20.7 (A5); also elsewhere on the board
A22: U20.8 (A6); also elsewhere on the board
A23: U20.9 (A7); also elsewhere on the board
ABORT: RR2.4 (R3); also elsewhere on the board
BUSAK: U20.1 (A->B), U22.1 (A->B), U23.1 (A->B); also elsewhere on the board
BUSRQ: U21.3 (O3b); also elsewhere on the board
B_A0: J7.3, U22.18 (B0)
B_A1: J7.5, U22.17 (B1)
B_A2: J7.7, U22.16 (B2)
B_A3: J7.9, U22.15 (B3)
B_A4: J7.11, U22.14 (B4)
B_A5: J7.13, U22.13 (B5)
B_A6: J7.15, U22.12 (B6)
B_A7: J7.17, U22.11 (B7)
B_A8: J7.19, U23.18 (B0)
B_A9: J7.21, U23.17 (B1)
B_A10: J7.23, U23.16 (B2)
B_A11: J7.25, U23.15 (B3)
B_A12: J7.27, U23.14 (B4)
B_A13: J7.29, U23.13 (B5)
B_A14: J7.31, U23.12 (B6)
B_A15: J7.33, U23.11 (B7)
B_A16: J7.35, U20.18 (B0)
B_A17: J7.37, U20.17 (B1)
B_A18: J7.38, U20.16 (B2)
B_A19: J7.36, U20.15 (B3)
B_A20: J7.34, U20.14 (B4)
B_A21: J7.32, U20.13 (B5)
B_A22: J7.30, U20.12 (B6)
B_A23: J7.28, U20.11 (B7)
B_BUSRQ: RR1.6 (R5), U21.17 (I3b)
B_CLK_CPU: J7.4, U21.14 (O2a)
B_D0: J7.26, U24.2 (A0)
B_D1: J7.24, U24.3 (A1)
B_D2: J7.22, U24.4 (A2)
B_D3: J7.20, U24.5 (A3)
B_D4: J7.18, U24.6 (A4)
B_D5: J7.16, U24.7 (A5)
B_D6: J7.14, U24.8 (A6)
B_D7: J7.12, U24.9 (A7)
B_INT: J6.4, J6.5, J6.6, J7.10, RR1.4 (R3), U4.9
B_NMI: J7.6, RR1.5 (R4), U4.13
B_RW: J7.40, U21.18 (O0a)
B_WAIT: J7.8, RR1.3 (R2), U21.15 (I2b)
D0: U24.18 (B0); also elsewhere on the board
D1: U24.17 (B1); also elsewhere on the board
D2: U24.16 (B2); also elsewhere on the board
D3: U24.15 (B3); also elsewhere on the board
D4: U24.14 (B4); also elsewhere on the board
D5: U24.13 (B5); also elsewhere on the board
D6: U24.12 (B6); also elsewhere on the board
D7: U24.11 (B7); also elsewhere on the board
DATA_DIR: U24.1 (A->B); also elsewhere on the board
GND: J7.39, U20.10 (GND), U20.19 (CE), U21.1 (OEa), U21.10 (GND), U21.19 (OEb), U22.10 (GND), U22.19 (CE), U23.10 (GND), U23.19 (CE), U24.10 (GND), U24.19 (CE); also elsewhere on the board
INT: RR2.2 (R1), U3.8; also elsewhere on the board
LED_ANODE: U21.7 (O1b); also elsewhere on the board
NMI: RR2.3 (R2), U3.12; also elsewhere on the board
N_EMU: U21.13 (I1b); also elsewhere on the board
unnamed: J6.1, U3.6
unnamed: U3.9, U4.8
unnamed: U3.13, U4.12
RESET: J7.2; also elsewhere on the board
RW: U21.2 (I0a); also elsewhere on the board
UART_INT: U3.5; also elsewhere on the board
VCC: J7.1, RR1.1 (common), RR2.1 (common), U20.20 (VCC), U21.20 (VCC), U22.20 (VCC), U23.20 (VCC), U24.20 (VCC); also elsewhere on the board
VIA1_INT: J6.2; also elsewhere on the board
VIA2_INT: J6.3; also elsewhere on the board
WAIT: U21.5 (O2b); also elsewhere on the board

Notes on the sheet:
BUS BUFFERING

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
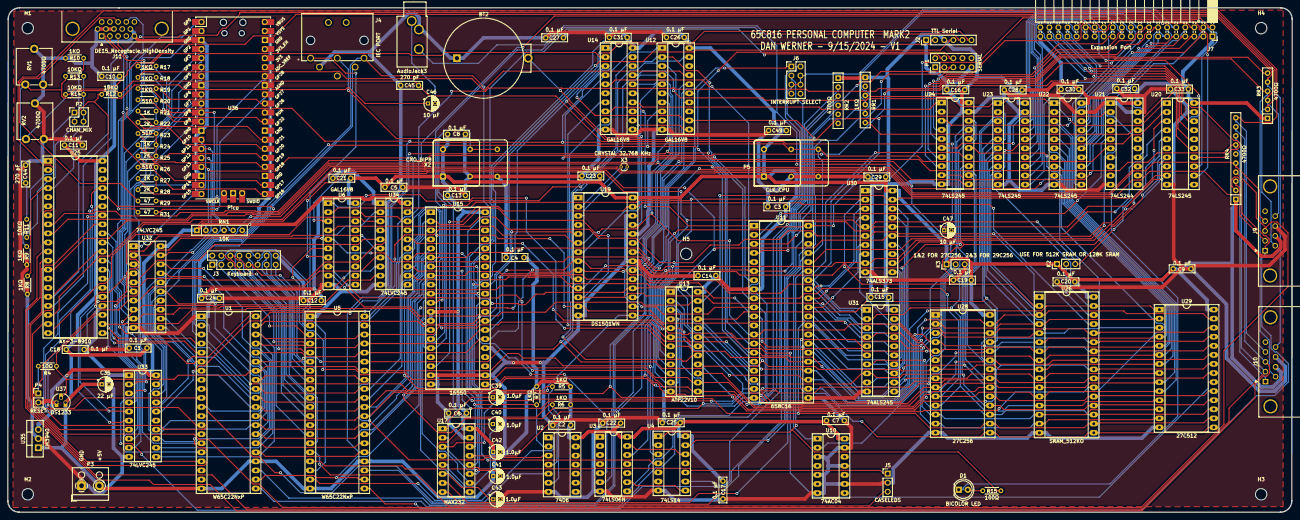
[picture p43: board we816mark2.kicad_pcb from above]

Board: 2 copper layers, 360.1 x 141.4 mm, 136 parts (0 on the bottom side), 228 nets.

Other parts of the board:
X4: CXO_DIP14; Oscillator_DIP-14

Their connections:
GND: X4.7 (GND); also elsewhere on the board
VCC: X4.1 (EN), X4.14 (Vcc); also elsewhere on the board

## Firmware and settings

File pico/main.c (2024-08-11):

#include <pico/stdlib.h>
#include <pico/multicore.h>
#include "abus.h"
#include "board_config.h"
#include "config.h"
#include "render.h"
#include "vga.h"
#include "buffers.h"


static void core1_main() {
    vga_init();
    render_loop();
}

static inline bool set_sys_clock_khz(uint32_t freq_khz, bool required) {
    uint vco, postdiv1, postdiv2;
    if (check_sys_clock_khz(freq_khz, &vco, &postdiv1, &postdiv2)) {
        set_sys_clock_pll(vco, postdiv1, postdiv2);
        return true;
    } else if (required) {
        panic("System clock of %u kHz cannot be exactly achieved", freq_khz);
    }
    return false;
}

int main() {
    // Adjust system clock for better dividing into other clocks
    set_sys_clock_khz(CONFIG_SYSCLOCK * 1000, true);

    // Setup the on-board LED for debugging
    gpio_init(PICO_DEFAULT_LED_PIN);
    gpio_set_dir(PICO_DEFAULT_LED_PIN, GPIO_OUT);

    config_load();

    multicore_launch_core1(core1_main);

    abus_init();
    abus_loop();
}

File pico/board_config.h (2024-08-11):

#pragma once

//#define CONFIG_SYSCLOCK 126.0 /* MHz */
#define CONFIG_SYSCLOCK 189.0 /* MHz */

// Pin configuration
#define CONFIG_PIN_APPLEBUS_DATA_BASE 0 /* 8+2 pins */
#define CONFIG_PIN_APPLEBUS_DEVSEL (CONFIG_PIN_APPLEBUS_DATA_BASE + 8)
#define CONFIG_PIN_APPLEBUS_RW (CONFIG_PIN_APPLEBUS_DATA_BASE + 9)
#define CONFIG_PIN_APPLEBUS_SYNC 10
#define CONFIG_PIN_APPLEBUS_CONTROL_BASE 11 /* 3 pins */
#define CONFIG_PIN_APPLEBUS_PHI0 26
#define CONFIG_PIN_HSYNC 28
#define CONFIG_PIN_VSYNC 27
#define CONFIG_PIN_RGB_BASE 14 /* 9 pins */

// Other resources
#define CONFIG_VGA_PIO pio0
#define CONFIG_VGA_SPINLOCK_ID 31
#define CONFIG_ABUS_PIO pio1

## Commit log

2024-07-17 mark 2 work
    [file5FFCADA1.kicad_sch, file5FFCBF10.kicad_sch, file5FFCD08B.kicad_sch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]
2024-07-20 pcb work
    [file5FFCADA1.kicad_sch, file5FFCBF10.kicad_sch, file5FFCD08B.kicad_sch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]
2024-08-11 initial pico firmware
    [ROMBIOS816.obj, file5FFCADA1.kicad_sch, file5FFCBF10.kicad_sch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]
2024-08-11 graphics work
    [file5FFCADA1.kicad_sch, file5FFCBF10.kicad_sch, file5FFCD08B.kicad_sch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]
2024-08-18 BASIC work
    [DBASIC816.obj, file60340596.kicad_sch, rom816.cfg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]
2024-08-28 relocate rom
    [rom816.cfg]
2024-09-02 BASIC graphics work
    [file5FFCADA1.kicad_sch, file5FFCE1F7.kicad_sch, file60340596.kicad_sch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]
2024-09-02 add plot commands to BASIC
    [we816mark2-B_Mask.gbs, we816mark2-B_Silkscreen.gbo, we816mark2-Component.gtl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]
2024-09-07 rtc updates
    [WE816case.scad, WE816case_top.stl, file5FFCADA1.kicad_sch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]
2024-09-16 add basic RTC functions
    [file5FFCADA1.kicad_sch, file5FFCBF10.kicad_sch, file5FFCD08B.kicad_sch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]
